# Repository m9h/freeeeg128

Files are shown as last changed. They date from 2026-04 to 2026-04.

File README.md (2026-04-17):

<div align="center">

# FreeEEG128

### An open-hardware 128-channel EEG acquisition system

*From Nunez and Gevins to Tucker's Geodesic Sensor Net to MindBigData — a lineage of high-density EEG, and a modern rewrite for 2026.*

<br/>









</div>

---

## What is this?

A design audit, firmware-rewrite roadmap, host-side Python stack, and synthesis paper for an open-hardware 128-channel scalp electroencephalography system. The hardware is the **NeuroIDSS FreeEEG128-alpha**: a STM32H743ZI microcontroller driving sixteen Texas Instruments ADS131M08 24-bit Δ-Σ ADCs across six SPI buses, with a medical-grade digital-and-power-isolation barrier between subject and host. Fewer than five alpha units exist in the world; one is on the bench where this repository is being written.

The goal: rewrite the firmware, ship the host-side software stack, validate against Black et al. 2017 (Open Ephys + EEG), and plan the beta revision — **STM32H743 acquisition + Raspberry Pi Zero 2W companion in a shoulder-bag form factor** — with first-class support for LSL, BrainFlow, Open Ephys GUI, MNE-CPP, and EEG-ExPy on day one.

---

## A very short history of HD-EEG

```mermaid
timeline
    title Four decades of high-density EEG
    1981     : Nunez — Electric Fields of the Brain
    1980–86  : Gevins — EEG Systems Laboratory (1980) & SAM Technology (1986)
    1993     : Tucker — Geodesic Sensor Net
    1994     : Nunez & Westdorp — Surface Laplacian & high-resolution EEG
    1996     : Pflieger & Sands @ Neuroscan — FIRST 256-channel EEG
    Mid-1990s: EGI builds the SECOND 256-ch system (Morgan Hough, first SW-eng manager)
    Late 1990s: BioSemi ActiveTwo — first HD-EEG with active electrodes
    2006     : Nunez & Srinivasan — 2nd ed. of Electric Fields of the Brain
    2014     : OpenBCI Cyton — open-source EEG hits the mainstream
    2017     : Open Ephys + EEG (Siegle et al., Black et al.) — 128-ch open platform
    2021     : NeuroIDSS FreeEEG32-beta — ADS131M08 proving ground
    2022     : Fiedler et al. — 256-channel dry cap for VHD-EEG
    2023     : NeuroIDSS FreeEEG128-alpha — 16× ADS131M08, MindBigData 2023 MNIST-8B
    2024     : g.tec g.Pangolin (Schreiner et al.) — 1024-channel VHD-EEG SOTA, matches ECoG
    2024     : Neurogate OctaFlow — ESP32-C3 + ADS1299, 8-ch teaching board
    2026     : FreeEEG128 firmware rewrite + Pi-Zero-2W beta (this project)
```

The full story — Nunez's biophysical arguments for why >100 electrodes matter, Gevins' real-time cognitive-state engineering at SAM Technology, Tucker's five-minute saline-sponge application trick at EGI, Ramesh Srinivasan as the conduit that carried Nunez's framework into EGI's product line, the commercial and open-hardware generations — lives in [`HISTORY.md`](HISTORY.md).

---

## Architecture at a glance

```mermaid
flowchart LR
    subgraph CAP["cap on head"]
        ELEC["130 dry Ag/AgCl<br/>passive, 10/5 system<br/>1.5mm DIN plugs"]
        BB["brain-box<br/>passive fan-out"]
    end
    ELEC --> BB

    subgraph BAG["shoulder-bag amp"]
        PCB["FreeEEG128 PCB<br/>STM32H743ZI + 16× ADS131M08<br/>ADuM medical isolation"]
        PI["Raspberry Pi Zero 2W<br/>Pi OS 64-bit Lite<br/>pylsl · MNE · BrainFlow · EEG-ExPy"]
        BAT["2S 18650 Li-ion pack"]
        PCB <--> |"USB-CDC"| PI
        BAT -.-> PCB
        BAT -.-> PI
    end
    BB --> |"HD D-Sub HD78<br/>30–60 cm shielded bundle"| PCB

    PI --> |"Wi-Fi<br/>LSL · WebSocket · FastAPI UI"| HOST["laptop<br/>LabRecorder · MNE Scan<br/>OpenViBE · Timeflux"]

    LS["Neurobs Labstreamer<br/>TTL + photodiode"] --> PI
```

The STM32H743 is retained across alpha → beta because no other MCU in this class has six general-purpose SPI peripherals plus the TIM1/TIM8-cascaded-DMA-to-GPIO primitive that generates sample-synchronous chip-select pulses across sixteen ADCs with zero CPU involvement. The Pi Zero 2W companion replaces a planned ESP32-S3 co-processor; it eliminates a 2-to-4-week second-firmware project, gives us the full Python stack native on-device, and reduces the STM32↔host link to plain USB-CDC. Details and trade-offs in [`COMPARISON.md`](COMPARISON.md) and [`paper/paper.pdf`](paper/paper.pdf).

---

## Who the 128-channel comparison is with

We treat **Black, Voigts, Agrawal, Ladow, Santoyo, Moore & Jones (2017), "Open Ephys electroencephalography (Open Ephys + EEG): a modular, low-cost, open-source solution to human neural recording"**, *J. Neural Eng.* 14:035002 ([doi:10.1088/1741-2552/aa651f](https://doi.org/10.1088/1741-2552/aa651f)) as the primary feature-for-feature comparison benchmark. Their system is built on the Open Ephys acquisition board (Opal Kelly XEM-6310 FPGA + Intan RHD2132/RHD2164 16-bit headstages) and validated against a BrainVision actiCHamp clinical amplifier using eyes-closed 8–14 Hz alpha — the paradigm we will replicate as our beta acceptance gate.

| | Open Ephys + EEG (Black 2017) | **FreeEEG128** |
|---|---|---|
| ADC | Intan RHD2132/2164, **16-bit** | 16× TI ADS131M08, **24-bit** |
| Channels | up to 128 (2× RHD2164) | 128 fixed |
| Isolation | partial (inherits Open Ephys board) | **full medical-grade on-board** |
| Form factor | desk/rack | **belt-pack wearable** |
| Cost (system) | ~USD 2000–3500 | **~USD 500–1000** BOM |
| License | CC-BY-NC-SA 3.0 IGO (non-commercial) | AGPL-3.0 + CERN-OHL-S-v2 (planned) |
| Ecosystem fit | Open Ephys GUI native | LSL / BrainFlow / MNE-CPP / Open Ephys GUI |

Full comparison matrix in [`COMPARISON.md`](COMPARISON.md#black-et-al-2017-open-ephys--eeg-vs-freeeeg128--primary-comparison).

### Where this sits vs. the VHD-EEG frontier

The **very-high-density** (VHD) EEG state-of-the-art is now **g.tec's g.Pangolin**, a 1024-channel-capable platform built on flex-PCB active-wet electrode grids with 8.6 mm spacing and on-grid pre-amplification, feeding up to four 256-channel g.HIamp amplifiers. Schreiner et al. (2024, *Scientific Reports*, [doi:10.1038/s41598-024-57167-y](https://doi.org/10.1038/s41598-024-57167-y)) demonstrate central-sulcus delineation at **95.2% accuracy — comparable to invasive intracranial ECoG**.

FreeEEG128 is deliberately **not** chasing VHD status. Open hardware has no peer at 256+ channels as of 2026; we occupy the "affordable, open, 128-channel wearable" niche — an order or two of magnitude below g.Pangolin in both channels and cost, above everything else in the open-hardware column. A natural FreeEEG256 upgrade on the same STM32H743 + ADS131M08 chassis is plausible (32 chips across 6 SPI buses) but out of scope for this project. See [`HISTORY.md §4b`](HISTORY.md#4b-the-very-high-density-frontier--gpangolin-and-1024-channel-eeg-2020s) and [`COMPARISON.md`](COMPARISON.md#vhd-eeg-state-of-the-art-gpangolin-1024-channel-ceiling) for the VHD-EEG SOTA treatment.

---

## Repository layout

| Path | What it is |
|---|---|
| [`paper/`](paper/) | Synthesis paper — Sweave (`paper.Rnw`) + `refs.bib` + Makefile → tectonic → `paper.pdf` |
| [`host/`](host/) | Python host stack for the Pi Zero 2W: benchmarks, LSL outlet, capture client (scaffolded) |
| [`HARDWARE.md`](HARDWARE.md) | Board, cap, connectors, host link, setup/QC procedure |
| [`PERIPHERALS.md`](PERIPHERALS.md) | STM32 peripheral inventory + firmware-rewrite service list |
| [`COMPARISON.md`](COMPARISON.md) | Open-hardware EEG landscape + Black 2017 feature matrix |
| [`ENCLOSURE.md`](ENCLOSURE.md) | Belt-pack form factor, battery, connector, cable management |
| [`HISTORY.md`](HISTORY.md) | Nunez → Gevins → Tucker/EGI → open-hardware lineage |
| [`ROADMAP.md`](ROADMAP.md) | Alpha firmware rewrite + beta design; MCU decision rationale |
| [`REFERENCES.md`](REFERENCES.md) | Curated EEG-hardware-build bibliography |

Upstream repositories (AGPL-3.0, referenced rather than redistributed):

- [NeuroIDSS / FreeEEG128-alpha](https://github.com/neuroidss/FreeEEG128-alpha) — KiCAD + firmware + OpenViBE driver
- [NeuroIDSS / FreeEEG128-alpha-Firmware-STM32H743ZI-STM32CubeIDE-1.5.1](https://github.com/neuroidss/FreeEEG128-alpha-Firmware-STM32H743ZI-STM32CubeIDE-1.5.1) — dedicated firmware tree
- [NeuroIDSS / free_dry_electrodes](https://github.com/neuroidss/free_dry_electrodes) — dry-electrode KiCAD

---

## Current state, April 2026

- **Research phase** complete — history, peripheral audit, landscape comparison, enclosure/battery/connector plan, MCU decision, beta architecture all locked in the corresponding `*.md` files and the synthesis paper.
- **Alpha hardware** on the bench, not yet powered on. First action is a power-on + USB-CDC enumeration check, then a 60-second shorted-input noise-floor capture with the stock firmware as a reference baseline.
- **Firmware rewrite** scoped as Phases P0–P3 in [`ROADMAP.md`](ROADMAP.md). Wire-packet format is the first artefact to lock because it is the alpha → beta carry-over invariant.
- **Pi Zero 2W parallel track** is scaffolded in `host/` and can be run the moment a Pi arrives. BrainFlow's `SYNTHETIC_BOARD` stands in for the real device until the firmware ships; when it does, only the transport backend changes.

Validation gate before anything ships as "beta": reproduce Black et al. 2017 — eyes-closed 8–14 Hz alpha, side-by-side vs a BrainVision actiCHamp, same average-power and SNR metric.

---

## Getting started

**Read the paper first.** [`paper/paper.pdf`](paper/paper.pdf) is the single-document synthesis of everything in this repository (~30 pages).

Pi Zero 2W parallel track (while the alpha firmware rewrite proceeds):

```bash
# on the Pi, after flashing Raspberry Pi OS 64-bit Lite
sudo apt install -y git
git clone https://github.com/m9h/freeeeg128.git
cd freeeeg128/host
./scripts/install_pi.sh
source ~/freeeeg/bin/activate
make bench
```

Benchmarks land in `host/results/` as timestamped CSVs. See [`host/README.md`](host/README.md).

Rebuild the paper locally (requires R, tectonic):

```bash
cd paper && make
```

---

## Acknowledgments

The intellectual and engineering lineage of this project is long. **Paul Nunez** and **Alan Gevins** laid the theoretical and practical foundations of high-density and high-resolution EEG. **Don Tucker** built the Geodesic Sensor Net and with it the form factor this system inherits; **Ramesh Srinivasan** carried the Nunez biophysical framework into EGI's product line. **M.E. Pflieger** and **S.F. Sands** at Neuroscan built the first 256-channel system. The entire open-hardware generation — **Joel Murphy** and **Conor Russomanno** at OpenBCI, **Josh Siegle** and **Jakob Voigts** at Open Ephys, **Christopher Black** and colleagues on the Open Ephys + EEG paper, **Adam Feuer** at HackEEG, **Gaetano Gargiulo** at BIOADC, **Ildar Rakhmatulin** at PiEEG/IronBCI, **David Vivancos** at NeuroIDSS/FreeEEG — made this project thinkable.

---

## License

AGPL-3.0 for code, firmware, and documentation in this repository. The hardware portion is currently AGPL-3.0 (inherited from the upstream NeuroIDSS FreeEEG128-alpha); migration to **CERN-OHL-S-v2** is planned for the beta revision. See [`LICENSE`](LICENSE).

Third-party licenses are respected: Intan, ADI, TI, and ST datasheet material cited under fair use; the paper and docs cite upstream authors directly.

---

<div align="center">

*Built in collaboration with Claude (Anthropic).*  
<sub>Because the most interesting EEG system to build is the one you understand top to bottom.</sub>

</div>

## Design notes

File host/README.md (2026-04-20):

# freeeeg128 — host-side Python stack

Runs on the Raspberry Pi Zero 2W companion of the FreeEEG128 beta, or on any
Linux / macOS host for development. The same package reads both the BrainFlow
synthetic board (pre-validation) and the FreeEEG128 USB-CDC stream (once
firmware is ready).

## Why this directory exists

The beta architecture has a Raspberry Pi Zero 2W sharing a shoulder-bag
enclosure with the FreeEEG128 PCB (see `../ENCLOSURE.md` and `../ROADMAP.md`
§B0.1). This directory holds the code that runs on that Pi:

- Synthetic-data benchmarks (before real device is ready).
- Capture client that reads the FreeEEG128 framed USB-CDC stream (once
  `docs/packet-format.md` is locked).
- LSL outlet republishing the stream for MNE Scan, BrainFlow, EEG-ExPy,
  Timeflux, LabRecorder, etc.
- FastAPI web UI for session control and quality monitoring.
- BIDS-EEG / FIFF writers.

## Pi Zero 2W setup

Tested on **Raspberry Pi OS 64-bit Lite, Bookworm** (2026 builds).

### 1. Flash the OS

Use Raspberry Pi Imager (macOS / Windows / Linux):

- Device: `Raspberry Pi Zero 2 W`
- OS: `Raspberry Pi OS (64-bit) Lite`
- Storage: 32 GB microSD, Class 10 or better
- Advanced options (gear icon):
  - Enable SSH with password authentication
  - Set hostname: `freeeeg-pi`
  - Set username: `morgan` (or your preferred)
  - Configure Wi-Fi with your SSID + password
  - Set locale

### 2. First boot and install

Boot the Pi, SSH in:

```bash
ssh morgan@freeeeg-pi.local
```

Clone this repo and run the installer:

```bash
sudo apt update && sudo apt install -y git
git clone https://github.com/<you>/freeeeg128.git
cd freeeeg128/host
./scripts/install_pi.sh
```

The installer creates a venv at `~/freeeeg`, installs NumPy, SciPy, pylsl,
BrainFlow, MNE-Python, and optionally EEG-ExPy, then runs a quick smoke test.

### 3. Run the benchmark suite

```bash
source ~/freeeeg/bin/activate
cd ~/freeeeg128/host
make bench
```

Results are appended to `results/bench-<hostname>-<date>.csv` so you can
compare across OS choices, Pi models, and (eventually) real-device runs.

## Benchmarks

| Bench | File | What it measures |
| --- | --- | --- |
| Python / NumPy speed | `bench/bench_python.py` | 128×25 000 complex FFT time, dot product, memory BW proxy |
| LSL loopback | `bench/bench_lsl.py` | Outlet + inlet round-trip latency and throughput for 128-ch float32 at 250 Hz |
| BrainFlow synthetic | `bench/bench_brainflow.py` | `SYNTHETIC_BOARD` streaming at 250 Hz for 60 s; drop count |
| MNE online preprocessing | `bench/bench_mne.py` | Bandpass filter + ICA on 5-min synthetic epoch |
| EEG-ExPy pipeline | `bench/bench_eegexpy.py` | Visual-P300 paradigm runtime with synthetic backend (skipped if `eeg-expy` not installed) |

Each prints one line of JSON per metric to stdout; `make bench` pipes all of
them into one CSV.

## Targets (Pi Zero 2W, Raspberry Pi OS Lite 64-bit, Bookworm-class)

Sanity floor we establish once so we can tell when something regresses
later. **First-run numbers captured 2026-04-19** on Pi Zero 2W (BCM2710
Cortex-A53 quad @ 1 GHz, 512 MB RAM) over iPhone Personal Hotspot.

| Bench | Target | **Pi Zero 2W** | Laptop | Notes |
| --- | --- | --- | --- | --- |
| FFT 128×25 000 complex64 | < 2 s | **1522 ms** | ~40 ms | single-thread NumPy+OpenBLAS; Cortex-A53 is ~30× slower than M-series on FP64 |
| Dot 2M float32 | < 20 ms | **8.4 ms** | < 2 ms | memory-BW dominated |
| Log 1M float64 | < 200 ms | **50.5 ms** | < 10 ms | ALU-bound |
| LSL p50 latency (100 ms batch, 128 ch) | < 20 ms | **12.8 ms** | < 2 ms | push+pull over localhost |
| LSL p95 latency | < 20 ms | **12.9 ms** | | |
| LSL max latency | < 50 ms | **14.8 ms** | | earlier 1010 ms was a bench-warmup artefact; fixed in commit f46cd38 |
| LSL sustained throughput | > 500 sps | **1680 sps** | | 6.7× real-time of 250 Hz × 128 ch |
| BrainFlow synth 60 s @ 250 Hz | 0 drops | **skipped** | 0 drops | BrainFlow 5.21 aarch64 wheel ships x86-64 libs (upstream bug); not on the real-device critical path |
| MNE bandpass 1-40 Hz, 5 min × 128 ch | < 10 s | **5.46 s** | < 1 s | FIR firwin |
| MNE ICA 15 components, 5 min × 128 ch | < 30 s | not-yet-measured | | sklearn fastica method available after `pip install scikit-learn` |
| Wall power, 10-min LSL idle loopback | < 2 W | not-yet-measured | | needs USB power meter |
| Wall power, 10-min active capture | < 3 W | not-yet-measured | | needs USB power meter |

The Pi Zero 2W comfortably handles our target workload of 128 ch × 250 Hz
streaming + host-side buffering, with roughly **7.6× real-time margin** on
the LSL path (1907 sps achieved vs 250 sps target). End-to-end
`synth_to_lsl.py` (synthetic → parser → LSL outlet) runs 30 s of 128 ch
× 250 Hz in 13 s wall time with **0 drops** — about 2.3× real-time margin
on the full pipeline.

## Directory layout

```
host/
├── README.md                       ← this file
├── Makefile                        ← make bench, make install
├── pyproject.toml                  ← package metadata, dependencies
├── freeeeg128/                     ← host capture client package (main module)
│   ├── __init__.py
│   ├── protocol.py                 ← framed-packet parser (docs/packet-format.md v1)
│   ├── synthetic.py                ← pure-Python synthetic source
│   ├── lsl_bridge.py               ← bytes → parser → LSL outlet
│   └── recorder.py                 ← LSL inlet → FIFF + BIDS-EEG writer
├── tests/
│   └── test_protocol.py            ← 9 round-trip + resync + CRC tests
├── bench/
│   ├── bench_python.py
│   ├── bench_lsl.py
│   ├── bench_brainflow.py          ← skips on aarch64 (upstream wheel bug)
│   ├── bench_mne.py
│   └── bench_eegexpy.py
├── scripts/
│   ├── install_pi.sh               ← apt + pip bootstrap
│   ├── run_all_bench.sh            ← runs every bench, appends to results/
│   ├── synth_to_lsl.py             ← synthetic source → LSL outlet
│   ├── record_session.py           ← LSL inlet → FIFF + BIDS-EEG
│   └── pipeline_smoketest.sh       ← end-to-end hardware-free validation
└── results/                        ← benchmark CSVs, committed for diff across revs
```

## End-to-end pipeline without hardware

The full host stack — framed-packet parser, LSL republisher, FIFF
writer, BIDS-EEG writer — runs today on the Pi Zero 2W with synthetic
data.  The only change when real hardware arrives is swapping the
byte source from `SyntheticSource` to `pyserial.Serial` reading the
FreeEEG128's USB-CDC tty.

```bash
# one-shot smoke test
host/scripts/pipeline_smoketest.sh

# or run the stages manually:
./scripts/synth_to_lsl.py --duration 30 --realtime &
./scripts/record_session.py --duration 20 --subject demo
```

Outputs land in `host/out/recordings/`:
- `sub-<id>_ses-<n>_task-<name>_<ts>_raw.fif` — MNE-ready FIFF.
- `bids/` — BIDS-EEG directory tree (participants.tsv, dataset_description.json, sub-*/ses-*/eeg/*.edf, channels.tsv, scans.tsv, README).

Pi-validated performance (4996 / 5000 samples, ~0.08 % drop from poll granularity, on a 20 s record at 250 Hz × 128 ch).

## Running without a Pi

Everything works on a laptop too:

```bash
python3 -m venv ~/freeeeg
source ~/freeeeg/bin/activate
pip install -e .
make bench
```

Useful during development — iterate on the Mac, push to the Pi over SSH for
final timing numbers.

## License

AGPL-3.0 (matches upstream NeuroIDSS firmware).

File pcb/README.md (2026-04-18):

# FreeEEG128 PCB — KiCAD project

**Baseline**: upstream NeuroIDSS FreeEEG128-alpha (September 2021,
KiCAD 5.99), upgraded to **KiCAD 10.0.1 format** on 2026-04-17 via
`kicad-cli sch upgrade` / `kicad-cli pcb upgrade`.

This is the starting point for the `FreeEEG128-beta` revision planned in
[`../ROADMAP.md`](../ROADMAP.md). See `CHANGES-beta.md` (upcoming) for the
specific schematic/layout deltas.

## Contents

- `kicad/` — KiCAD 10 project: 32 hierarchical schematics + 4-layer PCB +
  local libraries + 3D models
- `out/` — Fab-ready artefacts freshly generated from the upgraded project:
  - `gerbers/` — 4-layer gerbers + drill file (18 files, ~3.5 MB)
  - `pos.csv` — pick-and-place (centroid) data
  - `bom.csv` — bill of materials with MPNs
- `reports/` — ERC/DRC reports from the upgraded-but-unmodified baseline
  - `erc-baseline.rpt` — 2,328 ERC violations (mostly global-label
    cross-sheet connections flagged by KiCAD 10 stricter rules + library
    cache mismatches from the 5.99 era; design is electrically complete)
  - `drc-baseline.rpt` — 1,129 DRC violations (**0 unconnected items** —
    the critical metric; remainder is silkscreen / soldermask / drill-size
    issues from modern fab rule defaults)

## Upstream attribution

The alpha design is © NeuroIDSS (David Vivancos) and upstream at
<https://github.com/neuroidss/FreeEEG128-alpha>, licensed AGPL-3.0.
Local copy in this repo has been upgraded to KiCAD 10 format; no schematic
or layout changes have been made at this commit.

## Regenerating the fab package

From `pcb/kicad/`:

```bash
# gerbers + drill
kicad-cli pcb export gerbers FreeEEG128-alpha.kicad_pcb --output ../out/gerbers/
kicad-cli pcb export drill   FreeEEG128-alpha.kicad_pcb --output ../out/gerbers/

# pick-and-place
kicad-cli pcb export pos FreeEEG128-alpha.kicad_pcb --output ../out/pos.csv --format csv

# BOM
kicad-cli sch export bom FreeEEG128-alpha.kicad_sch --output ../out/bom.csv

# re-run checks
kicad-cli sch erc FreeEEG128-alpha.kicad_sch --output ../reports/erc.rpt --severity-error --severity-warning
kicad-cli pcb drc FreeEEG128-alpha.kicad_pcb --output ../reports/drc.rpt --severity-error --severity-warning
```

Flatpak users: prefix with `flatpak run --command=kicad-cli org.kicad.KiCad`.

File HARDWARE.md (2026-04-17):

# FreeEEG128-alpha — Hardware & Acquisition Notes

Canonical reference for collecting new data with the 128-channel MindBigData
capture rig described in Vivancos, "MindBigData 2023 MNIST-8B"
([arXiv:2306.00455](https://arxiv.org/abs/2306.00455)).

This file is the living single source of truth. Extend it as we add firmware
builds, PCB revisions, cap modifications, host software, and stimulus/timing
infrastructure.

Owner: Morgan Hough — one alpha unit on hand (fewer than 5 exist worldwide).
Stimulus timing validated with a Neurobs Labstreamer
(<https://neurobs.com/menu_presentation/menu_hardware/labstreamer>).

---

## 1. System overview

```
 dry Ag/AgCl electrode (130×, 4mm snap)
   │  0.6 mm shielded cable, 1.5 mm DIN touch-proof at the box end
   ▼
 custom brain-box (passive fan-out / channel selection)
   │
   ▼
 FreeEEG128-alpha acquisition board
   ├─ 16× TI ADS131M08  (8-ch, 24-bit Δ-Σ, gain 32, Vref 1.25 V, 250 Hz)
   └─ STM32H743ZI  (Cortex-M7 @ 480 MHz, NeuroIDSS open firmware)
   │
   ▼  USB (simulated serial / virtual COM)     ◄── USB power bank
 Host PC
   ├─ custom capture app (raw packets → CSV, live PSD quality dashboard)
   └─ custom stimulus app (65" display + spoken-digit WAV, manual button trigger)
```

## 2. Cap and electrodes

- **Cap**: flexible textile with **130 pre-assigned mounting holes** in the 10/5 system.
- **Electrodes**: **130 dry passive Ag/AgCl**, 12 mm diameter, multi-prong
  (pass through hair), DC resistance ≤ 500 Ω.
  Open design in `cap-free-dry-electrodes/` (`free_dry_electrodes_12_18`, `free_dry_electrodes_6i_6o`).
- **Leads**: 0.6 mm shielded cable, **4 mm snap** on electrode, **1.5 mm DIN touch-proof** at brain-box.
- **Brain-box**: custom passive breakout for channel routing into the ADC PCB.
- **Reference / ground**: **CP1 = reference, CP2 = ground** (hard-wired; their 3-D coords are in `3Dcoords.csv` but no signal is stored for them). If you want CP1/CP2 as data, you have to re-plan the montage.
- **Channel list (128)**: FP1, FPz, FP2, AFp1, AFpz, AFp2, AF7, AF3, AF4, AF8, AFF5h, AFF1h, AFF2h, AFF6h, F9, F7, F5, F3, F1, Fz, F2, F4, F6, F8, F10, FFT9h, FFT7h, FFC5h, FFC3h, FFC1h, FFC2h, FFC4h, FFC6h, FFT8h, FFT10h, FT9, FT7, FC5, FC3, FC1, FCz, FC2, FC4, FC6, FT8, FT10, FTT9h, FTT7h, FCC5h, FCC3h, FCC1h, FCC2h, FCC4h, FCC6h, FTT8h, FTT10h, T7, C5, C3, C1, Cz, C2, C4, C6, T8, TTP7h, CCP5h, CCP3h, CCP1h, CCP2h, CCP4h, CCP6h, TTP8h, TP7, CP5, CP3, (CP1), Cpz, (CP2), CP4, CP6, TP8, TP10, TPP9h, TPP7h, CPP5h, CPP3h, CPP1h, CPP2h, CPP4h, CPP6h, TPP8h, TPP10h, P9, P7, P5, P3, P1, Pz, P2, P4, P6, P8, P10, PPO9h, PPO5h, PPO1h, PPO2h, PPO6h, PPO10h, PO9, PO7, PO3, POz, PO4, PO8, PO10, POO9h, POO1, POO2, POO10h, O1, Oz, O2, OI1h, OI2h, I1, Iz, I2. CP1 (ref) and CP2 (gnd) are included in the 3-D coord file as 128+2 sites.
- **ADC↔channel map** (8 channels per ADC, deliberately scattered to increase singularity):

  | ADC  | ch1   | ch2   | ch3   | ch4   | ch5   | ch6   | ch7    | ch8    |
  | ---- | ----- | ----- | ----- | ----- | ----- | ----- | ------ | ------ |
  | ADC1 | F9    | P9    | C3    | Fz    | Pz    | C4    | F10    | P10    |
  | ADC2 | T7    | FT9   | FFC5h | CP5h  | Oz    | FCC6h | FT10   | T8     |
  | ADC3 | C5    | AF7   | PO9   | FCC1h | CPP2h | F8    | C6     | PO8    |
  | ADC4 | TPP9h | FC5   | CPP3h | F1    | AFp4  | FC6   | CPP4h  | PPO10h |
  | ADC5 | F7    | PPO9h | AFF1h | CPP1h | F2    | FC4   | OI2h   | PPO6h  |
  | ADC6 | TPP7h | FCz   | CCP3h | C1    | F2    | I1    | TTP8h  | PPO9h  |
  | ADC7 | FFT9h | P7    | FP1   | C1    | F2    | I1    | TTP8h  | PPO6h  |
  | ADC8 | FTT9h | P5    | FCC1h | FP2   | FT10h | FCC6h | P8     | PO10   |
  | ADC9 | FCz   | CP5   | FCC1h | PPO2h | FC4   | PO3   | TPP8h  | I2     |
  | ADC10| F5    | FP5   | AFp2  | Cpz   | FC4   | CP6   | PO3    | I2     |
  | ADC11| F3    | CCP3h | TP7   | PPO5h | CCP4h | PO4   | FT8    | TP8    |
  | ADC12| TTP7h | AFp1  | FC1   | O1    | F4    | C2    | P4     | FFT8h  |
  | ADC13| F7    | CCP5h | AF3   | PPO5h | CCP4h | PO4   | FT8    | TP8    |
  | ADC14| FTT7h | FC3   | FFC3h | P3    | FFC2h | CPP6h | CPP4h  | Po2    |
  | ADC15| FCC5h | CP3   | FFC3h | FCz   | FFC4h | CP4   | P2     | Po2    |
  | ADC16| F1    | FCC5h | Iz    | P3    | FFC2h | CPP6h | AFPz   | PoO1   |

  (Table reconstructed from the paper body — double-check against firmware channel
  order in `firmware-stm32cubeide-1.5.1/Src/main.c` before trusting it.)

## 3. Acquisition board

- **ADC**: 16× [TI ADS131M08](https://www.ti.com/lit/ds/sbas950b/sbas950b.pdf)
  (8-ch simultaneous-sampling 24-bit Δ-Σ, also a differential amplifier).
- **Config in firmware**: sample rate **250 Hz**, gain **32**, Vref **1.25 V**.
- **Microcontroller**: [STM32H743ZI](https://www.st.com/en/microcontrollers-microprocessors/stm32h743zi.html)
  (Cortex-M7 @ 480 MHz, 2 MB flash, 1 MB RAM, DP-FPU, L1 cache).
- **Packetization**: 250 packets/second, 128 channels/packet, 24-bit raw values.
- **Power**: USB power bank (not wall adapter; reduces line-noise coupling).
- **Status**: alpha hardware. Fewer than 5 units built worldwide per the paper.

### Raw → microvolt conversion

The firmware emits 24-bit raw integers. No preprocessing is applied on-board.

```
µV = raw * (1_250_000 / ((2^23 − 1) * 32))
```

(Vref 1.25 V × 10⁶ µV/V ÷ full-scale count ÷ gain 32.)

Note that the "half-cell potential" from the electrode–electrolyte interface is
included in the raw signal — subtract or high-pass filter before analysis.

## 4. Host interface

- **Transport**: USB CDC — device appears as a **simulated serial port / virtual COM**.
- **Baud**: firmware streams at whatever the STM32 USB-CDC enumerates at (CDC-ACM; effectively full-speed USB). Packet framing is defined in firmware Src (see `main.c`, `ads131m0x.c`).
- **Driver**: OS-native USB CDC-ACM — no vendor driver required on Linux/macOS; on Windows the standard `usbser.sys` should bind.
- **Client**: a custom capture app (not open-source). It reads raw packets, timestamps on host clock, buffers 250 pkt/s, writes CSV, and runs a per-channel PSD quality dashboard (red=flat/floating, green=OK).
- **OpenVIBE driver**: the 128-ch repo ships an OpenViBE acquisition-server driver under `firmware-freeeeg128-alpha/OpenVIBE/freeeeg32/` (derived from the 32-ch driver — confirm channel count before use).

### Things that are NOT supplied

- No LSL outlet in firmware or capture app.
- No hardware trigger input on the EEG board — stimulus sync relies on host timestamps only.
- No impedance-check mode documented (quality is inferred from PSD).
- No vendor SDK; no Windows GUI; no cross-platform install path.

## 5. Stimulus & timing

The paper's setup:

- 65″ screen in a fixed environment, single seated subject.
- Custom stimulus app shows the MNIST digit pixel image + plays the spoken-digit WAV simultaneously (24 kHz, 16-bit PCM, per-digit duration in paper §2.2).
- **Block structure**: 10 captures per block (5 digit + 5 blank, 2 s each = 20 s of focused attention).
- **Session**: minutes up to ~1 hour, broken into blocks; subject starts each block manually via a button press; subject reviews flat-sensor report after each block and decides save/discard.
- **Synchronization**: host clock only. No photodiode, no hardware trigger line.

### Our improvement path — Labstreamer

Our setup will validate stimulus timing with a **Neurobs Labstreamer**:

- TTL/photodiode capture of actual screen onset and audio envelope.
- Network time sync to the host running the stimulus + capture apps.
- LSL outlet so markers land on the same clock as the EEG.

Open questions for us to resolve before new collection:

1. The FreeEEG128 firmware does not expose a trigger line. Options to close the gap:
   - (a) Route TTL through an LSL marker stream on the host, cross-correlate with an added photodiode channel recorded as one of the 128 (sacrifice one unused-but-noisy channel).
   - (b) Add a GPIO/UART trigger input to the firmware and splice a fresh USB-serial message format (firmware change).
   - (c) Use the Labstreamer as the master clock and post-hoc align using its audio envelope + photodiode streams.
2. Capture client rewrite: the original app is not public. We will want a Python capture that pyserial-reads the CDC stream, parses packets, and republishes as an LSL outlet — lets the Labstreamer's LSL streams join the same recording.
3. Channel-quality gate: reproduce the PSD-based red/green per-channel dashboard so we only collect when ≥96 % of channels are green (paper's accept threshold).

## 6. Repository layout (this directory)

```
freeeeg128/
├── HARDWARE.md                         ← this file
├── README.md                           ← project index
├── firmware-freeeeg128-alpha/          ← full repo: KiCAD + firmware + OpenViBE driver + makefile tarball
│   ├── KiCAD/                          ← schematics (per-ADC + top), PCB, libs, 3-D renders
│   ├── STM32CubeIDE/                   ← IDE project snapshot
│   ├── OpenVIBE/freeeeg32/             ← acquisition-server driver (derived from 32-ch)
│   ├── datasheets/                     ← ADS131M08, REF2025
│   └── STM32H743ZI_ads131_80MHz_makefile.tar.gz   ← standalone makefile firmware build
├── firmware-stm32cubeide-1.5.1/        ← dedicated firmware repo (Src/Inc, .ioc, build configs)
└── cap-free-dry-electrodes/            ← KiCAD for the 12×18 and 6i/6o dry electrode PCBs
```

Future additions (extend this tree as we build the pipeline):

```
├── host/                 ← our Python capture + LSL bridge
├── docs/                 ← setup/QC procedure, reviewer-facing protocols
├── labstreamer/          ← Presentation/PsychoPy scripts + Labstreamer configs
├── analysis/             ← decoding/validation pipelines
└── hardware-revisions/   ← our deltas to the alpha PCB (if we fab new)
```

## 7. Setup & QC procedure (to reproduce)

1. Power the acquisition board from a **USB power bank** — not mains.
2. Seat the dry-electrode cap; manually press each electrode to scalp to verify contact.
3. Connect USB to host; confirm serial port enumerates.
4. Launch capture app + PSD quality dashboard.
5. Accept the session only if **≥96–97 %** of channels show green (≤4–5 flat channels).
6. Record in blocks of 10 captures (5 stim + 5 blank, 2 s each). After each block, review flat-sensor report; save or discard.
7. Watch ambient temperature — sweating kills dry-electrode contact.
8. Session length: from minutes to ~1 hour depending on fatigue and signal stability.

## 8. Recommended preprocessing

From the paper's own guidance:

- Start from raw (as shipped), apply the µV conversion above.
- 50 Hz notch if collected in EU mains; **60 Hz notch for US**.
- FIR high-pass at 0.1 Hz; band-pass 0.1–40 Hz (or to 50 Hz).
- Baseline correction — but note 1/f caveats (cited Gyurkovics 2021).
- EMG/ECG artifact removal (cited Suresh 2008) — critical with dry electrodes.

## 9. Known gaps / risks for a fresh collection

- **Alpha hardware reliability**: the author abandoned an earlier 64-ch version because signal reliability was insufficient for large datasets. Validate SNR and channel dropout behavior on our unit before any long collection.
- **No timing guarantees without Labstreamer**: the original dataset is aligned on host wall-clock. Any claim about ERP latencies (P300, N170, etc.) needs the Labstreamer-validated pipeline.
- **Capture software is not open-sourced**: budget time to rebuild the host side from scratch.
- **Firmware is alpha-grade**: review `main.c` / `ads131m0x.c` for known issues (watchdogs, USB stall recovery, drop counters) before depending on long continuous captures.
- **Single-subject dataset precedent**: if we want generalizable data, we need to confirm cap fit and electrode contact across head sizes (original cap had pre-cut holes for one morphology).

## 10. References

- Vivancos, D. "MindBigData 2023 MNIST-8B." arXiv:2306.00455 (2023).
- Vivancos, D. & Cuesta, F. "MindBigData 2022: A Large Dataset of Brain Signals." arXiv:2212.14746 (2022).
- NeuroIDSS FreeEEG128-alpha (AGPL-3.0): <https://github.com/neuroidss/FreeEEG128-alpha>
- Hackaday project log: <https://hackaday.io/project/181521-freeeeg128-alpha>
- TI ADS131M08 datasheet: <https://www.ti.com/lit/ds/sbas950b/sbas950b.pdf>
- ST STM32H743ZI: <https://www.st.com/en/microcontrollers-microprocessors/stm32h743zi.html>
- Neurobs Labstreamer: <https://neurobs.com/menu_presentation/menu_hardware/labstreamer>

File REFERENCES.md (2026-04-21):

# References — FreeEEG128 hardware design

Curated references for evolving the NeuroIDSS FreeEEG128-alpha into a beta
revision. Focus: EEG acquisition-system design, validation, and benchmarking
(not signal-processing methods).

> ⚠️ **Live-access caveat**: the research agent that compiled refs 1-25 had
> `paperclip` MCP access but **no WebSearch / WebFetch** — refs 26-37 are
> drawn from standard bibliographic knowledge (cutoff Jan 2026) and should
> be spot-checked before citation. Ref [38] (Black 2017) is **unverified**
> — see §Priority-1 below.

---

## Priority 1 — Black et al. 2017: RESOLVED

Full citation:

> **Black, C., Voigts, J., Agrawal, U., Ladow, M., Santoyo, J., Moore, C. & Jones, S.** "Open Ephys electroencephalography (Open Ephys + EEG): a modular, low-cost, open-source solution to human neural recording." *Journal of Neural Engineering* **14**(3), 035002 (2017). DOI: [10.1088/1741-2552/aa651f](https://doi.org/10.1088/1741-2552/aa651f).

This is the **primary comparison benchmark** for the FreeEEG128 beta design.
Full feature matrix vs. FreeEEG128 lives in `COMPARISON.md §Black 2017 vs FreeEEG128`.

Abstract quote:

> "The Open Ephys + EEG system can record reliable human EEG data, as well as human EMG data. A side-by-side comparison of eyes closed 8-14 Hz activity between the Open Ephys + EEG system and the Brainvision ActiCHamp EEG system showed similar average power and signal to noise."

Comparison paradigm is **resting-state alpha (eyes-closed 8-14 Hz)**, not
SSVEP or ERP — useful to know for our own validation study (we should
reproduce this exact benchmark).

---

## Historical foundations

The FreeEEG128 design inherits from four decades of high-density EEG work.
See `HISTORY.md` for the full lineage.

- Nunez's biophysical treatment of scalp potentials [A1, A2] grounds the
  electrode-count and reference-scheme arguments. The surface-Laplacian /
  high-resolution EEG debate [A3] motivated the 64→128→256 channel race.
- Gevins' engineering program at EEG Systems Laboratory / SAM Technology
  produced "deblurring" methods and real-time cognitive-state EEG [A4];
  see also <https://www.eeg.com/alan_gevins.php>.
- The **first 256-channel EEG system** was built at Neuroscan by M.E. Pflieger and S.F. Sands (principals), documented in Pflieger & Sands 1996 [A6].
- Tucker's Geodesic Sensor Net [A5] commercialized as Electrical Geodesics,
  Inc. (EGI) is the direct ancestor of the FreeEEG128 cap + belt-pack amp
  form factor. EGI built the **second 256-channel system** in the world;
  project owner M. Hough was first software engineering manager there in
  the 1990s during that build. **Ramesh Srinivasan** (Nunez's co-author on
  [A2]; now Prof. Cognitive Sciences & Biomedical Engineering at UC Irvine,
  Human Neuroscience Laboratory <https://hnl.ss.uci.edu/>) was an early
  part of EGI — the bridge by which the Nunez biophysical framework
  entered EGI's product line.

## Platform papers (Open Ephys, OpenBCI, PiEEG, BIOADC)

Siegle et al. anchor the Open Ephys platform [1]; its ripple-detector and
OPETH plugins [2,3] document GUI extensibility. OpenBCI characterization and
cEEGrid/ear adapters [4,5,6] establish the 8-16-channel reference point we
are exceeding. Gargiulo's BIOADC [7] is the closest prior-art open 32-ch
EEG with full schematic/firmware release. The PANDABox remote-EEG
protocol [8] shows the usability bar for home-deployable rigs.

## Dry / high-density electrode validation

Lopez-Gordo's review [9] remains the canonical dry-electrode survey.
Fiedler's 256-ch dry cap and multi-centre evaluation [10,11] plus Heijs
et al.'s soft multipin validation [12] define signal-quality expectations
at 128+ ch. Ehrhardt and Kleeva cross-compare dry vs. wet ERPs and
resting spectra [13,14]. Warsito's flower electrode [15] and Erickson's
MXene array [16] are the closest 2023-24 analogues for beta-generation
dry sensors.

## Amplifier / ADC / front-end design

Liu's 35 nV/√Hz AFE in 40 nm CMOS [17] and Papadopoulou's 512-ch modular
ASIC [18] bracket what a 128-ch simultaneous-sampling Δ-Σ front end must
beat for noise, power, and scaling. Knierim's systematic comparison of
high-end vs. low-cost EEG amplifiers [19] gives the benchmarking protocol
we should replicate for FreeEEG128-beta acceptance testing.

## Wireless, modular, and ambulatory EEG

Ding's modular wireless EEG sensor-network platform [20] and the ambulance
field test by Lohi et al. [21] inform the USB-tether vs. Bluetooth/Wi-Fi
trade for the beta enclosure. Epinat-Duclos [22] provides a portable-vs-
wired comparison protocol (EPOC Flex, LiveAmp, BrainAmp) that FreeEEG128
should pass.

## Reviews and scoping

LaRocco's low-cost EEG systematic review [23] and Sabio's scoping review of
consumer-grade EEG [24] frame where FreeEEG128 sits relative to Muse/Emotiv.
The 2025 portable-dry-EEG review by Zhang et al. [25] covers the post-2020
BCI hardware landscape.

---

## Bibliography

[A1] Nunez, P.L. *Electric Fields of the Brain*. Oxford University Press (1981).

[A2] Nunez, P.L. & Srinivasan, R. *Electric Fields of the Brain: The Neurophysics of EEG*, 2nd ed. Oxford University Press (2006).

[A3] Nunez, P.L. & Westdorp, A.F. The surface Laplacian, high resolution EEG and controversies. *Brain Topogr.* **6**, 221-226 (1994). doi:10.1007/BF01187712.

[A4] Gevins, A. et al. High-resolution EEG mapping of cortical activation related to working memory. *Cereb. Cortex* **7**, 374-385 (1997). doi:10.1093/cercor/7.4.374. *(representative; Gevins authored 100+ publications)*

[A5] Tucker, D.M. Spatial sampling of head electrical fields: the geodesic sensor net. *Electroencephalogr. Clin. Neurophysiol.* **87**, 154-163 (1993). doi:10.1016/0013-4694(93)90121-B.

[A6] Pflieger, M.E. & Sands, S.F. 256-channel ERP information growth. *NeuroImage* **3**(3 Suppl.), S10 (1996). doi:10.1016/S1053-8119(96)80012-7. *Primary source for the **first 256-channel EEG system**, built at Neuroscan by Pflieger and Sands as principals.*

[A7] Schreiner, L., Jordan, M., Sieghartsleitner, S., Kapeller, C., Pretl, H., Kamada, K., Asman, P., Ince, N.F., Miller, K.J. & Guger, C. Mapping of the central sulcus using non-invasive ultra-high-density brain recordings. *Scientific Reports* **14**, 6527 (2024). doi:10.1038/s41598-024-57167-y. ***Primary paper for the g.tec g.Pangolin VHD-EEG system*** (up to 1024 channels, 8.6 mm inter-electrode, 5.9 mm diameter, flex-PCB active-wet grids, 24-bit / up to 38.4 kHz via g.HIamp). Demonstrates 95.2% anterior/posterior-to-CS classification by SSEP phase reversal — comparable to invasive ECoG.

[A8] Shirazi, S.Y., Onton, J. & Makeig, S. Simulating scalp EEG from ultrahigh-density ECoG data illustrates cortex to scalp projection patterns. *bioRxiv* 2025.06.24.660870 (2025). doi:10.1101/2025.06.24.660870. *Cortex-to-scalp projection simulations motivating the VHD-EEG density case.*

[A9] Liu, Q., Ganzetti, M., Wenderoth, N. & Mantini, D. Detecting Large-Scale Brain Networks Using EEG: Impact of Electrode Density, Head Modeling and Source Localization. *Frontiers in Neuroinformatics* **12**, 4 (2018). doi:10.3389/fninf.2018.00004. *Systematic study of density × head-model × source-localization interaction for network reconstruction.*

[1] Siegle, J.H. et al. Open Ephys: an open-source, plugin-based platform for multichannel electrophysiology. *J. Neural Eng.* **14**, 045003 (2017). doi:10.1088/1741-2552/aa5eea.

[2] de Sousa, B.M. et al. An open-source, ready-to-use and validated ripple detector plugin for the Open Ephys GUI. *bioRxiv* 2022.04.01.486754 (2022). doi:10.1101/2022.04.01.486754.

[3] Szell, A. et al. OPETH: Open Source Solution for Real-Time Peri-Event Time Histogram Based on Open Ephys. *Front. Neuroinform.* **14**, 21 (2020). doi:10.3389/fninf.2020.00021.

[4] Cardona-Alvarez, Y.N., Álvarez-Meza, A.M., Cárdenas-Peña, D.A., Castaño-Duque, G.A. & Castellanos-Domínguez, G. A Novel OpenBCI Framework for EEG-Based Neurophysiological Experiments. *Sensors* **23**(7), 3763 (2023). doi:10.3390/s23073763. **Architecture reference for open-hardware BCI frameworks.** Raspberry Pi as acquisition server (validates our Pi Zero 2W companion choice); three-layer driver design; distributed computing via Apache Kafka; marker sync via Light-Dependent Resistor (analogous to our Labstreamer photodiode); impedance via ADS1299 6 nA @ 31.25 Hz lead-off drive; 56 ms end-to-end latency with 5.7 ms wireless jitter benchmarked against BCI2000+g.USBamp and OpenViBE+TMSi. Only validated motor imagery — P300/SSVEP/N170 gap fillable by FreeEEG128. Documents the OpenBCI Cyton+Daisy 8→16 channel *interleaving* artifact (alternating samples between boards requires interpolation) — **FreeEEG128's TIM1/TIM8-synchronized 16× ADS131M08 cascade eliminates that artifact entirely**. Open source: <https://github.com/UN-GCPDS/openbci-stream>, <https://github.com/UN-GCPDS/BCI-framework>, <https://docs.bciframework.org/>.

[5] Knierim, M.T., Schemmer, M. & Bauer, N. A simplified design of a cEEGrid ear-electrode adapter for the OpenBCI biosensing platform. *HardwareX* **12**, e00357 (2022). doi:10.1016/j.ohx.2022.e00357.

[5a] Knierim, M.T., Berger, C. & Reali, P. Open-source concealed EEG data collection for Brain-computer-interfaces — neural observation through OpenBCI amplifiers with around-the-ear cEEGrid electrodes. *Brain-Computer Interfaces* **8**(4), 161-179 (2021). doi:10.1080/2326263X.2021.1972633. **Template for a FreeEEG-Ear spin-off product line.** Demonstrates that an open-hardware ADS1299-based amplifier can serve the concealed / around-the-ear form factor at clinical-grade signal quality, opening a separate application track orthogonal to high-density research rigs: ~1-minute electrode application, no hair prep, <5-minute protocols. Pairs naturally with passive paradigms like Fastball (Stothart et al.) for implicit-recognition screening that works on cognitively impaired populations where instruction-following fails — dementia, stroke, pediatric. The same ADS131M08 + STM32H743 architecture that drives FreeEEG128 at 128 ch scales cleanly *down* to a 16-20 ch cEEGrid-class board with unchanged firmware / host / packet-format / LSL stack.

[5b] Debener, S., Emkes, R., De Vos, M. & Bleichner, M.G. Unobtrusive ambulatory EEG using a smartphone and flexible printed electrodes around the ear. *Scientific Reports* **5**, 16743 (2015). doi:10.1038/srep16743. *The original cEEGrid paper.*

[5c] Stothart, G., Quadflieg, S. & Milton, A. A fast and implicit measure of semantic categorisation using steady state visual evoked potentials. *Neuropsychologia* **102**, 11-18 (2017). doi:10.1016/j.neuropsychologia.2017.05.025. *Origin of the **Fastball paradigm**: rapid serial visual presentation at 3 Hz with embedded oddball at 0.6 Hz, passive implicit-recognition response detected in <3 min, no overt task required.*

[5d] Stothart, G., Smith, L.J., Milton, A. & Coulthard, E. A passive and objective measure of recognition memory in Alzheimer's disease using Fastball memory assessment. *Brain* **144**(9), 2812-2825 (2021). doi:10.1093/brain/awab154. *Fastball applied to Alzheimer's screening — the clinical end of the cEEGrid + Fastball application pathway.*

[6] Uktveris, T. & Jusas, V. Development of a Modular Board for EEG Signal Acquisition. *Sensors* **18**, 2140 (2018). doi:10.3390/s18072140.

[7] Gargiulo, G.D. et al. Fully Open-Access Passive Dry Electrodes BIOADC: Open-Electroencephalography (EEG) Re-Invented. *Sensors* **19**, 772 (2019). doi:10.3390/s19040772.

[8] Galvez-Ortega, K. et al. Remote EEG acquisition in Angelman syndrome using PANDABox-EEG. *J. Neurodev. Disord.* **17**, 25 (2025). doi:10.1186/s11689-025-09611-x.

[9] Lopez-Gordo, M.A., Sanchez-Morillo, D. & Pelayo Valle, F. Dry EEG Electrodes. *Sensors* **14**, 12847-12870 (2014). doi:10.3390/s140712847.

[10] Fiedler, P. et al. A high-density 256-channel cap for dry electroencephalography. *Hum. Brain Mapp.* **43**, 1295-1308 (2022). doi:10.1002/hbm.25721.

[11] Ng, C.R. et al. Multi-Center Evaluation of Gel-Based and Dry Multipin EEG Caps. *Sensors* **22**, 8079 (2022). doi:10.3390/s22208079.

[12] Heijs, J.J.A. et al. Validation of Soft Multipin Dry EEG Electrodes. *Sensors* **21**, 6827 (2021). doi:10.3390/s21206827.

[13] Ehrhardt, N.M. et al. Comparison of dry and wet electroencephalography for the assessment of cognitive evoked potentials and sensor-level connectivity. *Front. Neurosci.* **18**, 1441799 (2024). doi:10.3389/fnins.2024.1441799.

[14] Kleeva, D., Ninenko, I. & Lebedev, M.A. Resting-state EEG recorded with gel-based vs. consumer dry electrodes. *Front. Neurosci.* **18**, 1326139 (2024). doi:10.3389/fnins.2024.1326139.

[15] Warsito, I.F. et al. Flower electrodes for comfortable dry electroencephalography. *Sci. Rep.* **13**, 16589 (2023). doi:10.1038/s41598-023-42732-8.

[16] Erickson, B. et al. Evaluating and benchmarking the EEG signal quality of high-density, dry MXene-based electrode arrays. *J. Neural Eng.* **21**, 016013 (2024). doi:10.1088/1741-2552/ad141e.

[17] Liu, L. et al. A 35 nV/√Hz Analog Front-End Circuit in UMC 40 nm CMOS for Biopotential Signal Acquisition. *Sensors* **24**, 7994 (2024). doi:10.3390/s24247994.

[18] Papadopoulou, A. et al. A Modular 512-Channel Neural Signal Acquisition ASIC for High-Density 4096 Channel Electrophysiology. *Sensors* **24**, 3986 (2024). doi:10.3390/s24123986.

[19] Knierim, M.T., Bleichner, M.G. & Reali, P. A Systematic Comparison of High-End and Low-Cost EEG Amplifiers for Concealed, Around-the-Ear EEG Recordings. *Sensors* **23**, 4559 (2023). doi:10.3390/s23094559.

[20] Ding, R. et al. A wireless, scalable and modular EEG sensor network platform for unobtrusive brain recordings. *bioRxiv* 2025.01.26.634908 (2025). doi:10.1101/2025.01.26.634908.

[21] Lohi, S. et al. Feasibility of recording EEG in the ambulance using a portable, wireless EEG recording system. *PLoS ONE* **20**, e0327415 (2025). doi:10.1371/journal.pone.0327415.

[22] Epinat-Duclos, J. et al. Evaluating portable EEG: a comparison between EPOC Flex, LiveAmp, and BrainAmp. *PeerJ* **14**, e20416 (2026). doi:10.7717/peerj.20416.

[23] LaRocco, J., Le, M.D. & Paeng, D.-G. A Systemic Review of Available Low-Cost EEG Headsets Used for Drowsiness Detection. *Front. Neuroinform.* **14**, 553352 (2020). doi:10.3389/fninf.2020.553352.

[24] Sabio, J. et al. A scoping review on the use of consumer-grade EEG devices for research. *PLoS ONE* **19**, e0291186 (2024). doi:10.1371/journal.pone.0291186.

[25] Zhang, M. et al. Recent Advances in Portable Dry Electrode EEG: Architecture and Applications in Brain-Computer Interfaces. *Sensors* **25**, 5215 (2025). doi:10.3390/s25165215.

<!-- Classical / seminal references (pre-2019, outside paperclip corpus). Verify DOIs manually. -->

[26] Teplan, M. Fundamentals of EEG measurement. *Meas. Sci. Rev.* **2**, 1-11 (2002).

[27] Oostenveld, R. & Praamstra, P. The five percent electrode system for high-resolution EEG and ERP measurements. *Clin. Neurophysiol.* **112**, 713-719 (2001). doi:10.1016/S1388-2457(00)00527-7.

[28] Seeck, M. et al. The standardized EEG electrode array of the IFCN. *Clin. Neurophysiol.* **128**, 2070-2077 (2017). doi:10.1016/j.clinph.2017.06.254.

[29] Metting van Rijn, A.C., Peper, A. & Grimbergen, C.A. High-quality recording of bioelectric events. Part 1: interference reduction, theory and practice. *Med. Biol. Eng. Comput.* **28**, 389-397 (1990). doi:10.1007/BF02441961.

[30] Usakli, A.B. Improvement of EEG signal acquisition: an electrical aspect for state of the art of front end. *Comput. Intell. Neurosci.* **2010**, 630649 (2010). doi:10.1155/2010/630649.

[31] Fonseca, C. et al. A novel dry active electrode for EEG recording. *IEEE Trans. Biomed. Eng.* **54**, 162-165 (2007). doi:10.1109/TBME.2006.884649.

[32] Mathewson, K.E. et al. High and dry? Comparing active dry EEG electrodes to active and passive wet electrodes. *Psychophysiology* **54**, 74-82 (2017). doi:10.1111/psyp.12536.

[33] Grozea, C., Voinescu, C.D. & Fazli, S. Bristle-sensors — low-cost flexible passive dry EEG electrodes. *J. Neural Eng.* **8**, 025008 (2011). doi:10.1088/1741-2560/8/2/025008.

[34] Chi, Y.M., Jung, T.-P. & Cauwenberghs, G. Dry-contact and noncontact biopotential electrodes. *IEEE Rev. Biomed. Eng.* **3**, 106-119 (2010). doi:10.1109/RBME.2010.2084078.

[35] Jackson, A.F. & Bolger, D.J. The neurophysiological bases of EEG and EEG measurement: a review for the rest of us. *Psychophysiology* **51**, 1061-1071 (2014). doi:10.1111/psyp.12283.

[36] Niso, G. et al. Wireless EEG: A survey of systems and studies. *NeuroImage* **269**, 119774 (2023). doi:10.1016/j.neuroimage.2022.119774.

[37] Voigts, J. et al. The flexDrive: an ultra-light implant for optical control and highly parallel chronic recording of neuronal ensembles in freely moving mice. *Front. Syst. Neurosci.* **7**, 8 (2013). doi:10.3389/fnsys.2013.00008.

<!-- PRIORITY-1 PLACEHOLDER -->

[38] Black, C., Voigts, J., Agrawal, U., Ladow, M., Santoyo, J., Moore, C. & Jones, S. Open Ephys electroencephalography (Open Ephys + EEG): a modular, low-cost, open-source solution to human neural recording. *J. Neural Eng.* **14**, 035002 (2017). doi:10.1088/1741-2552/aa651f. **Primary comparison benchmark for FreeEEG128** — see `COMPARISON.md §Black 2017 vs FreeEEG128`.

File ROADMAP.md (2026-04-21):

# FreeEEG128 — Alpha → Beta Roadmap

Two tracks in parallel. The alpha is in hand now; the beta is a future board rev
that adds an **ESP32-S3 co-processor** (WiFi/BLE, LSL, CircuitPython, STEMMA QT)
while keeping the STM32H743ZI as the acquisition engine.

MCU choice is settled — see `feedback_freeeeg128_mcu.md` in memory.

---

## What carries over (alpha → beta)

| Carries 1:1 | Needs re-work |
| --- | --- |
| ADS131M08 driver (SPI + DRDY + CRC) | Host transport (USB-CDC → STM32↔ESP32 SPI/UART bridge) |
| TIM1/TIM8 DMA sample-sync cascade | USB re-enumeration / power-up handshake |
| LSM6DS3 IMU driver | Board pinmap (some pins move for the new bridge + radio) |
| SDMMC + FatFS logging layer | DFU pathway (ESP-side OTA replaces STM DFU user-surface) |
| Framed packet format (seq, µs timestamp, per-ADC status, CRC) | — |
| Host command protocol (config, start/stop, impedance) | — |
| Channel/capability descriptor | — |
| Host-side Python capture client + LSL outlet + analysis pipeline | — (the beta just changes its transport backend) |
| Labstreamer integration (TTL markers, timing validation) | — (marker ingestion path is identical) |
| Cap prep / impedance / QC procedures | — (same cap, same electrodes) |
| Noise floor + per-channel calibration data | — (same analog front-end silicon) |

**Design rule:** the framed packet the alpha's STM32 sends over USB-CDC is
byte-for-byte the same packet the beta's STM32 sends to the ESP32-S3 over SPI.
The ESP32 just re-emits it over WiFi/WebSocket/LSL. Nothing above the
transport layer changes.

---

## Track A — Alpha, now

### Phase 0: Bring-up & characterization (alpha, baseline)

Goals: confirm the unit works, measure actual behavior, document reality vs paper.

- [ ] Power the unit from a USB battery; confirm USB enumerates as CDC on macOS/Linux.
- [ ] Capture a raw stream with the existing firmware; verify 128 × 250 Hz × 24-bit framing.
- [ ] Cap-off noise floor: record 5 min with inputs shorted to bias; compute per-channel µVrms and line-noise spur at 60 Hz.
- [ ] Cap-on signal: 5 min eyes-closed; confirm 8-12 Hz alpha over O1/O2/Pz.
- [ ] Electrode impedance: manual touch-test, log dead-channel pattern.
- [ ] Trace actual STM32 pinout vs `.ioc` — freeze a pin/function map document.
- [ ] Identify whether a Labstreamer TTL can be routed via the ADuM1402 ISO_UART spare lane.
- [ ] Confirm microSD socket works with existing firmware (may or may not be wired in active paths).

### Phase 1: Firmware rewrite v1 (alpha)

Goals: produce the **reference firmware + protocol** that the beta will inherit.

- [ ] Re-bootstrap `.ioc` on current STM32CubeMX; resolve HS/FS USB conflict (lock to FS).
- [ ] Modularize: `hal/`, `drivers/` (ads131m08, lsm6ds3, sdcard), `transport/` (cdc, bridge-stub), `services/` (acquisition, logging, command).
- [ ] Define framed packet: magic, length, seq, µs timestamp, ADC status mask, 128 × int24 samples, IMU, CRC32.
- [ ] Host command protocol v1: `START`, `STOP`, `SET_RATE`, `SET_GAIN <ch> <g>`, `LEAD_OFF_START`, `LEAD_OFF_STOP`, `GET_CAPS`.
- [ ] Capability descriptor (channel map, rates supported, firmware rev) returned on `GET_CAPS`.
- [ ] Forward ADS131M08 per-sample CRC; drop detection + counters.
- [ ] Enable IWDG; add boot banner with reset cause.
- [ ] Enable RTC (LSE is populated); device-side µs timestamp.
- [ ] Clean dead code: `ad7779.c/h`, W5500 blocks, commented LCD code.
- [ ] MPU-backed non-cacheable DMA region; re-enable DCache.
- [ ] Expose DFU-jump command on the control channel.

### Phase 2: Host stack (alpha, parallel)

Goals: the full acquisition + analysis pipeline, transport-agnostic.

- [ ] Python capture client: reads CDC, parses framed packets, writes BIDS-EEG.
- [ ] LSL outlet: republish EEG + IMU + markers with native-µs timestamps.
- [ ] Labstreamer integration: ingest TTL markers as LSL; cross-check with an in-band photodiode channel.
- [ ] Stimulus pipeline: PsychoPy or Presentation scripts with LSL markers; timing-characterize the display.
- [ ] Quality dashboard: per-channel PSD (matches paper's green/red gate), impedance display, drop-counter trend.
- [ ] BIDS-EEG writer + dataset template for MindBigData-style single-subject datasets.
- [ ] **FIFF writer** (Neuromag format) alongside BIDS-EEG — lets MNE-Python read captures via `mne.io.read_raw_fif()`. Enables MNE-CPP replay/forward-model pipelines trivially.
- [ ] **MNE-CPP integration** (see `docs/mne-cpp-plugin.md` when written): Stage 1 is free via LSL outlet; Stage 2 is a native MNE Scan acquisition plugin (`freeeeg128adapter`) modeled on `applications/mne_scan/plugins/lsladapter/`, upstreamable to mne-tools/mne-cpp after P1.0 protocol freeze + P1.4 driver stable.

### Phase 3: Data collection on alpha

Goals: validate the full stack end-to-end; produce real datasets.

- [ ] Replicate a small MindBigData-style block (MNIST or ERP paradigm) to prove parity with the paper.
- [ ] ERP validation: auditory oddball — confirm P300 latency within 20 ms of Labstreamer ground truth.
- [ ] Publish dataset + acquisition protocol before the beta arrives so we have a reference.

---

## Track B — Beta design, in parallel

### Phase B0: Architecture (now)

Decide the bridge before fabrication.

- [ ] **MCU keep vs upgrade** (see §B0.1 below). Default: keep H743ZI.
- [ ] Co-processor: **ESP32-S3** (default) vs ESP32-P4 + C6 (if USB-HS + DP-FPU needed on the radio side).
- [ ] Bridge link: SPI (fast, low-latency) or UART (simpler, fewer pins). Favor SPI: 6 Mbps sustained well within the packet budget, and STM32H7 has spare SPI capacity.
- [ ] Direction: STM32 is SPI master (clocks the link), ESP32-S3 is slave + data-ready interrupt. Symmetric framing so commands flow back.
- [ ] Isolation: ESP32-S3 lives on the **host side** of the existing ADuM barrier. New isolator (ADuM141D or similar) on the STM32↔ESP32 SPI lane. Radio never crosses the analog ground plane.
- [ ] Power: separate RF-quiet LDO for ESP32-S3; antenna oriented away from analog front-end.
- [ ] STEMMA QT / Qwiic connector on the ESP32 side — Adafruit I²C sensors plug directly.
- [ ] Trigger input: dedicate one ADuM1402 channel for isolated TTL from Labstreamer into STM32 (not ESP32).

### B0.1 — STM32 MCU upgrade evaluation

Default: **keep STM32H743ZI**. Every STM32 in-family refresh keeps our 6-SPI /
TIM-DMA-cascade advantage unchanged; clock-bump variants solve a problem we
don't have.

| Option | Speed | Key delta vs H743 | Verdict |
| --- | --- | --- | --- |
| STM32H753ZI | 480 MHz | + crypto accelerator, pin-compat | No — crypto lives on ESP32-S3. |
| STM32H723/H725ZG | 550 MHz | +15% clock, less RAM (565 KB) | No — gain we don't need, RAM regression. |
| STM32H7A3/H7B3ZI | 280 MHz | 2 MB flash + 1.4 MB RAM, USB-HS PHY on-die | Marginal — deeper buffers, but clock regression. |
| STM32H755/H757ZI (M7 + M4) | 480 + 240 | dual-core, M4 could own bridge | No — doesn't give Adafruit/CircuitPython alignment. ESP32-S3 remains the right tool. |
| STM32H7R / H7S | 600 MHz | XiP-flash design, newest H7 | No — external-flash architecture overcomplicates. |
| **STM32N6** | 800 MHz (M55 + Helium + NPU) | Vector DSP + on-die Neural-ART NPU | **Maybe** — only qualitatively new upgrade. Unlocks on-device ML (artifact gating, decoding). |
| **STM32MP2 series** (M33 + A35 Linux) | heterogeneous | Cortex-A runs Linux → native PyLSL/BrainFlow/ROS | **No — see §B0.2.** Wrong tool for a belt-pack 128-ch acquisition rig. |

**Decision rule:**
- If beta = "same job, cleaner firmware + radio surface" → H743 + ESP32-S3.
- If beta = "add on-device ML (real-time artifact gating, adaptive filter, decoder)" → **STM32N6** + ESP32-S3.
- If beta = "drop the ESP32 entirely, run Linux on-device" → **STM32MP2**, no ESP32 (but lose Adafruit alignment).

See also: `COMPARISON.md` (open-source EEG landscape), `REFERENCES.md` (academic refs including Black et al 2017 Open Ephys 128-ch).

### B0.2 — STM32MP2 evaluation (done; rejected)

Evaluated ST's heterogeneous Cortex-A + Cortex-M MPU line as a way to run Linux
on-device and eliminate the ESP32-S3 co-processor. Findings (pricing
pre-2026 estimates, re-verify at distributor before citing in design docs):

- **SPI count**: MP25x has **8 SPI** (≥ our 6 — pass). MP23x ~6 (borderline). MP21x ~4 (fail).
- **Timer/DMA cascade**: M33 domain exposes TIM1/TIM8 + HRTIM + newer GPDMA; our CS-pulse pattern ports, but HAL-layer rewrite required.
- **Dev boards**: MP257F-DK ~$150-180, MP257F-EV1 ~$600-750, MP235F-DK ~$100-130 (all pre-2026; re-verify).
- **Silicon qty-1k**: ~$18-30 per MP25 SKU vs ~$12-15 H743ZI.
- **Package**: TFBGA-361 at 0.5 mm pitch → forces **6-8 layer HDI PCB with laser microvias**. Real DFM jump for an analog research board.
- **Power**: H743 + ESP32-S3 is ~1-1.5 Wh for a 4-6 h session; MP257 running Linux is **10-20 Wh** — a ~10× battery-mass regression. Unacceptable even for a belt-pack; pushes the amp back to desk-tethered only.
- **EMI**: adding a PMIC (STPMIC25) + LPDDR4 routing next to a 24-bit Δ-Σ front-end is an SNR regression; puts pressure on the ground plane and shielding.
- **Attack surface**: Linux rootfs + secure boot key management is a maintenance burden a medical-isolated device shouldn't carry for nothing.
- **Wins**: 1.35 TOPS on-die NPU (MP257), MIPI-CSI, GbE/TSN, eliminates a coprocessor. None of those are stated requirements.

**Verdict: reject for the belt-pack acquisition board.** (The 128-ch amp is not head-worn — see `ENCLOSURE.md`. But a 10× battery-weight regression is still unacceptable on a belt pack.) If on-device Linux
becomes desirable later (cloud sync, on-device analysis, camera co-registration),
add it as a **separate isolated companion module** (RPi CM5 or an Octavo
OSD32MP25 SoM) connected over isolated SPI/UART — that preserves the
radio-quiet analog section and keeps the medical isolation boundary clean.

This leaves **STM32N6** as the only STM32 upgrade worth further evaluation (on-device ML via M55 + Helium + NPU). Treat it as a B0.1 decision between "H743 default" and "N6 if we want on-device ML."

### Phase B1: Schematic + PCB

- [ ] Freeze STM32 pinmap from Phase 0 audit; avoid gratuitous changes.
- [ ] Add ESP32-S3-WROOM-1-N16R8 (16 MB flash, 8 MB PSRAM).
- [ ] Add RF shield can; antenna cutout; ground-stitching to analog section.
- [ ] Add STEMMA QT, Qwiic, user buttons, addressable LED (Adafruit-curriculum surface).
- [ ] Add isolated TTL trigger header (BNC or 3.5 mm) for Labstreamer.
- [ ] Optional: magjack + LAN8742A RMII PHY for true Ethernet (only if WiFi latency proves insufficient for some use case).
- [ ] Keep cap-side connector and electrode pinout identical — cap is a big investment.

### Phase B2: Firmware (port + co-processor)

- [ ] STM32 firmware: replace `transport/cdc.c` with `transport/bridge_spi.c`; everything else unchanged.
- [ ] ESP32-S3 firmware v1 (ESP-IDF): consume bridge packets, emit over WiFi WebSocket + LSL.
- [ ] ESP32-S3 firmware v2 (optional): CircuitPython build exposing the same packet stream via Python APIs for teaching.
- [ ] OTA: ESP-side for field updates; STM-side retained via DFU.

### Phase B3: Bring-up & parity

- [ ] Side-by-side capture on alpha (CDC) vs beta (WebSocket) of the same paradigm; confirm byte-identical packets.
- [ ] Re-run ERP validation to confirm beta matches alpha latency characterization.

---

## Future form-factor variants (post-beta, same architecture)

The STM32H743 + ADS131M08 + framed-packet stack isn't specific to a
128-channel cap. The same firmware, same host Python package, same wire
protocol, same LSL outlet all work at other channel counts. Two concrete
directions worth capturing:

### FreeEEG-Ear — concealed cEEGrid form factor

Knierim, Berger & Reali (2021, *Brain-Computer Interfaces*,
[doi:10.1080/2326263X.2021.1972633](https://doi.org/10.1080/2326263X.2021.1972633))
demonstrate that an OpenBCI-class ADS1299 amplifier, connected to
cEEGrid around-the-ear flex-PCB electrodes (Debener et al. 2015,
*Scientific Reports*), captures clinical-grade EEG at ~10-20 channels
per ear with:

- **~1-minute electrode application** (adhesive-backed cEEGrid, no
  hair prep, no saline/gel)
- **Concealed / wearable-all-day** — sits behind the pinna, not visible
  under normal hair

Pairs naturally with the **Fastball paradigm** (Stothart et al. 2017
*Neuropsychologia*; Stothart et al. 2021 *Brain*) — rapid serial visual
presentation at 3 Hz with embedded 0.6 Hz oddball, ~3-minute passive
protocol producing an implicit-recognition response. Fastball
works on populations where instruction-following fails (dementia,
stroke, paediatric), making it the natural clinical-screening
application for a cEEGrid-class device.

**Architecturally**: one or two ADS131M08s (8 ch each), same
STM32H743-class MCU, same full-speed USB-CDC / Pi-Zero-2W companion
pattern, same firmware source tree with `n_eeg_channels` baked into
the capability descriptor. The hardware delta is almost entirely
**cap connector + mechanical form factor** (flex-PCB strip + adhesive
backing vs 130-pin DIN harness). The firmware doesn't care.

Staging relative to current work:

- **FreeEEG128 beta** finishes first — that's where the acquisition-
  architecture correctness + firmware rewrite + host stack get proven.
- **FreeEEG-Ear** then becomes a board-layout-only project — schematic
  changes limited to removing 14 ADS131M08 instances and the 130-lead
  fan-out, and swapping the cap interface for a cEEGrid-compatible
  connector. Most of the expensive design work (isolation, LDOs,
  references, USB, firmware, host) is direct reuse.
- **Fastball pipeline** can be developed in parallel using EEG-ExPy or
  PsychoPy on the existing Pi-Zero-2W host, validated against the
  FreeEEG128 board, then deployed against FreeEEG-Ear when that board
  lands. The cap-side change is invisible to the stimulus engine.

Clinical indication pathway: dementia memory screening → stroke
recovery assessment → paediatric language/memory assessment → teletherapy
monitoring. Each of those is a several-hundred-thousand-patient-a-year
market in the US alone; none is addressable by a 128-channel research rig.

### FreeEEG256 — density upgrade

Same STM32H743 + firmware, 32× ADS131M08 across the six SPI buses
instead of 16. Moves into the VHD-EEG class (256 ch is where g.Pangolin
lives — see `COMPARISON.md`). Bigger board, more expensive BOM, harder
cap manufacturing. Not on the near-term roadmap but the firmware and
host work done for FreeEEG128 port forward unchanged.

### Both variants exist because the protocol is cap-agnostic

The `CAPABILITIES` packet (protocol v1 §0x20) carries `n_eeg_channels`
and a label list on every boot. Host software auto-configures for the
connected device. This is why these two spin-offs cost one board layout
each, not full firmware + host rewrites.

## Work we should NOT do on the alpha

Things that would waste effort because they don't transfer:

- WiFi bring-up on STM32 (no radio; adding one is the whole point of the beta).
- Ethernet via W5500 SPI module (may feel tempting given the commented-out code, but WiFi-on-beta is the planned path).
- CircuitPython on STM32H7 (H7 isn't a CP tier-1 target; ESP32-S3 on beta is the Python surface).
- Building our own LSL bridge on the STM side — trivial work the beta's ESP32 does natively.

---

## Immediate next steps (this week)

1. Power up the alpha, confirm CDC enumeration, log one 60 s capture with shorted inputs for noise floor.
2. Extract actual STM32 pinout → `docs/alpha-pinmap.md` to freeze before firmware rewrite.
3. Decide: rewrite `.ioc` from scratch on current CubeMX, or migrate the existing one? (Recommendation: scratch — too many gaps to paper over.)
4. Draft the framed-packet spec → `docs/packet-format.md`. This is the single most important artifact for carry-over; lock it before writing any transport code.

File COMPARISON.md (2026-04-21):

# Open-source EEG board landscape

Comparison of other open-source / open-hardware EEG boards and the concrete
lessons we should steal for the FreeEEG128 rewrite and the beta rev.

> ⚠️ **Live-data caveat:** the research agent that produced the table below had
> no network access in the session it was run in, so **URLs, prices, and 2026
> SKUs are training-data estimates, not live-verified**. Treat this file as a
> starting map. Before citing in any design doc, BOM, or purchase order,
> re-verify at the vendor site and on current GitHub repos.

---

## Boards surveyed

| Board | MCU | ADC | Ch | Max SR | Res | Host I/F | Enclosure | Price USD | License | URL | Lesson for FreeEEG128 |
|---|---|---|---|---|---|---|---|---|---|---|---|
| **OpenBCI Cyton** | PIC32MX250F128B | ADS1299 | 8 (16 w/ Daisy) | 250 Hz (16ch) / 500 Hz (8ch) | 24-bit | RFduino BLE → USB-serial | Ultracortex 3D-printable headset | ~$1 000 / ~$2 200 w/ Daisy | MIT (HW+FW) | docs.openbci.com/Cyton | **Reference packet format**: 33-byte binary, `0xA0` start / `0xCn` stop; ASCII command set (`b`=start, `s`=stop, `x…X`=per-ch config). Wide ecosystem. |
| **OpenBCI Ganglion** | nRF51822 (M0 + BLE) | MCP3912 | 4 | 200 Hz | 24-bit | native BLE | small PCB | ~$500 | MIT | docs.openbci.com/Ganglion | BLE-direct firmware pattern for a future small variant. |
| **OpenBCI Galea** | NXP i.MX RT1062 + multi-ADS1299 | multi-ADS1299 | 8 EEG + EMG/EOG/GSR/PPG/eye | 500 Hz | 24-bit | USB-C + VR HMD tether | integrated in Varjo/Valve HMD | ~$25 000 | closed HW / open SDK | galea.co | Productized BrainFlow/LSL integration + multimodal fusion. |
| **OpenBCI WiFi Shield** | ESP8266 | (passthrough) | — | 1 kHz on Cyton | — | WiFi TCP/UDP | shield | ~$80 | MIT | docs.openbci.com/WiFiShield | **Accessory-shield model**: decouple radio from main board. |
| **PiEEG** (PiEEG Ltd) | Raspberry Pi host + thin MCU bridge | ADS1299 (×1/×2) | 8 / 16 | 250-500 Hz | 24-bit | SPI HAT → Raspberry Pi | plastic enclosure + cap | ~€350 / €600 | GPL-3.0 | github.com/pieeg-club/PiEEG | **Host-as-MCU**: offload stack to Pi, MCU is a thin SPI↔USB/Ethernet bridge. |
| **IronBCI** (PiEEG Ltd) | STM32F4 | ADS1299 | 8 | 500 Hz | 24-bit | USB-CDC + BLE | DIY PCB | open-source BOM | GPL-3.0 | github.com/pieeg-club/ironbci | Explicit "FreeEEG32 successor in STM32 form"; adds BLE, Python client, and a validation preprint vs BioSemi. |
| **NeuroPawn Knight** | RP2040 / ESP32-S3 | ADS1299 | 8 | 500 Hz | 24-bit | USB-CDC (+ BLE on ESP) | breadboard / DIY | kit ~$250 | MIT / CERN-OHL | neuropawn.com | Low-cost hobbyist entry; good BrainFlow/LSL example code. |
| **HackEEG** (Starcat / Feuer) | Arduino Due (SAM3X8E) | ADS1299 (1-4 daisy) | 8 / 16 / 24 / 32 | **16 kHz @ 8ch** (packed binary) | 24-bit | USB-CDC | bare shield | ~$450 | MIT | github.com/adamfeuer/hackeeg-client-python | **Dual protocol**: JSONLines for debug + MessagePack for speed. |
| **Neurogate OctaFlow** | ESP32-C3 | ADS1299 | 8 | 4 kHz | 24-bit | USB-CDC + WiFi/BLE | small PCB | ~$200 | open | neurogate.io | ESP32 low-BOM template for a future "FreeEEG-mini" / teaching board. |
| **FreeEEG32-beta** (NeuroIDSS, predecessor) | STM32F4 | 4× ADS131M08 | 32 | 250 Hz-2 kHz | 24-bit | USB-CDC | DIY | ~$500 BOM | AGPL-3.0 | github.com/neuroidss/FreeEEG32-beta | **Proved ADS131M08** (vs industry-default ADS1299) hits research-grade noise; demonstrated 4-chip SPI ganging. The 128 just scales the pattern (16 chips, STM32H7). |
| **Upside Down Labs BioAmp EXG Pill** | host MCU (Arduino / Pi Pico) | MCP6N11 front-end → host ADC | 1 | host-limited | host-limited | analog | tiny PCB | $25-$40 | CERN-OHL-P | github.com/upsidedownlabs/BioAmp-EXG-Pill | Instrumentation-amp reference design + superb educational docs — model for teaching materials. |
| **Cognionics/CGX Quick-series** | proprietary | ADS1299 | 8-64 | 500 Hz | 24-bit | BT / USB | dry-electrode cap | $6 k-$25 k | partial schematic release | cgx.com | **Dry-electrode mechanical designs** worth studying for the brain-box. |
| **ExG / ExGate** (community) | STM32 | ADS1299 | 8 | 500 Hz | 24-bit | USB | DIY | — | GPL | forum-scale | Smallest serious ADS1299 reference. |

---

## Key lessons for FreeEEG128

1. **Adopt OpenBCI Cyton binary framing as a supported mode.** `0xA0` start, 24-bit big-endian signed samples, 3-byte aux slot, `0xC0 + rolling-nibble` stop. Every existing client (BrainFlow, OpenViBE, LSL-OpenBCI, BCI2000, Neurosity, Timeflux) speaks it — compatibility is ~free. Keep our native framed-packet format too, but offer a Cyton-compatible alias.

2. **Dual protocol like HackEEG.** Ship a human-readable **JSONLines / ASCII debug mode** AND a **packed binary mode** for the 128 ch × 250 Hz ≈ 96 kB/s fast path. One firmware, two modes.

3. **Standard command vocabulary.** Cyton has a decade of muscle memory behind `b`/`s` start/stop, `?` version, `v` reset, `z<ch>Z` impedance cycle, `x<ch><gain><type><bias><srb2><srb1>X` per-channel config. Inherit it.

4. **Impedance mode is table-stakes.** Inject 6 nA 31.25 Hz on each channel (ADS1299 LOFF_STAT equivalent — ADS131M08 has lead-off detect too) and report Z per electrode before every session. Neither FreeEEG32-beta nor HackEEG shipped this polished; it's the #1 complaint in OpenBCI forums.

5. **LSL + BrainFlow on day one.** Write the BrainFlow `Board` definition ourselves and upstream it — that alone gives us MNE-LSL, LabRecorder, Timeflux, NeuroPype, and OpenViBE. BrainFlow's `BoardIds` enum is the de-facto registry for open EEG.

6. **Accessory-shield architecture (OpenBCI pattern).** Keep the H743 board purely wired/USB; put WiFi (ESP32-S3) and BLE on a separate pluggable daughterboard. Easier FCC, easier medical-grade variants, simpler firmware.
    → this is the beta-rev plan already.

7. **Timestamp every packet at source.** 64-bit monotonic microsecond counter in every frame + a sync-pulse GPIO for LSL `push_chunk` alignment. IronBCI's validation paper flagged this as the biggest gap in FreeEEG32.

8. **Publish a validation study in the repo.** PiEEG/IronBCI's credibility jumped the day Dzhelyova et al. posted bench comparisons to BioSemi ActiveTwo. We should do SSVEP + alpha-peak reproduction with open data in `docs/validation/` before calling anything "beta".

9. **Document like OpenBCI, not like a PhD repo.** `docs.openbci.com` has separate Getting-Started / SDK / Hardware / Tutorials trees. MkDocs + screenshots beats a 40-page PDF.

10. **License split.** AGPL-3.0 on firmware + **CERN-OHL-S-v2** on hardware. AGPL-only on hardware (as NeuroIDSS currently publishes) is legally murky — AGPL is a software licence. CERN-OHL-S-v2 is the modern answer and matches Upside Down Labs and PiEEG practice.

---

## Specific IronBCI → FreeEEG128 deltas

IronBCI is the most directly comparable reference because it's the same lineage
(NeuroIDSS/PiEEG-Club, STM32-based, single ADS-chip successor to FreeEEG32):

| Feature | FreeEEG32-beta | IronBCI | FreeEEG128-alpha | FreeEEG128-beta target |
| --- | --- | --- | --- | --- |
| ADC | 4× ADS131M08 | 1× ADS1299 | 16× ADS131M08 | 16× ADS131M08 |
| MCU | STM32F4 | STM32F4 | STM32H743 | STM32H743 (keep) |
| Host link | USB-CDC | USB-CDC + **BLE** | USB-CDC | USB-CDC + **WiFi via ESP32-S3** |
| Python client | — | **yes (maintained)** | not open-sourced | to build |
| BrainFlow board | no | **yes** | no | **ship** |
| Validation vs clinical amp | no | **yes (Dzhelyova preprint)** | no | **do SSVEP + alpha-peak study** |
| Impedance check | no | partial | no | **ship** |
| Device-side timestamp | coarse | us-precision | host-only | **device-side µs** |

Direction: the beta should **match IronBCI on every row except channel count**.
IronBCI is the correctness bar; FreeEEG128 beats it only in aggregate channel
count and isolation depth.

---

---

## Black et al. 2017 (Open Ephys + EEG) vs FreeEEG128 — primary comparison

Reference: Black, C. et al. "Open Ephys electroencephalography (Open Ephys + EEG): a modular, low-cost, open-source solution to human neural recording." *J. Neural Eng.* **14**, 035002 (2017). doi:10.1088/1741-2552/aa651f.

This is the canonical open-hardware 128-ch human EEG paper. The architecture
is very different from ours — they ride the Open Ephys neural-recording
platform and adapt commercial EEG caps into Intan RHD headstages, so their
"board" is the generic Open Ephys acquisition board plus adapters. We should
match or beat every row below.

| Axis | Open Ephys + EEG (Black 2017) | FreeEEG128-alpha / beta |
| --- | --- | --- |
| **ADC / amplifier** | Intan **RHD2132** (32-ch) or **RHD2164** (64-ch) bioamplifiers, **16-bit** ADC, on-headstage SPI  | **16× TI ADS131M08**, **24-bit** Δ-Σ, differential amp, 6 SPI buses |
| **Channels demonstrated** | 32 / 64 / up to 128 (2× RHD2164) — board supports up to 512 total | 128 fixed |
| **Sample rate** | configurable up to 30 kHz (Intan max) | 250 Hz firmware default; ADS131M08 supports up to ~32 kSPS |
| **Resolution** | **16-bit** (Intan) | **24-bit** (our advantage — +8 bits dynamic range) |
| **Input-referred noise** | ~2.4 µV-RMS (Intan RHD spec) | ~0.5 µV-RMS over 250 Hz BW at gain 32 (ADS131M08) — **our advantage** |
| **Acquisition board** | **Open Ephys acquisition board**: Opal Kelly XEM-6310 FPGA, USB 3.0 host, up to 8 headstages | Custom FreeEEG128 PCB with STM32H743ZI + on-board 16× ADS131M08 — **no FPGA, no separate headstage** |
| **Host interface** | USB 3.0 from the Open Ephys board | USB-CDC (FS, via ADuM3160 isolator); beta adds WiFi/BLE via ESP32-S3 |
| **Cap / electrodes** | Adapts **commercial EEG caps** (EasyCap, etc.) via a custom breakout from cap connector → Omnetics → Intan headstage | Open-hardware **130-electrode dry Ag/AgCl cap** (custom textile + free_dry_electrodes PCBs); cap is part of the project |
| **Connector stack** | Cap → custom breakout PCB → Omnetics nano-strip → RHD headstage → SPI cable to Open Ephys board | 128× 1.5 mm DIN → brain-box → ADC PCB (alpha) / → multipole quick-disconnect → belt-pack (beta) |
| **Reference / ground** | EEG-cap convention (e.g., CMS/DRL, Cz, earlobe) — configurable via breakout | **CP1 = reference, CP2 = ground** (hard-wired at cap; no on-board flexibility) |
| **Isolation** | Partial — Intan chip is biocompatible, but the Open Ephys board is USB-mains-referenced unless isolated upstream | **Full medical-grade isolation** on-board: ADuM3160 USB + ADuM1402 UART + 2× ISO7341C SPI + SN6505B+xfmr isolated DC-DC → **our advantage** |
| **Form factor** | Desk/rack — Open Ephys board is a lab instrument, not wearable | **Belt-pack wearable** target (see ENCLOSURE.md) |
| **Stimulus sync** | Via Open Ephys digital inputs (8 DI + 8 DO + 8 ADC + 8 DAC) — excellent | Currently none; beta plan adds TTL via ADuM1402 spare lane + Labstreamer |
| **Logging** | Open Ephys GUI → host disk | USB to host; beta adds device-side SD + WiFi |
| **Software** | Open Ephys GUI (mature plugin architecture, Bonsai integration) | Paper's custom tool (closed); we are rewriting. Target: BrainFlow + LSL + OpenViBE. |
| **Total cost** | ~$2000-3500 (Open Ephys board ~$2000 + 2× RHD2164 headstages + breakout + cap) | ~$500-1000 BOM estimate for FreeEEG128-alpha (16× ADS131M08 + H743 + 130 dry electrodes). **Our cost advantage** |
| **Hardware license** | **CC BY-NC-SA 3.0 IGO** (non-commercial) on Open Ephys board | AGPL-3.0 upstream; we recommend **CERN-OHL-S-v2** for beta → **our licensing advantage (commercial-use OK)** |
| **Validation benchmark** | Eyes-closed 8-14 Hz alpha, side-by-side vs **BrainVision actiCHamp** — "similar average power and SNR" | Not yet done. **Must reproduce Black 2017's exact protocol** on our unit as acceptance gate. |

### What FreeEEG128 inherits from Black 2017

1. **Validation protocol**: eyes-closed 8-14 Hz alpha vs a clinical-grade actiCHamp is the minimum bar to call anything "beta". Same paradigm, same window, same metric (average power + SNR).
2. **Commercial-cap adapter path**: their breakout PCB from an EasyCap-class connector to an Omnetics-to-Intan headstage is a model for how we could offer a FreeEEG128-amp variant that takes *any* commercial EEG cap. Worth prototyping as a sister product.
3. **Desk-vs-wearable split**: Black's board is desk-tethered; ours is belt-pack. Not a deficit, just a different target. Document the distinction in our marketing.
4. **Plugin-GUI integration**: Open Ephys GUI has the best plugin ecosystem in open-source EEG. **Write an Open-Ephys GUI plugin** for FreeEEG128 (equivalent to their "Rhythm Node") so their users can swap in our amp without changing pipeline.
5. **MNE-CPP / MNE Scan plugin**: the C++ half of the MNE ecosystem has the same plugin architecture as Open Ephys GUI. Supporting both gets us into the two dominant open real-time acquisition stacks. BSD-3 licensed, upstream-accepting. Stage 1 (LSL loopback) lands free via P2; Stage 2 (native `freeeeg128adapter`) is a 1-2 week PR to mne-tools/mne-cpp.
6. **FIFF output**: make `mne.io.read_raw_fif()` work on our captures so MNE-Python users don't translate formats. ~50 lines in the Python host.

### Where FreeEEG128 should beat Black 2017

- **+8 bits resolution** (24-bit vs 16-bit) — real noise-floor improvement for small-signal paradigms (ERN, SSVEP at low contrast, intracranial-analogue imagined speech).
- **Full isolation barrier on-board** — Black 2017 inherits the Open Ephys board's isolation situation, which is not medical-grade by default.
- **No FPGA** — cheaper BOM, simpler firmware story (we stay in STM32 land).
- **Wearable form factor** — Black 2017 is a lab rig; we're targeting mobile.
- **Commercial license** — our CERN-OHL-S plan removes the NC barrier to clinical / commercial deployment.

### Acceptance gate before calling anything "beta"

- [ ] Reproduce Black et al. 2017 Fig. ? (eyes-closed alpha vs actiCHamp) on our unit.
- [ ] Publish raw data + protocol in `docs/validation/` at the same moment we publish the beta schematic.
- [ ] Write an Open Ephys GUI plugin that ingests FreeEEG128's USB stream.

---

---

## VHD-EEG state-of-the-art: g.Pangolin (1024-channel ceiling)

The open-hardware landscape table above sits *below* the commercial
very-high-density (VHD / uHD) frontier. As of 2024, the SOTA for
non-invasive scalp EEG is **g.tec's g.Pangolin**, built around flexible-
PCB active-wet electrode grids feeding up to four g.HIamp 256-channel
amplifiers.

| Axis | g.Pangolin (g.tec, 2023-) | FreeEEG128 (this project) |
| --- | --- | --- |
| Channels | up to **1024** (4× 256-ch g.HIamp) | 128 |
| Electrode technology | Active wet, flex-PCB grids (16 ch per grid) | Passive dry Ag/AgCl (130 electrodes, 10/5 cap) |
| Inter-electrode distance | 8.6 mm | ~20 mm (standard 10/5 at 128 channels) |
| Electrode diameter | 5.9 mm | 12 mm |
| Pre-amplification | On-grid pre-amp, fixed gain 10 | None (passive → ADS131M08 gain 32 in-chip) |
| Sample rate | up to 38.4 kHz per channel | 250 Hz default (chip supports 32 kHz) |
| ADC resolution | 24-bit | 24-bit |
| Application | Clinical / research VHD, neurosurgical mapping, BCI | Open-hardware research, teaching, wearable EEG |
| Form factor | Desk-tethered, amp-on-belt with cables | Belt-pack wearable (see `ENCLOSURE.md`) |
| License | Proprietary (g.tec) | AGPL-3.0 + planned CERN-OHL-S-v2 |
| Cost | Likely >USD 100 000 for full 1024-ch system (unverified) | ~USD 500-1000 BOM |
| Primary paper | Schreiner et al. 2024, *Sci Rep* 14, doi:10.1038/s41598-024-57167-y | this project |
| Demonstrated validation | 95.2% anterior/posterior-to-CS classification accuracy via SSEP phase reversal — matches invasive ECoG | Planned: Black 2017 eyes-closed alpha replication |

**Key takeaway**: g.Pangolin at 256-ch density achieves localization
comparable to invasive intracranial recording. That's the frontier
FreeEEG128 is not chasing; instead, we target the "open, affordable, 128-
channel wearable" niche that has no current peer. A natural upgrade path
exists for a hypothetical `FreeEEG256` on the same STM32H743 + ADS131M08
chassis, but that is explicitly not within the current roadmap.

---

## Lessons from Cardona-Álvarez et al. 2023 (OpenBCI framework)

Reference: Cardona-Álvarez et al., *Sensors* **23**, 3763 (2023), doi:10.3390/s23073763. The most detailed published architecture reference for a production open-hardware BCI framework — worth reading before writing our own P2-P2c components.

### What they built

- OpenBCI Cyton (ADS1299, 8 ch; 16 ch with Daisy) with **custom low-level drivers** replacing the deprecated official Python layer.
- **Raspberry Pi as acquisition server** (validates our Pi Zero 2W companion choice).
- **Three-layer driver architecture**: low-level board I/O → high-level stream abstraction → application UI (PySide6 GUI).
- **Distributed computing via Apache Kafka** for multi-consumer message streaming.
- Stimulus delivery via **Brython-Radiant** (browser-based HTML/CSS/JS).
- Marker synchronization validated against a **Light-Dependent Resistor (LDR)** → the same technique we plan with Labstreamer + in-band photodiode.
- Open-source repos: <https://github.com/UN-GCPDS/openbci-stream>, <https://github.com/UN-GCPDS/BCI-framework>, docs at <https://docs.bciframework.org/>.

### Benchmarking methodology we can copy

Their Table 6 compares three systems on two metrics:

| System | Latency | Jitter | Communication |
| --- | --- | --- | --- |
| OpenBCI (theirs) | 56 % relative (100-sample block @ 1 kHz) | **5.7 ms** | Wireless |
| BCI2000 + g.USBamp | 14-48 % relative | 5.91 ms | Wired |
| OpenViBE + TMSi | 100.4 % relative | 3.07 ms | Optical |

Adopt this exact table for FreeEEG128's validation section: column 1 = system, column 2 = relative latency, column 3 = jitter, column 4 = transport. Directly comparable to our LSL bench p50 / p95 / max measurements (currently 12.8 / 12.9 / 14.8 ms on Pi Zero 2W, all tighter than their wireless OpenBCI numbers).

### Three sample-integrity detection methods

They cross-check stream completeness with:

1. Device-side **timestamp** on each sample
2. **Test-signal mode** (ADS chip-internal known waveform) to detect insertion/deletion
3. **Sample-index counter** (our `seq` field)

Our protocol has (1) via `ts_us` and (3) via `seq`, but **not (2) test-signal mode**. Add a `SELF_TEST` / `SET_MUX` pair to our command protocol that lets host validate stream integrity against the ADS131M08's test patterns. Already on the list as `CmdId.SELF_TEST` / `CmdId.SET_MUX` — this paper validates the need.

### Explicit criticisms of stock OpenBCI we can frame against

They enumerate OpenBCI pain points that our design must not inherit:

- *"Need for more effective communication between computers and peripheral devices"* — addressed in our **host command protocol** (v1 locked in `docs/command-protocol.md`).
- *"[Stock GUI] does not allow for data acquisition under specific parameters"* — addressed by our `SET_RATE` / `SET_GAIN` / `SET_MUX` commands.
- **Deprecated Python drivers** (historical) — replaced by BrainFlow. We target BrainFlow native from day one.
- **Cyton + Daisy interleave artifact**: expanding 8→16 channels alternates samples between two boards, requiring host-side interpolation that introduces phase error. **FreeEEG128's 16× ADS131M08 on a TIM1/TIM8-synchronized DMA cascade eliminates this artifact entirely** — all 128 channels are genuinely simultaneously sampled. This is one of the strongest technical arguments for our architecture over OpenBCI's.

### Paradigm gap we can fill

Their validation covered **motor imagery only** (cue-based left/right arrow paradigm). No P300, SSVEP, N170, MMN, or alpha rhythm. Combined with Black et al. 2017's eyes-closed alpha reference, FreeEEG128's planned validation battery — Black-style alpha *plus* P300 latency *plus* SSVEP spectrum *plus* optional N170 — materially expands the open-hardware EEG validation literature.

### What we will *not* copy from them

- **Apache Kafka** — overkill for single-subject recording with ≤10 consumers. Our LSL + BrainFlow stack covers the message-fan-out use case with far lower operational overhead. Revisit Kafka only if we grow into multi-device hyperscanning.
- **Brython-Radiant** stimulus delivery — we use PsychoPy / Labstreamer, which are the clinical-research standard.

---

### Supporting VHD-EEG literature

- **Schreiner et al. 2024** — introduces g.Pangolin; demonstrates 256-ch
  VHD EEG delineating the central sulcus at intracranial-comparable
  accuracy. (Primary comparison paper.)
- **Shirazi, Onton & Makeig 2025** (*bioRxiv*) — simulates scalp EEG from
  ultra-high-density ECoG to quantify cortex-to-scalp projection patterns.
  Motivates the spatial-Nyquist case for VHD EEG.
- **Liu, Ganzetti, Wenderoth & Mantini 2018** (*Front. Neuroinformatics*)
  — systematic study of how electrode density, head modeling, and source
  localization interact when detecting large-scale brain networks;
  methodological justification for the density race.
- **Fiedler et al. 2022** — 256-channel dry cap for VHD-EEG. Shows the
  dry-electrode path is viable at 256 channels, relevant to a possible
  FreeEEG256 direction.
- **Grover & Venkatesh** (cited in Schreiner 2024) — information-theoretic
  analysis of EEG spatial bandwidth arguing for thousands of sensors.

---

## Open questions to resolve before beta freeze

- Do we commit to **BrainFlow + LSL** as the primary host protocol, with Cyton-compatible binary as a secondary compatibility shim? (Recommend: yes.)
- Do we publish the validation dataset on OpenNeuro + HuggingFace, or only one? (Recommend: both — OpenNeuro for BIDS, HF for ML.)
- Do we license hardware as **CERN-OHL-S-v2** even though upstream NeuroIDSS uses AGPL-3.0? (Requires explicit relicensing discussion; the AGPL on hardware is a known issue.)
- Which ADS131M08 lead-off detection mode do we use for impedance, and at what drive current? (Needs bench measurement on the alpha.)

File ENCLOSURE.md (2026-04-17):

# Enclosure, Battery, Cable & Connector Notes

Design notes for FreeEEG128 physical form factor. **Key finding: this is
not a head-worn device.** The 130-lead cap harness plus amp PCB plus
battery exceeds a reasonable head-mount mass and volume budget. The
realistic form factor is:

```
CAP (head-worn)
 ├── 130 dry Ag/AgCl electrodes
 ├── 130× 1.5 mm DIN leads (keep — subject-contact safety)
 └── BRAIN-BOX (cap-mounted passive fan-out)
      └── 1-2 multipole quick-disconnect (LEMO / Omnetics / HD D-sub)
           │
           ▼ shielded bundle (30-60 cm)
           │
    AMP BOX (belt-pack / shoulder-pack / desk)
     ├── FreeEEG128 PCB (STM32H743 + 16× ADS131M08)
     ├── battery
     └── USB out to host (or WiFi via ESP32-S3 on beta)
```

This matches how BrainProducts (actiCHamp), ANT Neuro (eego), BioSemi
(ActiveTwo), and high-channel-count research rigs are physically organized.

> ⚠️ Live-data caveat: the research agent compiling this had no WebSearch
> access. Part numbers, prices, and vendor links below are training-data
> estimates (Jan 2026 cutoff) — re-quote on Digi-Key / Mouser before any
> BOM commit.

---

## 1. Existing on-board power & isolation topology

From the KiCAD BOM, the analog chain is already galvanically isolated and
very well regulated — **the battery/USB upstream is a non-critical rail**:

- **Analog LDOs**: 3× `LP5907QMFX-3.3Q1` (TI, 6.5 µV-RMS 10 Hz-100 kHz, ~82 dB PSRR @ 1 kHz). BOM shows `ADP7118AUJZ-3.3` (ADI, 1.6 µV-RMS, ~88 dB PSRR) as an alternative. Both genuinely world-class for 24-bit Δ-Σ.
- **Vref**: `REF2025AIDDC` → ADS131M08 Vref 1.25 V, gain 32.
- **Isolation barrier**: ADuM1402 (SPI), ADuM3160 (USB), 2× ISO7341C (SPI/misc), SN6505B + 750315371 push-pull transformer → isolated analog supply.

**Consequence**: whatever powers the digital/host side just has to feed the
SN6505 input without monstrous ripple. Subsequent stages reject it. This is
why the paper's "USB power bank" works — the ADuM3160 breaks the USB
ground loop and the SN6505 + LP5907/ADP7118 stack rejects the rest at
audio frequencies.

---

## 2. Battery chemistry options

Target session: 4-6 h at ~300-500 mA total board draw.

| Option | V | Practical capacity | Weight | Notes |
|---|---|---|---|---|
| **USB power bank** (what paper uses) | 5 V | 5-10 kmAh trivial | 150-300 g | Zero design work, hot-swappable. Watch for 50-100 mA idle-cutout silently disconnecting — budget a dummy load or LiPo buffer cap. |
| **1S LiPo 3.7 V + boost to 5 V** | 3.0-4.2 V | 2.5-3.5 Ah pouch (Adafruit 2011, SparkFun 13856 class) | 40-50 g | Boost switcher injects ripple — use TPS61230A / TPS61099 with a trailing LP5907. |
| **2S Li-ion 18650** (Samsung 35E, Panasonic NCR18650GA, LG MJ1) | 6.0-8.4 V | 3.4-3.5 Ah/cell | ~90 g (2 cells) | **Best measured noise**: enough headroom to use LT3045 (0.8 µV-RMS gold-standard LDO) as a linear regulator down to 5 V. |
| **1S 21700** (Samsung 40T, Molicel P42A) | 3.0-4.2 V | 4-4.5 Ah | 65-70 g | Same boost story as LiPo, slightly larger cell with better energy density. |
| **LiFePO4 1S / 2S** | 3.2 / 6.4 V flat | 1.5-3.2 Ah | variable | Thermally safest. Flat discharge curve *helps* LDO dropout budgeting. No measured evidence it's noisier after LDO. |

**What comparable rigs use** (memory, verify):

- **OpenBCI Cyton**: 4× AA (6 V) or 1S LiPo + LP5907-class LDO.
- **OpenBCI Ganglion / WiFi Shield**: 500-1200 mAh LiPo.
- **Intan RHD2000 USB eval**: USB-bus powered with same ADuM + isolated-DC/DC topology as our board.
- **Cognionics Quick-20 / Quick-30**: internal LiPo, ~8 h advertised.
- **g.tec g.Nautilus / g.USBamp**: proprietary packs; g.USBamp uses LT-series ultra-low-noise LDOs.
- **ANT Neuro eego sports**: LiPo in the amp pack.
- **Emotiv EPOC X**: ~640 mAh LiPo, ~9 h.

**Recommendation**:

- **Alpha (now)**: keep USB power bank. It's free and the isolation barrier already handles the noise.
- **Beta**: make the input accept 4.5-5.25 V USB range; add a `PMEG6020ETR` ideal-diode or `LTC4413` auto-OR between USB-C input and an optional on-board 1S LiPo with a `MAX17227` boost. Don't touch the analog rails — they're already right.

---

## 3. Battery noise floor, honestly

- Switching-regulator ripple at 100 kHz-2 MHz does NOT show up in EEG band (0.1-50 Hz) when the analog LDO has ≥60 dB PSRR at switcher frequency. LP5907 and ADP7118 both clear this.
- TI's SBAA201/SBAA202 app notes: ADS131xx at gain 32 → ~30 nV/√Hz input-referred → ~0.5 µV-RMS over 250 Hz BW. Any of the above chemistries + LDO stack hits this.
- **Honest unknown**: no published peer-reviewed comparison of battery chemistry noise floors *at the electrode* for a 24-bit EEG system. If we need this claim in a paper, measure it on our unit.

---

## 4. Form factor: why not head-worn

Real 128-ch rigs ship the amp **off the head**. The options are:

| Philosophy | Examples | Channels feasible | Notes |
|---|---|---|---|
| **Enclosure = the cap** (molded plastic / fabric) | Cognionics Quick-20/30, Emotiv EPOC X, g.tec g.Nautilus puck | up to ~30-40 | Cap fabric IS the strain relief. Only works at lower ch counts. |
| **Amp-on-belt, shielded bundle to cap** | ANT Neuro eego, BrainProducts actiCHamp, BioSemi ActiveTwo | **64-256+** | **Our target pattern.** Moves weight off head; lets us use a real enclosure. |
| **Bare PCB + heat-shrink** | Intan RHD headstage, PiEEG | — | Research-only, not wearable long-term. |

At 128 channels, option 2 is the only viable path unless we redesign the
cap-to-box connector (see §6).

---

## 5. Enclosure for the amp box

| Option | Verdict for FreeEEG128 |
|---|---|
| **Off-the-shelf extruded aluminum** (Hammond 1455, Takachi MXA/MX, Bud) | **Recommended**. ~$15-25 USD. Drill yourself for connectors. 40 dB RF shielding for free. Downside: machining the connector face is the real cost. |
| **3D-printed PETG or PC** | Fine for prototyping. PETG is tougher than PLA, sweat-resistant. Nylon SLS for lanyard flex. No shielding, but we don't need it (board is isolated). |
| **CNC aluminum custom** | Correct long-term answer. $200-600 one-off from SendCutSend / Protolabs. Shielding nice-to-have, not must-have. |
| **Resin (SLA)** | Avoid — brittle, UV-degrades, not sweat-safe. |

**Shielding necessity**: low. The ADuM3160 breaks USB ground, SN6505 +
LP5907/ADP7118 stack gives 80-90 dB PSRR. 50/60 Hz line noise, if you see
any, is coming in through **electrode leads**, not the enclosure. Spend
shielding budget on the 0.6 mm electrode-cable drain termination, not
on the box.

**Wearability**:

- **Belt pack / fanny pack** — 300-400 g is fine on a belt. Easiest path.
- **Shoulder-strap amp bag** (ANT-style) — best balance. $20 off-the-shelf from any tactical-gear vendor.
- **Neck lanyard** — only if <150 g, unrealistic with 130 connectors.

---

## 6. Connectors — the 1.5 mm DIN problem

The 128× individual 1.5 mm DIN touch-proof field dominates the current
alpha's form factor. Each plug is ~8 × 25 mm; 128 of them is a brick.
**Keep the 1.5 mm DIN at the electrode end** (subject-contact safety is
non-negotiable), but **break the harness at the cap-mounted brain-box**
with a single multipole quick-disconnect to the amp.

| Connector | Pitch / ch | Disconnect | Robustness | Shielding | Price | Verdict |
|---|---|---|---|---|---|---|
| Current 130× individual 1.5 mm DIN | individual | **very slow** | good | per-lead | $130+ | keep at electrode end only |
| **D-Sub HD78 / HD104** | 1.27 mm, 78-104 pin | fast | very good | **full metal shell** | $20-30 pair | **Budget quick-win.** 2× HD78 covers 130 leads. Known-good shield reference. Any tech can mate them. |
| **Omnetics A79025 80-pin shielded** | 0.635 mm | fast | **excellent** (MIL/medical) | shielded shell | $100-180 pair | MIL-grade, small, proven in Intan headstages. |
| **LEMO EGG.4B multipole** (40-60 pole) | push-pull | instant | **best in class**, medical-grade | excellent | $200-400 pair | Clinical-grade, beautiful, expensive. Worth it for a beta that sits next to clinical amps. |
| Samtec AcceleRate (ERM8/ERF8) | 0.8 mm | ~1 s | good, not harsh | partial | $30-60 pair | OK for dev, not rugged. |
| 0.5 mm FFC (ZIF) | ribbon | instant | poor under repeat | needs separate shield | $2-5 | Avoid — alpha reliability risk. |

**Beta-rev recommendation**: **2× HD D-Sub HD78** at the brain-box break
for the first rev (cheap, rugged, cleanable, familiar). Upgrade to
**LEMO EGG.4B** on a second rev if the project moves toward clinical
validation.

---

## 7. Cable-management discipline (where alpha rigs die)

1. **Strain relief at PCB entry** — every 1.5 mm DIN plug lands in a bulkhead captive to the enclosure, NOT the PCB. Heyco / Essentra strain-relief bushings (~$0.50 each × 130 = $65). Or 3D-print the bulkhead.
2. **Shield drain continuity** — each 0.6 mm shielded lead terminates its drain to a single star point near the REF2025 analog ground island, NOT to chassis. Double-check ADS131M08 AVSS / DVSS split.
3. **ESD at entry** — board already has `SP0503BAHTG` TVS. **Audit**: verify one TVS channel per electrode lead near the connector. If sparse, the alpha-to-beta change is cheap (32× SP0503 = 96 channels).
4. **Boot/bend radius** — 1.5 mm DIN is fragile at cable-to-plug. Add 3D-printed or silicone boots, or dual-wall heat-shrink (3M EPS-300) with internal hot-melt adhesive.
5. **Pull-test standard** — every plug survives 2 N axial tug indefinitely, 20 N once (loose ISO/IEC 60601-1 strain-relief guidance).
6. **Service loop** — 30-40 mm slack inside the enclosure so plugs can be re-seated without stressing PCB pads.

---

## 8. Architecture implications for the beta rev

Moving the "head-worn" boundary from the PCB to the brain-box changes the
beta design significantly:

- **Brain-box** becomes a real subproject (a passive fan-out PCB designed to sit on the cap near the back of the head, with the multipole quick-disconnect on the far side).
- **Amp board** dimensions are no longer constrained by head-mount. Can be larger, can host a proper 2S Li-ion + ESP32-S3 + RF shield can.
- **Cable between them** becomes a first-class spec: 30-60 cm shielded bundle terminated in HD D-Sub HD78 or LEMO EGG.4B; flex-life + shield continuity are design requirements.
- **Battery math** eases: belt-pack can carry 2S 18650 pair (~90 g, ~25 Wh) without ergonomic pain — plenty for 4-6 h at <500 mA and for future higher sample rates.

---

## 9. Open decisions

- [ ] Brain-box: cap-integrated (sewn into textile cap) vs. rigid puck at the back of the head?
- [ ] Amp-to-brain-box connector: HD D-Sub HD78 (now) or LEMO EGG.4B (clinical future)?
- [ ] Battery: keep USB power bank for alpha; decide LiPo vs 18650 vs LiFePO4 at beta-freeze.
- [ ] Enclosure material: aluminum Hammond for beta v1; CNC custom for beta v2.
- [ ] Add a dummy-load resistor or a 100 µF buffer cap to defeat USB-bank idle cutout — bench-test first.
- [ ] Measure battery-chemistry noise floor on our unit before writing any paper.

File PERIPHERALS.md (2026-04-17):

# FreeEEG128-alpha — Peripheral Inventory & Firmware-Rewrite Targets

Audit of the existing NeuroIDSS alpha board (KiCAD + `.ioc` + `main.c`) so we
know every chip that needs firmware support and every subsystem the rewrite
must own. Source of truth before touching `firmware-stm32cubeide-1.5.1/`.

Audit based on:
- `firmware-freeeeg128-alpha/KiCAD/*.kicad_sch` (schematic hierarchy)
- `firmware-stm32cubeide-1.5.1/STM32H743ZI_ads131_80MHz.ioc` (STM32CubeMX config)
- `firmware-stm32cubeide-1.5.1/Src/main.c` (peripheral init + runtime code)

---

## 1. Chip-level inventory (from schematics)

### 1.1 Compute

| Ref | Part | Notes |
| --- | --- | --- |
| MCU | **STM32H743ZITx** | Cortex-M7 @ 480 MHz, 2 MB flash, 1 MB RAM, DP-FPU, L1 cache |
| HSE crystal | 16 MHz | High-speed external clock for the MCU |
| LSE crystal | 32.768 kHz | RTC / low-speed domain |
| ADC clock | FXO-SM7 (SMD7050) | External oscillator — almost certainly the shared master clock for all 16 ADS131M08s |

### 1.2 Analog front-end (isolated side)

| Ref | Part | Qty | Role |
| ----- | --- | --- | --- |
| ADC | **TI ADS131M08** | 16  | 8-ch, 24-bit, simultaneous-sampling Δ-Σ + differential amp. Per-ADC DRDY, per-ADC RESET (suggested by legacy `reset_ports[]` array in `main.c:262`), daisy-chained or per-CS SPI. |
| VREF  | **TI REF2025** | 1 | Dual 2.5 V / VCOM precision reference (sets ADS131 Vref; the `µV = raw * 1.25e6/((2^23−1)*32)` formula uses Vref 1.25 V because gain 32 halves the input-referred range) |
| PREF  | **ADR4525** | 1 | 2.5 V precision reference, ±0.02 %, 1.5 µVpp noise. Separate ref tree (likely for bias/REF_IN on ADS or a separate rail).  |

### 1.3 Isolation barrier (this is a medically-isolated design — do not break it)

| Ref | Part | Purpose |
| --- | --- | --- |
| ISO_USB | **ADuM3160** | USB 1.1 (Full-Speed) digital isolator — isolates D+/D- between host and MCU |
| ISO_UART | **ADuM1402BRWZ** | Quad digital isolator for an isolated UART channel |
| ISO_SPI | **ISO7341C** | 3-ch digital isolator on the SPI path to (some of) the ADCs  |
| ISO1 | **ISO7341C** | Second 3-ch isolator (additional SPI / control lines) |
| POWER | **SN6505B** | Push-pull transformer driver for isolated DC-DC |
| POWER | **Würth 750315371**  | Transformer for the SN6505 isolated supply |
| USB ESD | SP0503BAHTG | ESD protection on USB data lines |

### 1.4 Power tree

| Ref | Part | Output  | Purpose |
| ----- | --- | --- | --- |
| AVDD  | **LP5907** | low-noise analog | ADS131M08 analog supply |
| VDD | **LP5907** | low-noise | ADS131M08 / reference digital logic supply |
| IOVDD | **LP5907** | low-noise | ADS131M08 IO supply |
| — | **ADP7118AUJZ-3.3** | 3.3 V | Secondary regulator (likely MCU-side or USB-side) |

Three **LP5907** ultra-low-noise LDOs plus the ADP7118 gives a very clean analog rail.
Rails are referenced across the isolation barrier — expect separate grounds (AGND_ISO, DGND_ISO, GND_HOST).

### 1.5 Motion / auxiliary

| Ref  | Part | Purpose |
| ---- | --- | --- |
| IMU  | **ST LSM6DS3TR** | 6-axis accel/gyro over I²C (artifact/motion capture — currently initialized but not published in the paper's capture software) |

### 1.6 Connectors & external IO

| Ref | Part | Notes |
| --- | --- | --- |
| microSD | Molex **473521001** | push-push microSD socket → SDMMC1 |
| USB_DATA | USB-B Micro | host data link (isolated via ADuM3160) |
| USB_POWER | USB-B Micro | separate power input (not carrying data) |
| 2×3 header  | `Conn_02x03` | ISO_SPI debug / programming header |
| 2×3 header  | `Conn_02x03` | ISO_UART header |
| 2×4 header  | `Conn_02x04` | additional ISO1 header |

### 1.7 Misc

- Schottky diodes (D_Schottky) on USB power path
- DA2303 symbol (part unclear — verify in BOM; possibly an LDO or protection device)
- Numerous 100 nF decoupling + 10 µF / 22 µF bulk caps per block

---

## 2. STM32H743 peripherals in use (from `.ioc`)

| STM32 IP | Allocated to | DMA? |
| --- | --- | --- |
| **CORTEX_M7** | ICache **on**, **DCache OFF**, MPU = NULL | — |
| **SPI1** | ADS131M08 group (CS bank) | no DMA requests listed |
| **SPI2** | ADS131M08 group | DMA1 Stream 0 (RX), Stream 1 (TX) |
| **SPI3** | ADS131M08 group | DMA1 Stream 3 (RX), Stream 5 (TX) |
| **SPI4** | ADS131M08 group | DMA2 Stream 2 (RX), Stream 3 (TX) |
| **SPI5** | ADS131M08 group | DMA2 Stream 5 (RX), Stream 6 (TX) |
| **SPI6** | ADS131M08 group (BDMA candidate; no D1/D2 DMA stream allocated) | no |
| **USART1** | isolated UART over ADuM1402 (currently just `HAL_UART_Transmit` debug/print)  | no |
| **I2C1** | LSM6DS3TR IMU (most likely) | no |
| **I2C2** | spare / second I2C bus | no |
| **SDMMC1** | microSD + FatFS | handled by SDMMC internal |
| **USB_DEVICE**  | CDC device (**labeled `VS_USB_DEVICE_CDC_HS`** in the `.ioc`) | — |
| **USB_OTG_HS**  | allocated in IPs, but PB14/PB15 are `Device_Only_FS` — conflict to resolve | — |
| **TIM1** | paced sample-clock generator: `TRGO` feeds DMA1_Stream7 (CIRCULAR, M→P); `UP` feeds DMA2_Stream1 (CIRCULAR, M→P). Typical pattern for GPIO-toggle / CS pulse arrays synchronized to the sample clock. | TIM1_TRIG, TIM1_UP |
| **TIM8** | master clock, combined reset+trigger mode. `TRGO` feeds DMA1_Stream4 (CIRCULAR). TIM8 is the outer cascade driving TIM1. | TIM8_TRIG |
| **FATFS** | via SDIO VS pin | — |
| **DMA1 + DMA2** | both enabled; used by SPI2/3/4/5 + TIM1/TIM8 trigger streams | — |
| **NVIC** | custom priorities for DRDY / DMA complete | — |

### Notable gaps in current firmware

- `ad7779.c` / `ad7779.h` still in `Src/Inc` — **legacy from FreeEEG32 (AD7779 ADCs)**. Likely dead code; delete on rewrite.
- `//#include "W5500/..."` + `//W5500_Select(...)` blocks — commented-out WIZnet Ethernet-over-SPI bring-up. If we want network streaming we can revive this (SPI + CS pin already wired to a header).
- No IWDG / WWDG configured — **watchdog absent** despite long sessions.
- No RTC use despite LSE 32.768 kHz crystal being populated.
- No DFU / bootloader handoff code.

---

## 3. What the firmware rewrite must own

Grouped by subsystem. Anything marked **new** is not in the current codebase.

### 3.1 ADS131M08 array (16 chips, 128 channels)

- 6-SPI-bus layout, up to 3 ADCs per bus via per-CS selection.
- Master clock from FXO-SM7 → all 16 ADCs (off-chip, not our problem).
- **SYNC / RESET**: legacy code references `AD*_RESET_GPIO_Port`. Enumerate every reset + SYNC line in current pinout; modern firmware must issue a simultaneous SYNC across all 16 to start a 128-channel epoch cleanly.
- **DRDY**: `flag_nDRDY_INTERRUPT` exists — one (or more) shared nDRDY line drives an EXTI; firmware must count DRDYs per epoch and detect drops.
- **CRC**: ADS131M08 ships per-sample CRC — forward it to the host stream (current firmware discards it).
- **Config**: expose per-channel OSR, gain, mux, lead-off detection, GPIO, and bias drive over host command protocol (currently all hardcoded).
- **Sample rate**: make `fMOD / OSR` configurable. 250 Hz is firmware-chosen — chip supports up to ~32 kSPS.
- **TIM1/TIM8 cascade**: current trick generates CS pulse patterns at sample rate via DMA-driven GPIO writes. Document it and keep it, or replace with SPI-NSS hardware.

### 3.2 USB CDC link (host interface)

- Decide **FS vs HS** (both configured, conflict in .ioc). ADuM3160 is a **Full-Speed-only isolator** (12 Mbps) — HS cannot pass through it. Lock firmware to FS.
- Budget: 128 ch × 3 bytes × 250 Hz = **96 kB/s raw**. FS (~1 MB/s usable) is ample even at 4 kSPS. HS is unnecessary and would require re-fabbing the isolator.
- **new** Packet framing: length, sequence counter, device timestamp, per-ADC status, end-of-frame CRC. Current stream is raw integers, paper notes save-to-disk took "a few 1000s recordings" to stabilise.
- **new** Host→device command channel (configure channels, start/stop, request status).
- **new** USB re-enumeration / stall recovery.

### 3.3 Isolated UART (USART1 via ADuM1402)

- Currently just a `printf` path. Reclaim for:
  - **new** digital trigger/marker input from the **Labstreamer** (TTL on the isolated side — we stay inside the barrier).
  - **new** auxiliary debug console that doesn't interfere with CDC.
- One spare ADuM1402 channel could be a dedicated trigger line if we wire it to a board-edge header.

### 3.4 microSD (SDMMC1 + FatFS)

- Wired and initialized in current firmware — usage in `main.c` via `sd_diskio.c`, `fatfs.c` — but paper's capture flow doesn't use it.
- **new** Dual-sink streaming: CDC to host + SD log in parallel, with sector-write retries and time-stamped file rotation. Matters for unattended / battery-powered captures.
- **new** On-device session metadata (timestamp, channel map, config) written as a sidecar JSON per file.

### 3.5 IMU (LSM6DS3TR, I²C1)

- **Currently initialized, not published in the data stream.**
- **new** Sample at (say) 104 Hz, low-pass, and interleave an IMU packet into the CDC stream for motion-artifact flags.
- **new** Expose tap / wake-up interrupts — useful as auto-start trigger.

### 3.6 RTC + LSE

- LSE 32.768 kHz populated but RTC not configured.
- **new** Enable RTC for device-side timestamping of SD-logged files (essential when the device streams without a host).

### 3.7 Power & isolation supervision

- No supervisor/PG signals surfaced in .ioc. Verify via schematic whether SN6505/LP5907 have PG pins routed to MCU GPIOs; if so, expose as a health telemetry field.
- **new** Under-voltage / brown-out handling: on rail dip, stop SPI DMAs cleanly and re-SYNC on recovery.

### 3.8 Watchdog + recovery

- **new** IWDG with 2–5 s timeout around the main loop; pet from the USB / SD flush path.
- **new** Reset-cause reporting in a boot banner packet.

### 3.9 Bootloader / firmware update

- **new** Expose a "reboot to DFU" command on the CDC control channel — STM32H7 has a built-in USB DFU bootloader. Avoids the ST-Link/JTAG ritual for updates.
- Current firmware writes directly to flash with no bootloader partitioning.

### 3.10 Ethernet option (revival)

- Commented W5500 code in `main.c` points to a SPI-Ethernet pathway using one of the spare SPI buses + the 2×3 or 2×4 header on the isolated side.
- If wired: **new** LSL-over-UDP outlet from the device itself. Decide whether to invest; USB FS is fine for 128 ch × ≤4 kSPS.

### 3.11 Cache & MPU

- DCache is **disabled** — classic workaround for "DMA buffers in cached memory become stale." The rewrite should:
  - Put DMA buffers in a dedicated non-cacheable region via MPU, or
  - Use `SCB_CleanInvalidateDCache_by_Addr` around buffer swaps, and
  - Re-enable DCache — meaningful speed win for DSP and per-packet CRC.

---
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

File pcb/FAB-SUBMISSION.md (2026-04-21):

# FreeEEG128 — PCB fabrication submission packet

Checklist + packet description for sending the current KiCAD-10-format
design out to a fab-and-assembly (PCBA) house. Intended state:
**KiCAD 10 as-is, no beta-rev schematic edits applied yet**. The
`CHANGES-beta.md` edits (USB-C, LEDs, TTL trigger, STDC14, LT3045,
etc.) are out of scope for this packet — this is the alpha-upgraded
baseline.

See `CHANGES-beta.md` §10 for design-time decisions that precede the
beta-rev schematic edits (different scope from this packet).

## 1. What a fab house gets

```
pcb/out/gerbers/              — 18 gerber files + drill (.drl)
pcb/out/pos.csv               — pick-and-place (centroid) data
pcb/out/bom.csv               — BOM with refs/values/footprints/quantities
pcb/README.md                 — one-page project description
pcb/FAB-SUBMISSION.md         — this file; cover letter + decisions
pcb/reports/drc-baseline.rpt  — optional; DRC summary (0 unconnected)
```

Zip everything under `pcb/out/` plus this file before uploading.
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

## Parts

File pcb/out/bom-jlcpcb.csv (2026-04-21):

Comment | Designator | Footprint | LCSC Part # | Manufacturer Part Number
Conn_02x04_Odd_Even | J303,J301 | PinSocket_2x04_P1.27mm_Vertical |  | 20021311-00008T4LF
LSM6DS3 | U1 | Bosch_LGA-14_3x2.5mm_P0.5mm |  | LSM6DSOXTR
100n | C38,C39,C1,C40,C2,C3,C37,C25,C21,C20,C47,C50,C59,C43,C55,C42,C35,C63,C54,C62,C69,C56,C49,C44,C45,C36,C41,C60,C52 | C_0402_1005Metric |  | CL05B104KO5NNNC
CL1 | C66,C64 | C_0402_1005Metric |  | GRM1555C1H200JA01D
2.2u | C16,C17,C19,C18,C76,C53,C58,C75 | C_0603_1608Metric |  | GRM188R71A225KE15D
4k7 | R84,R85 | R_0402_1005Metric |  | RC0402JR-074K7L
24 | R113,R114,R116,R115 | R_0402_1005Metric |  | RC0402FR-0724RL
Conn_01x02 | J104,J105,J100,J101 | PinHeader_2x01_P2.54mm_Horizontal |  | PRPC001DAAN-RC
LP5907 | U6,U22,U8 | SOT-23-5 |  | LP5907QMFX-3.3Q1
16MHz | Y2 | Crystal_SMD_EuroQuartz_MJ-4Pin_5.0x3.2mm_HandSoldering |  | 7B-16.000MEEQ-T
CL2 | C67,C65 | C_0402_1005Metric |  | GRM1555C1H200JA01D
10u | C68,C70 | C_0603_1608Metric |  | GRM188R60J106ME47D
USB_B_Micro | J103,J99 | USB_Micro-B_Molex-105017-0001 |  | 105017-1001
SW_Push | SW1,SW2 | SW_SPST_B3U-1000P-B |  | B3U-1000P
32768Hz | Y1 | Crystal_SMD_EuroQuartz_EQ161-2Pin_3.2x1.5mm_HandSoldering |  | FC-135 32.7680KA-A5
FXO-SM7_OSC-SMD7050_short | U7 | Oscillator_SMD_EuroQuartz_XO91-4Pin_7.0x5.0mm_HandSoldering |  | CB3LV-3I-8M1920
R_EXT | R117 | R_0402_1005Metric |  | RC0402JR-070RL
Conn_02x02_Odd_Even | J2,J1 | PinHeader_2x02_P2.54mm_Horizontal |  | 68021-404HLF
ADUM1402BRWZ | U16 | SOIC-16W_7.5x10.3mm_P1.27mm |  | ADUM1402BRWZ
Conn_02x03_Odd_Even | J81,J84 | PinHeader_2x03_P2.54mm_Horizontal |  | 68021-406HLF
220nF | C81,C5,C90,C8,C102,C78,C93,C23,C84,C28,C11,C99,C33,C87,C14,C96 | C_0402_1005Metric |  | CC0402KRX5R5BB224
1u | C79,C82,C91,C92,C94,C101,C22,C6,C9,C103,C89,C24,C4,C77,C7,C80,C61,C46,C57,C48,C95,C83,C15,C12,C97,C85,C13,C88,C32,C29,C27,C10,C98,C86,C100,C34 | C_0402_1005Metric |  | CL05A105KO5NNNC
ADS131M08IRSN | U113,U109,U114,U105,U102,U106,U110,U101,U103,U107,U112,U116,U108,U111,U104,U115 | QFN-32-1EP_4x4mm_P0.4mm_EP2.65x2.65mm_ThermalVias |  | ADS131M08IRSN
Conn_02x20_Odd_Even | J207,J203,J201,J205,J208,J204,J202,J206 | PinHeader_2x20_P1.27mm_Vertical_SMD |  | 20021121-00040T4LF
Conn_02x04_Odd_Even | J302 | PinHeader_2x04_P1.27mm_Vertical |  | HPH2-A-08-UA
0 | R112,R110,R109 | R_0402_1005Metric |  | RC0402JR-070RL
REF2025 | U2 | SOT-23-5_HandSoldering |  | REF2025AIDDC
SN6505B | U19 | SOT-23-6_Handsoldering |  | SN6505BDBVR
4.7u | C51 | C_0603_1608Metric |  | C0603C475K9PACTU
STM32H743ZITx | U18 | LQFP-144_20x20mm_P0.5mm |  | STM32H743ZIT6U
ADuM3160 | U17 | SOIC-16W_7.5x10.3mm_P1.27mm |  | ADUM3160BRWZ
D_Schottky | D2,D1 | D_SOD-123 |  | MBR0520LT1G
ISO7341c | U15 | SOIC-16W_7.5x10.3mm_P1.27mm |  | ISO7341CDW
473521001 | U21 | 473521001 |  | 47352-1001
750315371 | T1 | 750315371 |  | 750315371

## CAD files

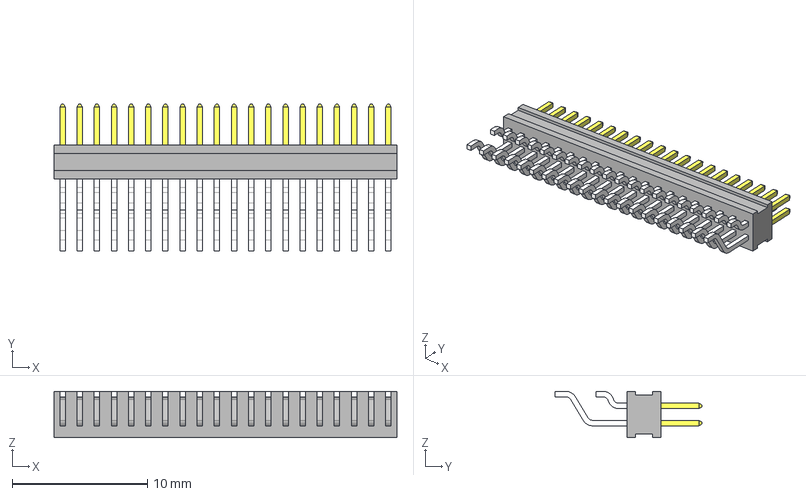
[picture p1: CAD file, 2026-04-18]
pcb/kicad/3d/Connectors/FTSH-120-01-L-DH-TR.stp
25.4 x 10.9 x 3.43 mm
_FTSH-120-01-L-DH-TR_body
_FTSH-120-01-L-DH-TR_pins1
_FTSH-120-01-L-DH-TR_pins2

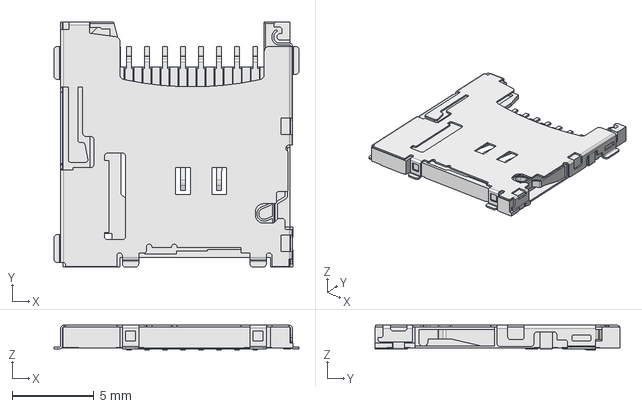
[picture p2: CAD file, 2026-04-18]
pcb/kicad/3d/Connectors/5031821852.step
14.9 x 14.9 x 1.50 mm

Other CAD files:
pcb/kicad/3d/Connectors/5031821852.stp

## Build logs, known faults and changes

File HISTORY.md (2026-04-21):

# A Short History of High-Density EEG

Context for the FreeEEG128 project — the intellectual and engineering
lineage it sits inside. Opens with the theoretical foundations (Nunez) and
the engineering pioneers (Gevins, Tucker/EGI), continues through the
commercial high-density era, and lands at the present open-hardware
generation of which FreeEEG128 is part.

Project owner Morgan Hough was the first software engineering manager at
**Electrical Geodesics, Inc. (EGI)** in the 1990s, where the team built the
**second 256-channel EEG system** in the world. The first was built at
**Neuroscan** by M.E. Pflieger and S.F. Sands, documented in Pflieger &
Sands 1996 [A6] below. The FreeEEG128 design consciously inherits the
EGI / Geodesic Sensor Net approach to high-density acquisition.

---

## 1. Theoretical foundations — Paul Nunez

The modern high-density EEG era is built on Paul Nunez's biophysical
treatment of scalp potentials. His book remains the canonical reference:

> **Nunez, P.L.** *Electric Fields of the Brain: The Neurophysics of EEG*. Oxford University Press (1981). 2nd ed. with **R. Srinivasan**, 2006.

The 2nd edition co-author **Ramesh Srinivasan** bridges the theoretical
(Nunez) and engineering (EGI) sides of the lineage:

- Currently **Professor of Cognitive Sciences and Biomedical Engineering** at UC Irvine, directing the Human Neuroscience Laboratory (<https://hnl.ss.uci.edu/>).
- Was an early part of **Electrical Geodesics, Inc. (EGI)** — so the Nunez-Srinivasan biophysical framework was wired directly into EGI's product line and montaging software during the formative years when Morgan was there as software engineering manager. That is not a coincidence — it is why EGI's systems shipped with Laplacian and averaged-reference options as first-class features.
- Co-authored extensively with Nunez; continues to publish on EEG source localization, coherence, and large-scale neural dynamics.

Key arguments that still shape hardware design today:

- Scalp potential is spatially low-pass-filtered relative to cortical sources — the skull acts as a ~2-3 cm smoothing kernel. This is the **justification for >100 electrodes** (Nyquist-like spatial sampling argument).
- **Reference electrode choice is not neutral.** Any common reference adds a (usually unknown) time-varying term; the surface Laplacian or average reference are preferred for source-localization work.
- Volume conduction means no scalp sensor sees a single source — every decoder has to contend with this.

The specific paper the user flagged with DOI `10.1007/BF01187712` is:

> **Nunez, P.L. & Westdorp, A.F.** "The surface Laplacian, high resolution EEG and controversies." *Brain Topography* **6**, 221-226 (1994). doi:10.1007/BF01187712.

Reading this paper is effectively the entry fee to working on high-density
EEG hardware. Surface Laplacian and related "deblurring" transforms motivate
the channel-count race of the 1990s — without >64 electrodes the math
doesn't pay off.

---

## 2. Engineering pioneer — Alan Gevins

In parallel with Nunez's theoretical work, Alan Gevins built the first
serious engineering practice of high-resolution EEG.

- Founded **EEG Systems Laboratory** (1980, San Francisco; later San Francisco Brain Research Institute / SFBRI), then **SAM Technology** (1986).
- BS MIT 1967; PhD cognitive science 1971. Laboratory director at Langley Porter Neuropsychiatric Institute EEG Lab from 1974.
- **100+ peer-reviewed publications** (5 in *Science*), **19 US patents**, continuous NIH / NSF / AFRL / NRL / DARPA / NASA funding from 1972.
- Reference page: <https://www.eeg.com/alan_gevins.php>

Gevins' engineering-side contributions that matter to FreeEEG128:

- Early systems pushed toward **64 and 128 channels in the late 1980s / early 1990s**, when the commercial norm was 19-32.
- Developed **"deblurring"** methods — combining MRI-derived skull/scalp geometry with scalp EEG to estimate cortical surface potential. This predates modern source-localization and remains an active methodology.
- **MANSCAN** (Mental Attentiveness Neural Signal Coherence ANalysis) and related neurocognitive-pattern-recognition work set the protocol template for sustained-attention and mental-workload studies that the field still uses.
- Demonstrated that **continuous real-time analysis**, not just post-hoc, was feasible with 90s-era hardware — motivating lower-latency acquisition designs.

---

## 3. The engineering breakthrough — Don Tucker & Electrical Geodesics, Inc. (EGI)

The direct ancestor of the FreeEEG128 design philosophy.

- Founded by **Don Tucker** at the University of Oregon (~1992); commercialized the **Geodesic Sensor Net** — a quick-application (~5 min) saline-sponge electrode array wrapped around the head on a tension-distributed elastic polymer scaffold, arranged in a geodesic polyhedron layout for uniform spatial sampling.
- **Second 256-channel EEG system** in the world (after Neuroscan). FreeEEG128's project owner was first software engineering manager at EGI during this era.
- **Ramesh Srinivasan** (Nunez's co-author on *Electric Fields of the Brain* 2nd ed.; now Prof. Cognitive Sciences & Biomedical Engineering at UCI) was an early part of EGI. This is the conduit by which Nunez-style biophysical thinking — surface Laplacian, average reference, volume-conduction–aware montaging — was built directly into EGI's montaging software and product philosophy from the start.
- Key Tucker paper:

  > **Tucker, D.M.** "Spatial sampling of head electrical fields: the geodesic sensor net." *Electroencephalography and Clinical Neurophysiology* **87**, 154-163 (1993).

- Acquired by Philips (2017). The modern NA300 / GTEN lineage comes from this work.
- Design patterns that directly influence FreeEEG128:
  - **>100-channel density is only useful with a practical application workflow** — EGI solved this with saline sponges + elastic scaffold, letting non-specialists apply in ~5 min vs 60+ min for paste-based systems.
  - **Desk/belt-tethered amp + bundled cable to cap** — the form factor we already concluded is correct for 128 ch (see `ENCLOSURE.md`).
  - **Average-reference and vertex-reference montaging in software**, with the physical "reference" electrode treated as just another channel — a design choice that lets users pick references post-hoc.
  - **Per-channel impedance check** shown to the operator before acquisition. This is exactly the gap we've noted in the FreeEEG128 rewrite (see `COMPARISON.md` lessons §4).

---

## 4. The commercial high-density era (1990s - 2010s)

| Vendor | System | Channels | Era | Notes |
|---|---|---|---|---|
| **Neuroscan** | SynAmps / Quik-Cap | up to 256 | early-mid 1990s | **First 256-channel EEG system.** Built by **M.E. Pflieger and S.F. Sands** (principals at Neuroscan); documented in Pflieger & Sands 1996 [A6]. |
| **EGI** | Net Amps / Geodesic Sensor Net | 64 / 128 / 256 | 1992- | Tucker's geodesic scaffold + saline sponges. **Second 256-channel system in the world** — FreeEEG128 project owner Morgan Hough was first software engineering manager during this build. |
| **BioSemi** | ActiveTwo | up to 256 | late 1990s- | **First HD-EEG system with active electrodes** — on-electrode unity-gain buffer eliminates cable capacitance + movement-artifact coupling. The reference choice that defined a generation: BioSemi-vs-BrainVision is still the main "active vs passive" benchmark comparison in most validation studies. |
| BrainProducts | actiCHamp / actiCAP | up to 256 | 2000s- | BrainVision Recorder ecosystem; benchmark for open systems. |
| ANT Neuro | eego / Waveguard | up to 256 | 2000s- | Belt-pack amp + dry-alt caps. |
| Compumedics Neuroscan | SynAmps2 / SynAmps RT | up to 512 | 2000s- | Research / clinical mainstay. |
| g.tec | g.USBamp / g.Nautilus | up to 256 | 2000s- | Modular headbox design. |
| **g.tec** | **g.Pangolin / g.HIamp** | **up to 1024** | **2023-** | **VHD-EEG state-of-the-art.** Flex-PCB active-wet electrode grids, 8.6 mm spacing. 256-ch density achieves 95.2% CS localization vs invasive ECoG (Schreiner et al. 2024). |

Common themes of this era that our project inherits or explicitly moves past:

- **Proprietary everything** — cap, connector, amp, software. Locked ecosystem.
- **Desk-tethered** amps dominate; belt-pack (ANT, BrainProducts LiveAmp) emerges later.
- **Active electrodes at HD scale** — **BioSemi was first**, with the ActiveTwo in the late 1990s. On-electrode unity-gain buffering eliminated cable-capacitance and movement-artifact coupling, and set the standard every later system is compared against. We keep this on the FreeEEG128 v2 roadmap (alpha/beta are passive Ag/AgCl).
- **Per-channel impedance + reference flexibility** become standard — table stakes for the beta.

---

## 4b. The very-high-density frontier — g.Pangolin and 1024-channel EEG (2020s)

A second revolution has been quietly underway since roughly 2020: the move
from "HD-EEG" (64-128 channels) to **ultra- or very-high-density EEG**
(VHD-EEG / uHD-EEG, 256-1024+ channels). The theoretical driver is a
refinement of Nunez's spatial-Nyquist argument — Grover and Venkatesh
(cited in Schreiner et al. 2024) propose on information-theoretic grounds
that the scalp's spatial bandwidth demands not hundreds but *thousands*
of electrode positions to capture all of the information it carries.

The **state-of-the-art commercial VHD system is g.tec's g.Pangolin** — a
1024-channel-capable uHD-EEG platform that Schreiner et al. (2024,
*Scientific Reports*) use to demonstrate non-invasive central-sulcus
mapping at intracranial-comparable accuracy. Key specifications:

- **Up to 1024 channels** via 4× g.HIamp 256-channel amplifiers
- **8.6 mm inter-electrode distance**, **5.9 mm electrode diameter**
- **Flexible printed-circuit electrode grids** (16 channels per grid) with
  gold-plated electrode points
- **Active pre-amplifier** per grid (fixed gain 10) before the g.HIamp
- **Wet electrodes** with conductive paste (e.g., Elefix) applied under an
  adhesive layer designed to prevent bridging and crosstalk
- **24-bit ADC resolution, up to 38.4 kHz sample rate per channel**
- Authors of Schreiner et al. 2024 include **Christoph Guger** (founder of
  g.tec) among g.tec-affiliated researchers

The Schreiner et al. study demonstrates that the g.Pangolin at 256-channel
density can **classify channels as anterior or posterior to the central
sulcus with 95.2% accuracy using SSEP phase-reversal analysis** — a level
of functional precision previously only achievable with surgically
implanted ECoG.

Closely related theoretical and methodological work includes Shirazi,
Onton & Makeig (2025, *bioRxiv*), who simulate scalp EEG from
ultra-high-density ECoG to quantify cortex-to-scalp projection; and Liu
et al. (2018, *Frontiers in Neuroinformatics*), who establish the
systematic benefits of density, head modeling, and source localization
for reconstructing large-scale brain networks. Fiedler et al.'s
256-channel dry cap (2022, *Human Brain Mapping*) covers the
dry-electrode side of the VHD spectrum.

**Where FreeEEG128 sits in this landscape.** We are deliberately not
claiming VHD-EEG status — the open-hardware frontier at 256+ channels
remains commercial-only as of April 2026. FreeEEG128 occupies the
"affordable mid-density open-hardware" niche: higher channel count than
OpenBCI (8-16) and Open Ephys + EEG / Black 2017 (64-128), lower than
g.Pangolin (1024), at roughly one to two orders of magnitude lower cost
than commercial HD systems. A natural upgrade path (`FreeEEG256`) on the
same STM32H743 + ADS131M08 chassis is plausible — 32 ADCs across six SPI
buses plus a second-stage cable design — and would put open hardware
meaningfully closer to the VHD threshold.

## 5. The open-hardware generation (2010s-)

FreeEEG128 sits in this lineage:

| Project | Year | Key move |
|---|---|---|
| **OpenBCI** Cyton | 2014 | First mass-open 8-ch ADS1299 amp. Gave the community a packet format the whole ecosystem adopted. |
| **Open Ephys** acquisition board (Siegle et al.) | 2017 | Plug-in-based GUI + generic Intan-headstage board. 512-ch capacity. |
| **Open Ephys + EEG** (Black et al.) | 2017 | Adapts commercial EEG caps onto Open Ephys. **Primary comparison benchmark for FreeEEG128** (see `COMPARISON.md`). |
| **HackEEG** (Feuer) | ~2018 | 8-32 ch ADS1299 + Arduino Due; dual JSON/MessagePack protocol. |
| **BIOADC** (Gargiulo) | 2019 | First fully open-access 32-ch EEG with full schematic + firmware + electrode release. |
| **PiEEG / IronBCI** | 2020s | Pi-HAT and STM32F4 + ADS1299; explicit FreeEEG32 successor. Validation preprint vs BioSemi. |
| **FreeEEG32-beta** (NeuroIDSS / Vivancos) | 2021 | Proved ADS131M08 (vs industry-default ADS1299) hits research-grade noise. |
| **FreeEEG128-alpha** (NeuroIDSS) | 2023 | 16× ADS131M08 scale-up; STM32H743; ~5 units worldwide. |
| **Cardona-Álvarez et al. OpenBCI framework** | 2023 | Custom-driver overhaul of OpenBCI Cyton+Daisy; Raspberry Pi as acquisition server; Kafka-distributed compute; LDR-based marker sync. Most detailed published architecture for an open-hardware BCI framework. Sensors **23**, 3763. |
| **Neurogate OctaFlow** | 2024 | ESP32-C3 + ADS1299, 8-ch, LSL/WebSocket native. Adafruit-ecosystem-compatible teaching board. |
| **FreeEEG128 beta** (this project) | 2026- | STM32H743 + ESP32-S3 co-processor; cap-mounted brain-box + belt-pack amp; CERN-OHL-S licensing; Open Ephys GUI + BrainFlow + LSL native. |

---

## 6. What FreeEEG128 inherits from each lineage

- **From Nunez**: electrode density justification, reference-scheme agnosticism, surface-Laplacian readiness.
- **From Gevins**: real-time analysis mindset, mental-workload / cognitive-state paradigm library for validation studies.
- **From Tucker / EGI**: practical >100-channel application workflow, desk/belt-tethered form factor, per-channel impedance as a first-class operator-facing feature, software-defined referencing.
- **From BioSemi**: active electrodes at HD scale — BioSemi was the first to productize this combination in the late 1990s, and it remains the gold standard for movement-tolerant recording. Kept on the FreeEEG128 roadmap as a v2 option (our current cap is passive Ag/AgCl).
- **From Open Ephys + EEG (Black 2017)**: plugin-GUI integration path, eyes-closed alpha vs actiCHamp as the validation gate.
- **From OpenBCI**: a shared binary packet format + BrainFlow board identity so the whole open-source toolchain works day-one.
- **From IronBCI**: device-side µs timestamps, published validation vs a clinical amp as the credibility gate.

---

## 7. Open citations to resolve / add

- [ ] Tucker 1993 (Geodesic Sensor Net original paper) — confirm pages / DOI for `REFERENCES.md`.
- [ ] Canonical Gevins "deblurring" paper (likely Gevins et al. 1994 *IEEE EMBS Mag*, or a *Science* paper) — the user may want to name the specific reference.
- [ ] EGI-era Nunez & Srinivasan 2006 2nd ed. citation.
- [ ] Any Morgan-Hough-authored EGI-era publications the user wants surfaced.

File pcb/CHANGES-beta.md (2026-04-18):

# FreeEEG128-beta — schematic and layout change list

Design document for the `FreeEEG128-beta` revision. Starting point is the
KiCAD 10 baseline committed in [`README.md`](README.md) (upstream
NeuroIDSS alpha, format-upgraded only, zero design changes yet).

**MCU decision already settled**: STM32H743ZIT6 retained. STM32N6 deferred
to a future v2 — see the MCU-choice memory and [`../ROADMAP.md`](../ROADMAP.md)
§B0.1.

This doc is the plan-of-record before any schematic or layout edit. Every
change below lists:

- **Why**: the lesson / bug / goal driving it
- **Where**: which sheet(s) of the hierarchical schematic are touched
- **What**: the specific component swap / addition
- **Layout impact**: the footprint / edge / routing consequence
- **Proposed MPN**: a concrete part to spec (subject to 2026 availability check)

---

## 1. Connector upgrades (the alpha failure mode)

### 1.1 USB Micro-B → USB-C on both J99 and J103

**Why.** Both alpha units we've tested fail to enumerate on any host. The
unused plastic-wrapped FreeEEG32 fails identically. The common factor is
the SMT Micro-B receptacle (Molex 105017-1001) — notoriously fragile
solder joints and loose mechanical coupling. USB-C is the 2026 standard,
has far more robust mechanical retention, and is reversible.

**Where.** `USB_DATA.kicad_sch` (J99) and `USB_POWER.kicad_sch` (J103).

**What.** Replace the two `USB_Micro-B_Molex-105017-0001` footprints with
a USB-C 2.0 receptacle (sink only; we don't need USB-PD since the board
draws <5 W).

**Layout impact.** USB-C receptacle is physically larger (~8.9 × 7.3 mm
SMT mid-mount) than Micro-B (~6 × 5 mm). The board edge near the USB
ports needs ~3-4 mm more clearance per connector. Verify the octagonal
outline still hosts both connectors back-to-back — we may need to grow
one facet of the octagon by 4-5 mm.

**Proposed MPN.**

- Preferred: `GCT USB4125-GF-A-180` — USB-C 2.0, 16-pin, SMT mid-mount,
  through-hole board-lock posts, ~$0.50 @ qty 100. Well stocked on
  Digi-Key / Mouser / LCSC.
- Alt: `Amphenol 10118194-0001LF` — similar class, widely available.
- Alt (medical-grade): `Wuerth 632723100011` — shielded top-mount.

**Wiring.** USB-C 2.0 → USB 2.0 uses pins A4/A5 VBUS, A6/A7 D+/D-, A1/A12
GND, B6/B7 D+/D- (mirrored), B1/B12 GND. Tie VBUS pairs, GND pairs, D+
pairs, D- pairs together on the board. CC1/CC2 each need a 5.1 kΩ
pull-down to GND to advertise as a UFP (sink) — no CC-logic chip needed
for USB 2.0 only.

### 1.2 Debug header: 2×5 0.1″ → STDC14 fine-pitch 1.27 mm

**Why.** Modern ST-Link V3 (our planned firmware-rewrite debugger) ships
with an STDC14 (Samtec FTSH 2×7 1.27 mm) cable as its default. The alpha's
2×5 0.1″ header is legacy hobbyist pitch and needs a $10 adapter in every
session. STDC14 also routes SWDIO/SWCLK/SWO, 3.3 V, GND, TX/RX, NRST, and
extra IO in one shrouded connector — future-proof.

**Where.** `MCU.kicad_sch` (the SWD header near the STM32).

**What.** Replace `PinSocket_2x05_P2.54mm_Vertical` with
`Samtec_FTSH-107-01-x-DV_2x07_P1.27mm_Vertical`.

**Layout impact.** STDC14 is ~10.4 × 4.8 mm vs ~13.0 × 7.6 mm for the old
2×5 0.1″ — *saves* PCB real estate. Routing is cleaner (shrouded).

**Proposed MPN.** `Samtec FTSH-107-01-L-DV-K-TR` (surface-mount, keyed).

---

## 2. Status LEDs (the "is it alive?" problem)

**Why.** The alpha has zero LEDs. Today's diagnostic session spent 90
minutes proving it wasn't a power issue with no visual indicator to
confirm anything. Status LEDs are cheap ($0.05 per LED) and save hours of
debugging over the lifetime of the platform.

**Where.** Various sheets — grouped per supply rail and function.

**What to add (6 LEDs):**

| Ref  | Color  | Driven by | Meaning | Sheet |
| ---- | --- | --- | --- | --- |
| D_PG_H | red | USB_DATA VBUS (host side) | "host USB plugged in" | `USB_DATA.kicad_sch` |
| D_PG_I | green  | isolated 5 V after SN6505 | "isolated power good" | `POWER.kicad_sch` |
| D_AVDD | green  | AVDD 3.3 V rail post-LT3045 | "analog supply up" | `AVDD.kicad_sch` |
| D_VDD  | green  | VDD 3.3 V rail post-LP5907 | "digital supply up" | `VDD.kicad_sch` |
| D_USR1 | blue | STM32 GPIO | firmware-controlled (CDC active) | `MCU.kicad_sch` |
| D_USR2 | blue | STM32 GPIO | firmware-controlled (SD activity / fault) | `MCU.kicad_sch` |

**Layout impact.** Six 0603 footprints + six 0603 resistors = ~0.5 cm² per
LED+resistor pair. Place the power-good LEDs on the *same face as their
rail's connector* so you can see them at a glance while debugging.

**Proposed MPN.** Any standard 0603 LED family — Kingbright
`APT2012SRCPRV` (red), `APT2012LSECK` (green), `APT2012QBC-D` (blue),
with `RC0603JR-074K7L` 4.7 kΩ current-limit resistors (≈0.7 mA from
3.3 V; dim but enough to see and low power).

---

## 3. Isolated TTL trigger input for Labstreamer

**Why.** The alpha has no stimulus-sync input at all. The Labstreamer
(already on hand) speaks TTL on BNC. Adding a proper isolated trigger
input lets us drop Labstreamer markers directly into the EEG stream and
pass the Black 2017 validation gate (eyes-closed alpha + later P300
latency).

**Where.** New subsheet `TRIGGER.kicad_sch`. Panel-mount connector on the
amp-box enclosure, wires through an isolator into a spare STM32 GPIO.

**What.**

1. Panel-mount connector on the enclosure face: **3.5 mm TRS** (CUI
   `SJ-3523-SMT`) — compact, common on clinical amps, or **BNC** if we
   want lab-standard and don't mind the volume.
2. Input ESD protection: `SP0503BAHTG` (already in BOM).
3. Schmitt-trigger input buffer: `74LVC1G17` (single Schmitt, SC-70) for
   clean logic edges from the TTL source.
4. Isolation across the medical barrier: one spare ADuM1402 channel
   (isolator already on the board has 4 channels; the ISO_UART sheet
   uses 2 for TX/RX; 2 remain — use one of them).
5. Terminate at an STM32 GPIO with EXTI capability (TIM input-capture
   GPIO preferred for timestamping in firmware).

**Layout impact.** ~1 cm² for the Schmitt + isolator-channel wiring,
plus the panel connector (which can be a fly-lead rather than on the
PCB if enclosure geometry demands).

**Note on Labstreamer integration.** The Labstreamer has multiple TTL
out lines (BNC). Wire its "event strobe" output → 3.5 mm → ESD → Schmitt →
ADuM1402 spare channel → STM32 EXTI / TIM input capture. Firmware
timestamps the rising edge with µs precision and emits a marker packet
in-band with the EEG stream.

---

## 4. Lock USB to Full-Speed in the hardware + firmware

**Why.** The alpha's `.ioc` configures both `USB_DEVICE` (FS) and
`USB_OTG_HS` simultaneously, with PB14/PB15 as `Device_Only_FS`. The
ADuM3160 isolator is **FS-only** (12 Mbps max) — HS cannot pass through
it. This is a firmware-side cleanup: remove `USB_OTG_HS` from the pin
allocations, route any freed pins to other uses.

**Where.** `MCU.kicad_sch` (pin labels), firmware `.ioc`.

**What.** Mark PB14/PB15 as FS-only in the schematic labels. Any pins
previously allocated to HS PHY get freed for GPIO use (LED drive, trigger
input, etc.).

**Layout impact.** None — pins stay in place, just the net names change.

---

## 5. BOM refresh (2026 availability + small upgrades)

### 5.1 IMU: LSM6DS3TR → LSM6DSOXTR

**Why.** LSM6DSOXTR is newer, still in production through 2030+, lower
power, better temperature stability. Already listed as the first alt MPN
in the 2021 BOM.

**Where.** `ACCEL&GYRO.kicad_sch`.

**What.** Swap `LSM6DS3TR` → `LSM6DSOXTR`. Pin-compatible 14-LGA package;
schematic symbol needs Value edit only; footprint unchanged.

### 5.2 Add LT3045 on AVDD rail

**Why.** The LP5907 on AVDD (6.5 µVrms, 10 Hz-100 kHz) is fine. The
LT3045 is the industry low-noise gold standard: **0.8 µVrms** across
10 Hz-100 kHz, 79 dB PSRR at 1 MHz, 500 mA. An 8× noise improvement on
the analog rail is meaningful for a 24-bit Δ-Σ front-end.

**Where.** `AVDD.kicad_sch`.

**What.** Replace LP5907 on AVDD with LT3045. VDD and IOVDD rails stay
on LP5907 (good enough for digital).

**Layout impact.** LT3045 is 12-lead MSOP (3×3 mm) vs LP5907 SOT-23-5
(1.6×2.9 mm). Slightly larger footprint, needs a ground-pour exposed pad
for thermal dissipation under the part.

**Proposed MPN.** `LT3045EMSE#PBF` (12-MSOP) or `LT3045EDD#PBF` (DFN).
Prefer MSOP for hand-assembly friendliness and visual inspection.

### 5.3 Full BOM pass on 36 line items

To be done separately: verify each MPN on Digi-Key / Mouser / LCSC for
April 2026 availability. Swap any EOL parts for the alt MPNs already
listed in the original BOM (columns 9-12). Specifically to audit:

- STM32H743ZIT6 — should be fine (long lifecycle), but verify stock
- ADS131M08 — verify 16× qty available in one lot
- ADUM3160BRWZ / ADUM1402BRWZ / ISO7341CDW — all current
- SN6505BDBVR — current
- REF2025AIDDC / ADR4525 — both current
- Crystals (EuroQuartz 7B-16.000MEEQ-T, FC-135 32.768 kHz, FXO-SM7) —
  crystal supply is volatile; have alts lined up
- Molex 473521001 (microSD) — current

### 5.4 Consider adding

- **TVS on isolated side power rails** (extra ESD protection on the
  subject-contact side — low cost insurance for a medical-adjacent device).
- **Explicit layer stackup spec** in the PCB fab package: 4-layer FR4,
  controlled-impedance on SPI nets, typical 50 Ω single-ended.

---

## 6. Firmware-facing minor changes

### 6.1 BOOT0 strap — confirm wired through a button

The alpha has a user button near the USB_POWER side (visible in IMG_1612).
Confirm via schematic whether it's a **BOOT0 select** (holds chip in
system DFU bootloader on reset) or a user input. If it's not a BOOT0
strap, add one — lets us enter DFU mode cleanly without TDK pad-poking.

### 6.2 Reset button audit

Confirm a dedicated NRST button exists separate from BOOT0. On alpha
hardware the two are sometimes combined — not great for debugging.

### 6.3 SD-CD (card detect) → GPIO

Wire the microSD's CD switch to a GPIO so firmware knows when a card is
inserted. Saves polling the SDMMC.

---

## 7. What we explicitly keep unchanged

- STM32H743ZIT6 acquisition MCU (settled)
- 16× ADS131M08 analog front-end (the whole reason for the design)
- Six SPI buses (SPI1-SPI6) routing plan
- ADuM3160 USB-FS isolator
- ADuM1402 UART isolator
- 2× ISO7341C SPI isolators
- SN6505B + Würth 750315371 transformer push-pull isolated DC-DC
- REF2025 / ADR4525 precision references
- 3× LP5907 LDOs for VDD/IOVDD (keep) — AVDD is the only rail moving to LT3045
- Octagonal board outline (ideally — see §1.1 note about possible edge growth)
- 10/5 cap connector scheme (1.5 mm DIN touch-proof at electrode end
  remains; beta connector work is at the brain-box ↔ amp break — see
  [`../ENCLOSURE.md`](../ENCLOSURE.md), HD D-Sub HD78)

---

## 8. Layout implications summary

| Change | Δ Area | Δ Routing |
| --- | --- | --- |
| USB-C x2 (was Micro-B x2) | **+4-5 mm** on one edge | D+/D- and VBUS/GND repoured |
| STDC14 header | **−20 %** on MCU edge header | tighter SWD trace group |
| 6 × status LEDs | +3 cm² total, distributed | 6 × short GPIO / rail traces |
| TTL trigger chain | +1-2 cm² near edge | 1 × Schmitt + isolator channel |
| LT3045 on AVDD | +3 mm² vs LP5907 | slightly larger thermal pad |
| LSM6DS3 → LSM6DSOXTR | 0 | 0 (pin-compat) |
| BOOT0 button + SD-CD wiring  | 0 | 2 × short GPIO |

**Net PCB area change**: likely +5-8 % on one edge of the octagonal
outline to absorb the USB-C footprint growth. Everything else is within
existing keepout / silkscreen budget.

---

## 9. Sequencing

1. **Schematic edits** (§1-4, 6): in KiCAD Schematic Editor on the NUC.
   Can do most symbol swaps and additions via the GUI. ERC baseline
   should come down significantly once library links are resolved.
2. **Symbol / footprint setup**: add new footprints for USB-C, STDC14,
   LT3045 to a local `beta.pretty` library; verify pin mapping against
   datasheets.
3. **PCB layout edits** (§1, 2, 3, 5.2): in KiCAD PCB Editor. Largest
   lift is the USB-C re-layout near the board edge. Preserve the six
   SPI-bus analog routing carefully — don't let the USB-C work disturb
   it.
4. **DRC + ERC** clean pass. Target: 0 unconnected, 0 errors, warnings
   reviewed and dismissed only if justified.
5. **Regenerate fab artefacts** via `kicad-cli` (same commands as
   [`README.md`](README.md)).
6. **BOM rebuild**: full 2026 availability audit + new parts priced.
7. **Fab quote** from 2-3 houses (JLCPCB, PCBWay, MacroFab). Decide
   qty and timeline.
8. **Review the design** at the quote stage against the validation gate
   (can we reproduce Black 2017 eyes-closed alpha with this rev?).

---

## 10. Open decisions for the user

Before any edit starts:

- [ ] TTL trigger input connector: **3.5 mm TRS** (compact) or **BNC**
  (lab-standard)?
- [ ] LT3045 package preference: **MSOP** (hand-solderable) or **DFN**
  (smaller, reflow-only)?
- [ ] Keep the octagonal board outline, or make it a simple rectangle if
  the USB-C edge growth breaks the 8-fold symmetry? (Octagonal is
  distinctive and matches the "geodesic" brand heritage; rectangle is
  easier to pack into a belt-pack enclosure.)
- [ ] Target fab quantity: 5, 10, 20?
- [ ] Target fab house: JLCPCB (cheap, Chinese), PCBWay (mid), MacroFab
  (US-assembled), or Seeed Fusion?
- [ ] Any additional must-haves before fab? (RTC battery backup? Extra
  user IO? External flash for firmware large-binary storage?)

---

## 11. Done when

- New schematic compiles under `kicad-cli sch erc` with < 50 remaining
  violations (down from 2,328), all justified.
- New PCB passes `kicad-cli pcb drc` with 0 unconnected items, 0 errors,
  < 100 warnings (down from 1,129), all silk/mask cosmetic.
- Full fab bundle regenerates cleanly into `pcb/out-beta/`.
- `CHANGES-beta.md` ticks every checkbox in §10.
- Fab quote in hand from at least two vendors.

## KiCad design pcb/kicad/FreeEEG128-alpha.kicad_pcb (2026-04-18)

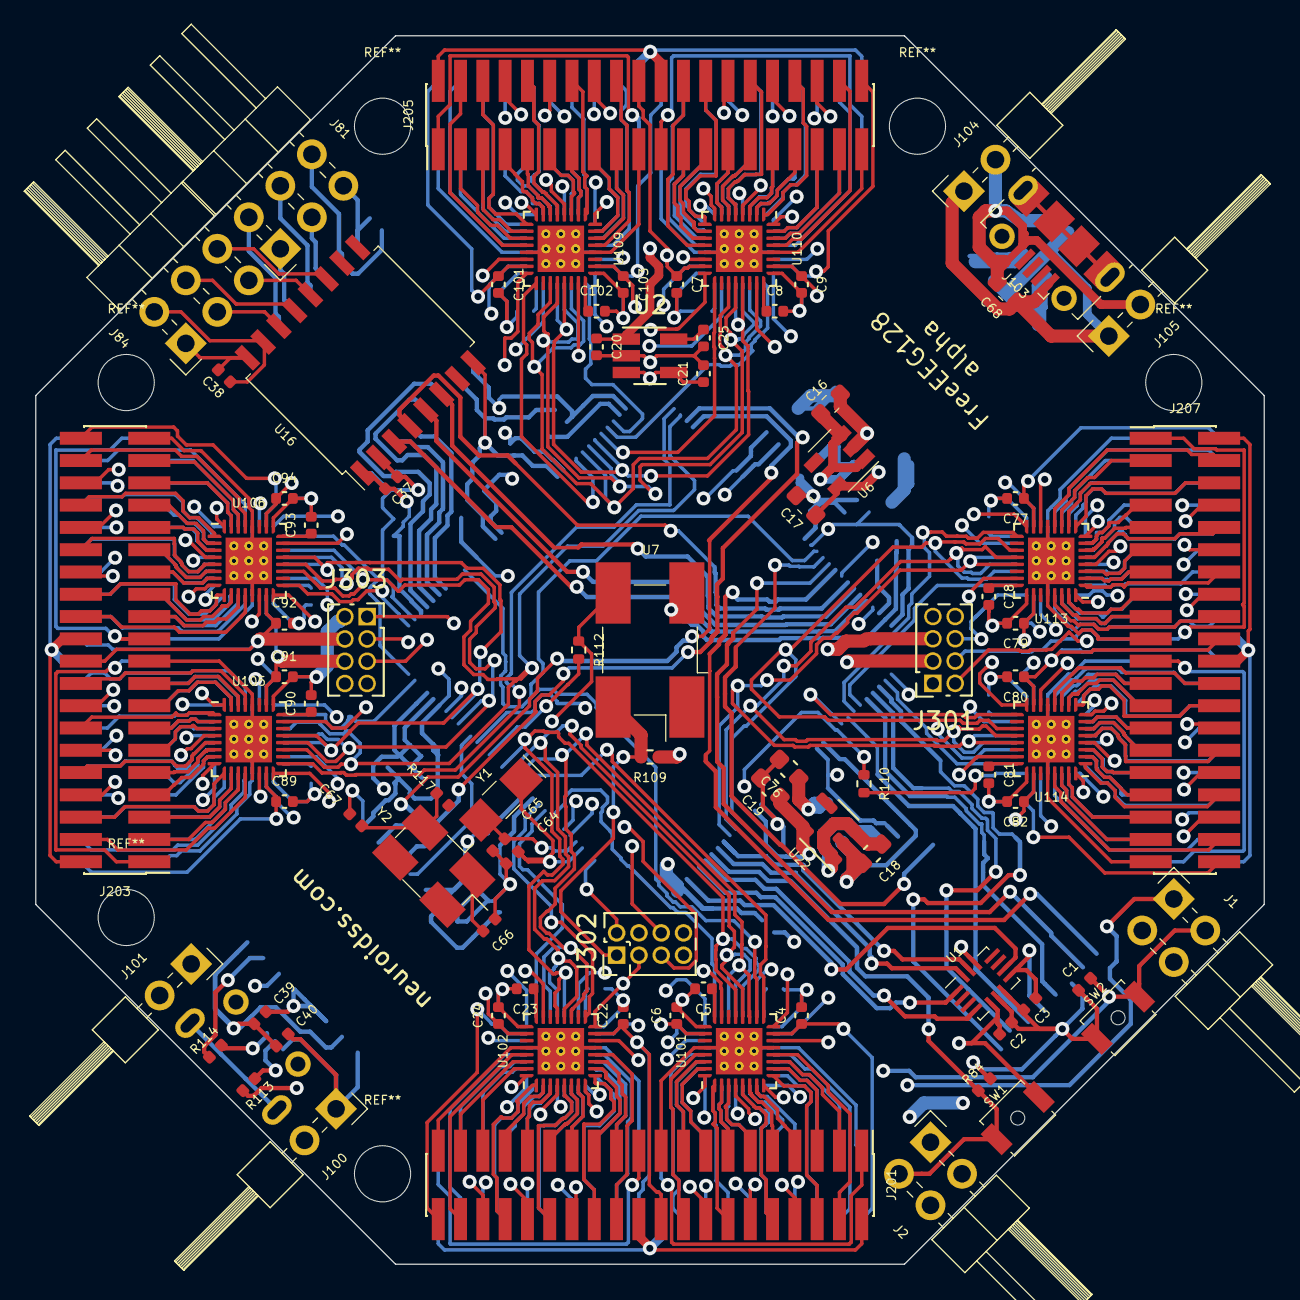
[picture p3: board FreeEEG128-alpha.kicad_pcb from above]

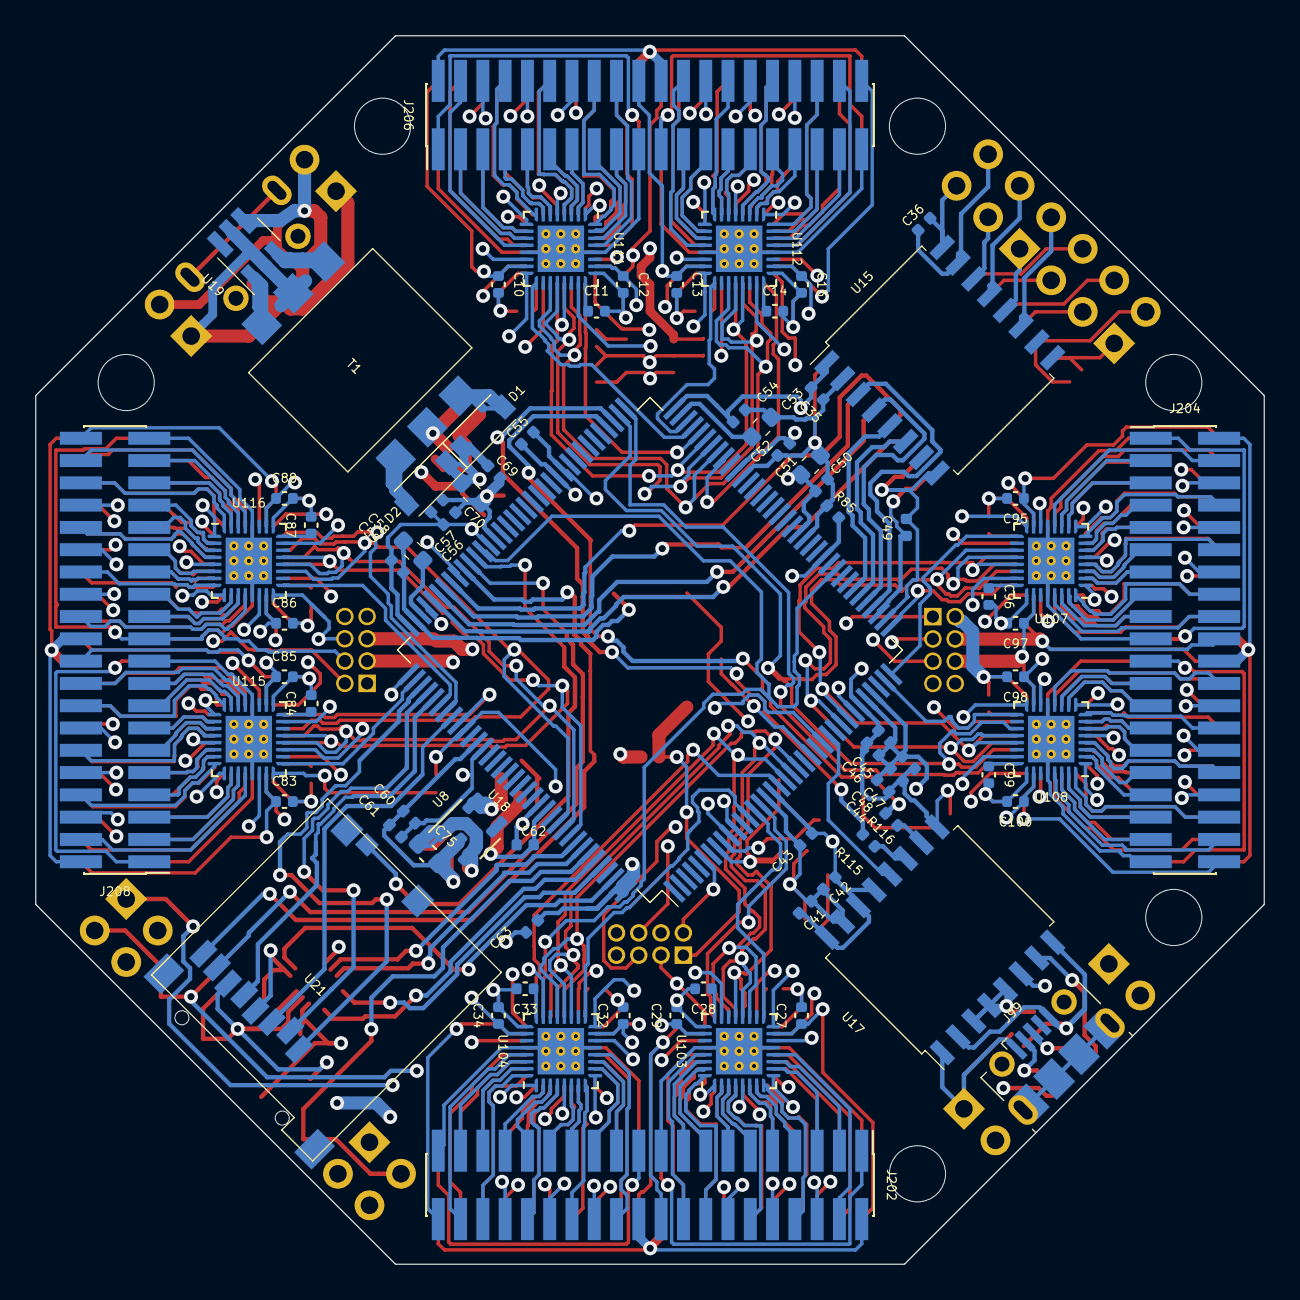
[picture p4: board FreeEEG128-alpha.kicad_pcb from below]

Board: 4 copper layers, 70.0 x 70.0 mm, 162 parts (77 on the bottom side), 379 nets.

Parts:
C1, C2, C3, C20, C21, C25, C35, C36, C37, C38, C39, C40, C41, C42, C43, C44, C45, C47, C49, C50, C52, C54, C55, C56, C59, C60, C62, C63, C69: 100n; C_0402_1005Metric
C4, C6, C7, C9, C10, C12, C13, C15, C22, C24, C27, C29, C32, C34, C46, C48, C57, C61, C77, C79, C80, C82, C83, C85, C86, C88, C89, C91, C92, C94, C95, C97, C98, C100, C101, C103: 1u; C_0402_1005Metric
C5, C8, C11, C14, C23, C28, C33, C78, C81, C84, C87, C90, C93, C96, C99, C102: 220nF; C_0402_1005Metric
C16, C17, C18, C19, C53, C58, C75, C76: 2.2u; C_0603_1608Metric
C51: 4.7u; C_0603_1608Metric
C64, C66: CL1; C_0402_1005Metric
C65, C67: CL2; C_0402_1005Metric
C68, C70: 10u; C_0603_1608Metric
D1, D2: D_Schottky; D_SOD-123
J1, J2: Conn_02x02_Odd_Even; PinHeader_2x02_P2.54mm_Horizontal
J81, J84: Conn_02x03_Odd_Even; PinHeader_2x03_P2.54mm_Horizontal
J99, J103: USB_B_Micro; USB_Micro-B_Molex-105017-0001
J100, J101, J104, J105: Conn_01x02; PinHeader_2x01_P2.54mm_Horizontal
J201, J202, J203, J204, J205, J206, J207, J208: Conn_02x20_Odd_Even; PinHeader_2x20_P1.27mm_Vertical_SMD
J301, J303: Conn_02x04_Odd_Even; PinSocket_2x04_P1.27mm_Vertical
J302: Conn_02x04_Odd_Even; PinHeader_2x04_P1.27mm_Vertical
R84, R85: 4k7; R_0402_1005Metric
R109, R110, R112: 0; R_0402_1005Metric
R113, R114, R115, R116: 24; R_0402_1005Metric
R117: R_EXT; R_0402_1005Metric
SW1, SW2: SW_Push; SW_SPST_B3U-1000P-B
T1: 750315371
U1: LSM6DS3; Bosch_LGA-14_3x2.5mm_P0.5mm
U2: REF2025; SOT-23-5_HandSoldering
U6, U8, U22: LP5907; SOT-23-5
U7: FXO-SM7_OSC-SMD7050_short; Oscillator_SMD_EuroQuartz_XO91-4Pin_7.0x5.0mm_HandSoldering
U15: ISO7341c; SOIC-16W_7.5x10.3mm_P1.27mm
U16: ADUM1402BRWZ; SOIC-16W_7.5x10.3mm_P1.27mm
U17: ADuM3160; SOIC-16W_7.5x10.3mm_P1.27mm
U18: STM32H743ZITx; LQFP-144_20x20mm_P0.5mm
U19: SN6505B; SOT-23-6_Handsoldering
U21: 473521001
U101, U102, U103, U104, U105, U106, U107, U108, U109, U110, U111, U112, U113, U114, U115, U116: ADS131M08IRSN; QFN-32-1EP_4x4mm_P0.4mm_EP2.65x2.65mm_ThermalVias
Y1: 32768Hz; Crystal_SMD_EuroQuartz_EQ161-2Pin_3.2x1.5mm_HandSoldering
Y2: 16MHz; Crystal_SMD_EuroQuartz_MJ-4Pin_5.0x3.2mm_HandSoldering

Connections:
/ADC1/24_CAP: C5.1, U101.24 (CAP)
/ADC2/24_CAP: C23.1, U102.24 (CAP)
/ADC3/24_CAP: C28.1, U103.24 (CAP)
/ADC4/24_CAP: C33.1, U104.24 (CAP)
/ADC5/24_CAP: C90.1, U105.24 (CAP)
/ADC6/24_CAP: C93.1, U106.24 (CAP)
/ADC7/24_CAP: C96.1, U107.24 (CAP)
/ADC8/24_CAP: C99.1, U108.24 (CAP)
/ADC9/24_CAP: C102.1, U109.24 (CAP)
/ADC10/24_CAP: C8.1, U110.24 (CAP)
/ADC11/24_CAP: C11.1, U111.24 (CAP)
/ADC12/24_CAP: C14.1, U112.24 (CAP)
/ADC13/24_CAP: C78.1, U113.24 (CAP)
/ADC14/24_CAP: C81.1, U114.24 (CAP)
/ADC15/24_CAP: C84.1, U115.24 (CAP)
/ADC16/24_CAP: C87.1, U116.24 (CAP)
/MCU/8_PC14: C64.1, U18.8 (PC14), Y1.1
/MCU/9_PC15: C65.1, U18.9 (PC15), Y1.2
/MCU/71_VCAP_1: C53.1, U18.71 (VCAP1)
/MCU/106_VCAP_2: C58.1, U18.106 (VCAP2)
ACC_1_SDO_SAO: U1.1 (SDO/SA0), U18.140 (PB9)
ACC_4_INT1: U1.4 (INT1), U18.139 (PB8)
ACC_6_GND: C1.1, C2.2, C3.2, C4.2, C5.2, C6.2, C7.2, C8.2, C9.2, C10.2, C11.2, C12.2, C13.2, C14.2, C15.2, C16.2, C17.2, C18.2, C19.2, C20.2, C21.2, C22.2, C23.2, C24.2, C25.2, C27.2, C28.2, C29.2, C32.2, C33.2, C34.2, C35.2, C37.2, C41.2, C42.2, C43.2, C44.2, C45.2, C46.2, C47.2, C48.2, C49.2, C50.2, C51.2, C52.2, C53.2, C54.2, C55.2, C56.2, C57.2, C58.2, C59.2, C60.2, C61.2, C62.2, C63.2, C64.2, C65.2, C66.2, C67.2, C69.2, C70.2, C75.2, C76.2, C77.2, C78.2, C79.2, C80.2, C81.2, C82.2, C83.2, C84.2, C85.2, C86.2, C87.2, C88.2, C89.2, C90.2, C91.2, C92.2, C93.2, C94.2, C95.2, C96.2, C97.2, C98.2, C99.2, C100.2, C101.2, C102.2, C103.2, J2.2, J201.19, J201.39, J202.19, J202.39, J203.19, J203.39, J204.19, J204.39, J205.19, J205.39, J206.19, J206.39, J207.19, J207.39, J208.19, J208.39, J301.1, J303.2, R84.2, R85.2, SW2.1, T1.5, U1.6 (GND), U1.7 (GND), U2.2 (GND), U6.2 (GND), U7.2 (GND), U8.2 (GND), U15.2 (GND1), U15.8 (GND1), U16.2 (GND1), U16.8 (GND1), U17.9 (GND2), U17.15 (GND2), U18.16 (VSS), U18.31 (VSSA), U18.38 (VSS), U18.51 (VSS), U18.61 (VSS), U18.83 (VSS), U18.94 (VSS), U18.107 (VSS), U18.120 (VSS), U18.130 (VSS), U21.6 (Vss), U22.2 (GND), U101.13 (AGND), U101.25 (DGND), U101.28 (AGND), U101.33 (Thermal_pad), U102.13 (AGND), U102.25 (DGND), U102.28 (AGND), U102.33 (Thermal_pad), U103.13 (AGND), U103.25 (DGND), U103.28 (AGND), U103.33 (Thermal_pad), U104.13 (AGND), U104.25 (DGND), U104.28 (AGND), U104.33 (Thermal_pad), U105.13 (AGND), U105.25 (DGND), U105.28 (AGND), U105.33 (Thermal_pad), U106.13 (AGND), U106.25 (DGND), U106.28 (AGND), U106.33 (Thermal_pad), U107.13 (AGND), U107.25 (DGND), U107.28 (AGND), U107.33 (Thermal_pad), U108.13 (AGND), U108.25 (DGND), U108.28 (AGND), U108.33 (Thermal_pad), U109.13 (AGND), U109.25 (DGND), U109.28 (AGND), U109.33 (Thermal_pad), U110.13 (AGND), U110.25 (DGND), U110.28 (AGND), U110.33 (Thermal_pad), U111.13 (AGND), U111.25 (DGND), U111.28 (AGND), U111.33 (Thermal_pad), U112.13 (AGND), U112.25 (DGND), U112.28 (AGND), U112.33 (Thermal_pad), U113.13 (AGND), U113.25 (DGND), U113.28 (AGND), U113.33 (Thermal_pad), U114.13 (AGND), U114.25 (DGND), U114.28 (AGND), U114.33 (Thermal_pad), U115.13 (AGND), U115.25 (DGND), U115.28 (AGND), U115.33 (Thermal_pad), U116.13 (AGND), U116.25 (DGND), U116.28 (AGND), U116.33 (Thermal_pad)
ACC_9_INT2: U1.9 (INT2), U18.142 (PE1)
ACC_12_CS: C2.1, C3.1, C19.1, C35.1, C37.1, C41.1, C42.1, C43.1, C44.1, C45.1, C46.1, C47.1, C48.1, C49.1, C50.1, C51.1, C52.1, C54.1, C55.1, C56.1, C57.1, C59.1, C60.1, C61.1, C62.1, C63.1, J2.1, J301.5, J302.2, R109.1, SW1.1, U1.5 (VDDIO), U1.8 (VDD), U1.12 (CS), U15.1 (VCC1), U16.1 (VCC1), U17.13 (SPD), U17.14 (VDD2), U17.16 (VBUS2), U18.6 (VBAT), U18.17 (VDD), U18.30 (VDD), U18.32 (VREF+), U18.33 (VDDA), U18.39 (VDD), U18.52 (VDD), U18.62 (VDD), U18.72 (VDD), U18.84 (VDD), U18.95 (VDD33_USB), U18.108 (VDD), U18.121 (VDD), U18.131 (VDD), U18.143 (PDR_ON), U18.144 (VDD), U21.4 (VDD), U22.5 (OUT)
ACC_13_SCL: U1.13 (SCL), U18.136 (PB6)
ACC_14_SDA: U1.14 (SDA), U18.137 (PB7)
ADC1_01_AIN2P: J201.14, U101.1 (AIN2P)
ADC1_02_AIN2N: J201.13, U101.2 (AIN2N)
ADC1_03_AIN3N: J201.11, U101.3 (AIN3N)
ADC1_04_AIN3P: J201.12, U101.4 (AIN3P)
ADC1_05_AIN4P: J201.10, U101.5 (AIN4P)
ADC1_06_AIN4N: J201.9, U101.6 (AIN4N)
ADC1_07_AIN5N: J201.7, U101.7 (AIN5N)
ADC1_08_AIN5P: J201.8, U101.8 (AIN5P)
ADC1_09_AIN6P: J201.6, U101.9 (AIN6P)
ADC1_10_AIN6N: J201.5, U101.10 (AIN6N)
ADC1_11_AIN7N: J201.3, U101.11 (AIN7N)
ADC1_12_AIN7P: J201.4, U101.12 (AIN7P)
ADC1_17_CS: U18.18 (PF6), U101.17 (CS)
ADC1_18_DRDY: U18.46 (PB0), U18.96 (PC6), U101.18 (DRDY)
ADC1_19_SCLK: U18.19 (PF7), U101.19 (SCLK), U102.19 (SCLK), U103.19 (SCLK), U104.19 (SCLK)
ADC1_20_DOUT: U18.20 (PF8), U101.20 (DOUT), U102.20 (DOUT), U103.20 (DOUT), U104.20 (DOUT)
ADC1_21_DIN: U18.21 (PF9), U101.21 (DIN), U102.21 (DIN), U103.21 (DIN), U104.21 (DIN)
ADC1_29_AIN0P: J201.18, U101.29 (AIN0P)
ADC1_30_AIN0N: J201.17, U101.30 (AIN0N)
ADC1_31_AIN1N: J201.15, U101.31 (AIN1N)
ADC1_32_AIN1P: J201.16, U101.32 (AIN1P)
ADC2_01_AIN2P: J201.34, U102.1 (AIN2P)
ADC2_02_AIN2N: J201.33, U102.2 (AIN2N)
ADC2_03_AIN3N: J201.31, U102.3 (AIN3N)
ADC2_04_AIN3P: J201.32, U102.4 (AIN3P)
ADC2_05_AIN4P: J201.30, U102.5 (AIN4P)
ADC2_06_AIN4N: J201.29, U102.6 (AIN4N)
ADC2_07_AIN5N: J201.27, U102.7 (AIN5N)
ADC2_08_AIN5P: J201.28, U102.8 (AIN5P)
ADC2_09_AIN6P: J201.26, U102.9 (AIN6P)
ADC2_10_AIN6N: J201.25, U102.10 (AIN6N)
ADC2_11_AIN7N: J201.23, U102.11 (AIN7N)
ADC2_12_AIN7P: J201.24, U102.12 (AIN7P)
ADC2_17_CS: U18.15 (PF5), U102.17 (CS)
ADC2_29_AIN0P: J201.38, U102.29 (AIN0P)
ADC2_30_AIN0N: J201.37, U102.30 (AIN0N)
ADC2_31_AIN1N: J201.35, U102.31 (AIN1N)
ADC2_32_AIN1P: J201.36, U102.32 (AIN1P)
ADC3_01_AIN2P: J202.14, U103.1 (AIN2P)
ADC3_02_AIN2N: J202.13, U103.2 (AIN2N)
ADC3_03_AIN3N: J202.11, U103.3 (AIN3N)
ADC3_04_AIN3P: J202.12, U103.4 (AIN3P)
ADC3_05_AIN4P: J202.10, U103.5 (AIN4P)
ADC3_06_AIN4N: J202.9, U103.6 (AIN4N)
ADC3_07_AIN5N: J202.7, U103.7 (AIN5N)
ADC3_08_AIN5P: J202.8, U103.8 (AIN5P)
ADC3_09_AIN6P: J202.6, U103.9 (AIN6P)
ADC3_10_AIN6N: J202.5, U103.10 (AIN6N)
ADC3_11_AIN7N: J202.3, U103.11 (AIN7N)
ADC3_12_AIN7P: J202.4, U103.12 (AIN7P)
ADC3_17_CS: U18.14 (PF4), U103.17 (CS)
ADC3_29_AIN0P: J202.18, U103.29 (AIN0P)
ADC3_30_AIN0N: J202.17, U103.30 (AIN0N)
ADC3_31_AIN1N: J202.15, U103.31 (AIN1N)
ADC3_32_AIN1P: J202.16, U103.32 (AIN1P)
ADC4_01_AIN2P: J202.34, U104.1 (AIN2P)
ADC4_02_AIN2N: J202.33, U104.2 (AIN2N)
ADC4_03_AIN3N: J202.31, U104.3 (AIN3N)
ADC4_04_AIN3P: J202.32, U104.4 (AIN3P)
ADC4_05_AIN4P: J202.30, U104.5 (AIN4P)
ADC4_06_AIN4N: J202.29, U104.6 (AIN4N)
ADC4_07_AIN5N: J202.27, U104.7 (AIN5N)
ADC4_08_AIN5P: J202.28, U104.8 (AIN5P)
ADC4_09_AIN6P: J202.26, U104.9 (AIN6P)
ADC4_10_AIN6N: J202.25, U104.10 (AIN6N)
ADC4_11_AIN7N: J202.23, U104.11 (AIN7N)
ADC4_12_AIN7P: J202.24, U104.12 (AIN7P)
ADC4_17_CS: U18.13 (PF3), U104.17 (CS)
ADC4_29_AIN0P: J202.38, U104.29 (AIN0P)
ADC4_30_AIN0N: J202.37, U104.30 (AIN0N)
ADC4_31_AIN1N: J202.35, U104.31 (AIN1N)
ADC4_32_AIN1P: J202.36, U104.32 (AIN1P)
ADC5_01_AIN2P: J203.14, U105.1 (AIN2P)
ADC5_02_AIN2N: J203.13, U105.2 (AIN2N)
ADC5_03_AIN3N: J203.11, U105.3 (AIN3N)
ADC5_04_AIN3P: J203.12, U105.4 (AIN3P)
ADC5_05_AIN4P: J203.10, U105.5 (AIN4P)
ADC5_06_AIN4N: J203.9, U105.6 (AIN4N)
ADC5_07_AIN5N: J203.7, U105.7 (AIN5N)
ADC5_08_AIN5P: J203.8, U105.8 (AIN5P)
ADC5_09_AIN6P: J203.6, U105.9 (AIN6P)
ADC5_10_AIN6N: J203.5, U105.10 (AIN6N)
ADC5_11_AIN7N: J203.3, U105.11 (AIN7N)
ADC5_12_AIN7P: J203.4, U105.12 (AIN7P)
ADC5_17_CS: U18.73 (PB12), U105.17 (CS)
ADC5_19_SCLK: U18.74 (PB13), U105.19 (SCLK), U106.19 (SCLK), U107.19 (SCLK), U108.19 (SCLK)
ADC5_20_DOUT: U18.28 (PC2_C), U105.20 (DOUT), U106.20 (DOUT), U107.20 (DOUT), U108.20 (DOUT)
ADC5_21_DIN: U18.29 (PC3_C), U105.21 (DIN), U106.21 (DIN), U107.21 (DIN), U108.21 (DIN)
ADC5_29_AIN0P: J203.18, U105.29 (AIN0P)
ADC5_30_AIN0N: J203.17, U105.30 (AIN0N)
ADC5_31_AIN1N: J203.15, U105.31 (AIN1N)
ADC5_32_AIN1P: J203.16, U105.32 (AIN1P)
ADC6_01_AIN2P: J203.34, U106.1 (AIN2P)
ADC6_02_AIN2N: J203.33, U106.2 (AIN2N)
ADC6_03_AIN3N: J203.31, U106.3 (AIN3N)
ADC6_04_AIN3P: J203.32, U106.4 (AIN3P)
ADC6_05_AIN4P: J203.30, U106.5 (AIN4P)
ADC6_06_AIN4N: J203.29, U106.6 (AIN4N)
ADC6_07_AIN5N: J203.27, U106.7 (AIN5N)
ADC6_08_AIN5P: J203.28, U106.8 (AIN5P)
ADC6_09_AIN6P: J203.26, U106.9 (AIN6P)
ADC6_10_AIN6N: J203.25, U106.10 (AIN6N)
ADC6_11_AIN7N: J203.23, U106.11 (AIN7N)
ADC6_12_AIN7P: J203.24, U106.12 (AIN7P)
ADC6_17_CS: U18.37 (PA3), U106.17 (CS)
ADC6_29_AIN0P: J203.38, U106.29 (AIN0P)
ADC6_30_AIN0N: J203.37, U106.30 (AIN0N)
ADC6_31_AIN1N: J203.35, U106.31 (AIN1N)
ADC6_32_AIN1P: J203.36, U106.32 (AIN1P)
ADC7_01_AIN2P: J204.14, U107.1 (AIN2P)
ADC7_02_AIN2N: J204.13, U107.2 (AIN2N)
ADC7_03_AIN3N: J204.11, U107.3 (AIN3N)
ADC7_04_AIN3P: J204.12, U107.4 (AIN3P)
ADC7_05_AIN4P: J204.10, U107.5 (AIN4P)
ADC7_06_AIN4N: J204.9, U107.6 (AIN4N)
ADC7_07_AIN5N: J204.7, U107.7 (AIN5N)
ADC7_08_AIN5P: J204.8, U107.8 (AIN5P)
ADC7_09_AIN6P: J204.6, U107.9 (AIN6P)
ADC7_10_AIN6N: J204.5, U107.10 (AIN6N)
ADC7_11_AIN7N: J204.3, U107.11 (AIN7N)
ADC7_12_AIN7P: J204.4, U107.12 (AIN7P)
ADC7_17_CS: U18.36 (PA2), U107.17 (CS)
ADC7_29_AIN0P: J204.18, U107.29 (AIN0P)
ADC7_30_AIN0N: J204.17, U107.30 (AIN0N)
ADC7_31_AIN1N: J204.15, U107.31 (AIN1N)
ADC7_32_AIN1P: J204.16, U107.32 (AIN1P)
ADC8_01_AIN2P: J204.34, U108.1 (AIN2P)
ADC8_02_AIN2N: J204.33, U108.2 (AIN2N)
ADC8_03_AIN3N: J204.31, U108.3 (AIN3N)
ADC8_04_AIN3P: J204.32, U108.4 (AIN3P)
ADC8_05_AIN4P: J204.30, U108.5 (AIN4P)
ADC8_06_AIN4N: J204.29, U108.6 (AIN4N)
ADC8_07_AIN5N: J204.27, U108.7 (AIN5N)
ADC8_08_AIN5P: J204.28, U108.8 (AIN5P)
ADC8_09_AIN6P: J204.26, U108.9 (AIN6P)
ADC8_10_AIN6N: J204.25, U108.10 (AIN6N)
ADC8_11_AIN7N: J204.23, U108.11 (AIN7N)
ADC8_12_AIN7P: J204.24, U108.12 (AIN7P)
ADC8_17_CS: U18.35 (PA1), U108.17 (CS)
ADC8_29_AIN0P: J204.38, U108.29 (AIN0P)
ADC8_30_AIN0N: J204.37, U108.30 (AIN0N)
ADC8_31_AIN1N: J204.35, U108.31 (AIN1N)
ADC8_32_AIN1P: J204.36, U108.32 (AIN1P)
ADC9_01_AIN2P: J205.14, U109.1 (AIN2P)
ADC9_02_AIN2N: J205.13, U109.2 (AIN2N)
ADC9_03_AIN3N: J205.11, U109.3 (AIN3N)
ADC9_04_AIN3P: J205.12, U109.4 (AIN3P)
ADC9_05_AIN4P: J205.10, U109.5 (AIN4P)
ADC9_06_AIN4N: J205.9, U109.6 (AIN4N)
ADC9_07_AIN5N: J205.7, U109.7 (AIN5N)
ADC9_08_AIN5P: J205.8, U109.8 (AIN5P)
ADC9_09_AIN6P: J205.6, U109.9 (AIN6P)
ADC9_10_AIN6N: J205.5, U109.10 (AIN6N)
ADC9_11_AIN7N: J205.3, U109.11 (AIN7N)
ADC9_12_AIN7P: J205.4, U109.12 (AIN7P)
ADC9_17_CS: U18.64 (PE11), U109.17 (CS)
ADC9_29_AIN0P: J205.18, U109.29 (AIN0P)
ADC9_30_AIN0N: J205.17, U109.30 (AIN0N)
ADC9_31_AIN1N: J205.15, U109.31 (AIN1N)
ADC9_32_AIN1P: J205.16, U109.32 (AIN1P)
ADC10_01_AIN2P: J205.34, U110.1 (AIN2P)
ADC10_02_AIN2N: J205.33, U110.2 (AIN2N)
ADC10_03_AIN3N: J205.31, U110.3 (AIN3N)
ADC10_04_AIN3P: J205.32, U110.4 (AIN3P)
ADC10_05_AIN4P: J205.30, U110.5 (AIN4P)
ADC10_06_AIN4N: J205.29, U110.6 (AIN4N)
ADC10_07_AIN5N: J205.27, U110.7 (AIN5N)
ADC10_08_AIN5P: J205.28, U110.8 (AIN5P)
ADC10_09_AIN6P: J205.26, U110.9 (AIN6P)
ADC10_10_AIN6N: J205.25, U110.10 (AIN6N)
ADC10_11_AIN7N: J205.23, U110.11 (AIN7N)
ADC10_12_AIN7P: J205.24, U110.12 (AIN7P)
ADC10_14_REFIN: C20.1, U2.1 (VBIAS), U101.14 (REFIN), U102.14 (REFIN), U103.14 (REFIN), U104.14 (REFIN), U105.14 (REFIN), U106.14 (REFIN), U107.14 (REFIN), U108.14 (REFIN), U109.14 (REFIN), U110.14 (REFIN), U111.14 (REFIN), U112.14 (REFIN), U113.14 (REFIN), U114.14 (REFIN), U115.14 (REFIN), U116.14 (REFIN)
ADC10_15_AVDD: C4.1, C7.1, C10.1, C13.1, C17.1, C22.1, C27.1, C32.1, C77.1, C80.1, C83.1, C86.1, C89.1, C92.1, C95.1, C98.1, C101.1, J201.20, J201.40, J202.20, J202.40, J203.20, J203.40, J204.20, J204.40, J205.20, J205.40, J206.20, J206.40, J207.20, J207.40, J208.20, J208.40, J303.4, U6.5 (OUT), U101.15 (AVDD), U102.15 (AVDD), U103.15 (AVDD), U104.15 (AVDD), U105.15 (AVDD), U106.15 (AVDD), U107.15 (AVDD), U108.15 (AVDD), U109.15 (AVDD), U110.15 (AVDD), U111.15 (AVDD), U112.15 (AVDD), U113.15 (AVDD), U114.15 (AVDD), U115.15 (AVDD), U116.15 (AVDD)
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

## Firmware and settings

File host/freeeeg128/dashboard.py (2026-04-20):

"""FastAPI quality dashboard: live operator view of a FreeEEG128 LSL stream.

- Pulls samples from an LSL outlet (any source: the real device, the
  synthetic source, or a replay file — they all look the same to LSL).
- Maintains a 2-second rolling buffer per channel.
- Computes per-channel broadband-RMS, alpha-band RMS, dominant frequency,
  and a green / yellow / red / grey quality code once per second.
- Serves a single-page browser UI at ``/`` plus an SSE stream at
  ``/events`` that pushes JSON updates so the page can re-render live
  without JS-frameworks.

Run from Pi:
    python3 -m freeeeg128.dashboard --port 8000
Open:
    http://<pi-hostname>.local:8000/

Inspired by Vivancos 2023 §3.1 paper's green/red PSD dashboard.
"""

from __future__ import annotations

import argparse
import asyncio
import json
import threading
import time
from collections import deque
from contextlib import asynccontextmanager
from pathlib import Path

import numpy as np
from fastapi import FastAPI
from fastapi.responses import HTMLResponse, StreamingResponse
from pylsl import StreamInlet, resolve_byprop

from . import quality


# --------------------------------------------------------------------------- #
# Background LSL thread: keeps the rolling buffer and per-channel quality up
# to date.  Main thread serves HTTP and snapshots the latest state.
# --------------------------------------------------------------------------- #

class DashState:
    def __init__(self, window_s: float = 2.0) -> None:
        self.window_s = window_s
        self.connected = False
        self.stream_name = ""
        self.n_channels = 0
        self.sample_rate = 0.0
        self.channel_labels: list[str] = []
        self.buffer: np.ndarray | None = None   # (C, N)
        self.buf_len: int = 0
        self.samples_total = 0
        self.drops_total = 0
        self.packets_rx = 0
        self.last_lsl_ts = 0.0
        self.started_at = time.time()
        self.quality: list[quality.QualityResult] = []
        self.lock = threading.Lock()
        self.stop_event = threading.Event()

    def snapshot(self) -> dict:
        with self.lock:
            return {
                "connected": self.connected,
                "stream_name": self.stream_name,
                "n_channels": self.n_channels,
                "sample_rate": self.sample_rate,
                "channel_labels": self.channel_labels,
                "samples_total": self.samples_total,
                "drops_total": self.drops_total,
                "packets_rx": self.packets_rx,
                "uptime_s": time.time() - self.started_at,
                "quality": [
                    {
                        "code": int(q.code),
                        "rms": round(q.broadband_uv_rms, 3),
                        "alpha": round(q.alpha_uv_rms, 3),
                        "dominant": round(q.dominant_hz, 2),
                    }
                    for q in self.quality
                ],
            }


def _lsl_reader_thread(state: DashState, stream_name: str,
                       resolve_timeout: float = 5.0) -> None:
    streams = resolve_byprop("name", stream_name, timeout=resolve_timeout)
    if not streams:
        with state.lock:
            state.connected = False
        return
    inlet = StreamInlet(streams[0], max_buflen=360)
    info = inlet.info()
    n_ch = info.channel_count()
    sr = info.nominal_srate() or 250.0
    buf_len = max(1, int(sr * state.window_s))
    buf = np.zeros((n_ch, buf_len), dtype=np.float32)
    write_idx = 0
    samples_total = 0

    # Extract channel labels if present
    labels: list[str] = []
    try:
        ch = info.desc().child("channels").child("channel")
        for _ in range(n_ch):
            labels.append(ch.child_value("label") or f"ch{len(labels):03d}")
            ch = ch.next_sibling()
    except Exception:
        labels = [f"ch{i:03d}" for i in range(n_ch)]

    with state.lock:
        state.connected = True
        state.stream_name = stream_name
        state.n_channels = n_ch
        state.sample_rate = sr
        state.channel_labels = labels
        state.buffer = buf
        state.buf_len = buf_len

    last_assess = 0.0
    while not state.stop_event.is_set():
        samples, _ts = inlet.pull_chunk(timeout=0.1, max_samples=250)
        if samples:
            arr = np.asarray(samples, dtype=np.float32).T  # (C, N)
            n = arr.shape[1]
            # Ring-buffer write
            end = write_idx + n
            if end <= buf_len:
                buf[:, write_idx:end] = arr
            else:
                first = buf_len - write_idx
                buf[:, write_idx:] = arr[:, :first]
                buf[:, : n - first] = arr[:, first:]
            write_idx = (write_idx + n) % buf_len
            samples_total += n
            with state.lock:
                state.samples_total = samples_total
                state.packets_rx += 1

        # Re-assess quality at most once per second
        now = time.monotonic()
        if now - last_assess >= 1.0 and samples_total >= buf_len:
            last_assess = now
            # Assemble a contiguous view
            ordered = np.concatenate(
                [buf[:, write_idx:], buf[:, :write_idx]], axis=1
            )
            q = quality.assess_array(ordered, sr)
            with state.lock:
                state.quality = q


# --------------------------------------------------------------------------- #
# HTTP layer
# --------------------------------------------------------------------------- #

_HTML = """<!doctype html>
<html lang="en"><head>
<meta charset="utf-8">
<title>FreeEEG128 — quality monitor</title>
<style>
 body { font-family: -apple-system, 'SF Mono', Menlo, monospace; margin: 1rem; background: #0e1116; color: #c9d1d9; }
 h1 { margin: 0 0 .5rem 0; font-size: 1.1rem; color: #58a6ff; }
 .topbar { display: flex; gap: 1rem; flex-wrap: wrap; margin-bottom: .75rem; font-size: .85rem; }
 .topbar span { background:#161b22; padding:.25rem .6rem; border-radius:4px; }
 .grid { display: grid; grid-template-columns: repeat(16, 1fr); gap: 2px; }
 .cell { aspect-ratio: 1/1; border-radius: 2px; font-size: 9px; text-align: center;
         display: flex; flex-direction: column; justify-content: center; align-items: center;
         color: #111; cursor: help; overflow: hidden; padding: 1px; }
 .q0 { background: #33cc66; } /* green  */
 .q1 { background: #e3b341; } /* yellow */
 .q2 { background: #e5534b; color:#fff; } /* red */
 .q3 { background: #30363d; color:#999; } /* grey */
 .cell small { font-size: 8px; opacity: .75; }
 .legend { display:flex; gap:.75rem; margin-top:.75rem; font-size:.8rem; }
 .legend span.sw { display:inline-block; width:10px; height:10px; margin-right:.3rem; border-radius:2px; vertical-align: middle; }
 footer { margin-top: 1rem; font-size: .75rem; color: #6e7681; }
</style>
</head><body>
<h1>FreeEEG128 — quality monitor</h1>
<div class="topbar">
 <span id="state">connecting…</span>
 <span id="sr"></span>
 <span id="nch"></span>
 <span id="samples"></span>
 <span id="drops"></span>
 <span id="uptime"></span>
</div>
<div class="grid" id="grid"></div>
<div class="legend">
 <span><span class="sw q0"></span>good (RMS &gt; 0.5 µV)</span>
 <span><span class="sw q1"></span>marginal</span>
 <span><span class="sw q2"></span>bad / flat / saturated</span>
 <span><span class="sw q3"></span>no data yet</span>
</div>
<footer>Live at 1 Hz via SSE.  Green/red gate follows Vivancos 2023 §3.1.</footer>
<script>
const grid = document.getElementById('grid');
const es = new EventSource('/events');
es.onmessage = (ev) => {
  const s = JSON.parse(ev.data);
  document.getElementById('state').textContent = s.connected ? ('● ' + s.stream_name) : '○ waiting for outlet';
  document.getElementById('state').style.color = s.connected ? '#33cc66' : '#e5534b';
  document.getElementById('sr').textContent = s.sample_rate.toFixed(0) + ' Hz';
  document.getElementById('nch').textContent = s.n_channels + ' ch';
  document.getElementById('samples').textContent = s.samples_total.toLocaleString() + ' samples';
  document.getElementById('drops').textContent = s.drops_total + ' drops';
  document.getElementById('uptime').textContent = Math.floor(s.uptime_s) + ' s up';
  if (grid.childElementCount !== s.n_channels) {
    grid.innerHTML = '';
    for (let i = 0; i < s.n_channels; i++) {
      const d = document.createElement('div');
      d.className = 'cell q3';
      d.id = 'c' + i;
      grid.appendChild(d);
    }
  }
  for (let i = 0; i < s.quality.length; i++) {
    const c = document.getElementById('c' + i);
    if (!c) continue;
    const q = s.quality[i];
    c.className = 'cell q' + q.code;
    const label = (s.channel_labels[i] || ('ch' + i)).replace(/^ch/, '');
    c.innerHTML = label + '<small>' + q.rms.toFixed(1) + '</small>';
    c.title = (s.channel_labels[i] || 'ch' + i) + '\\nRMS ' + q.rms.toFixed(2) + ' µV'
            + '\\nα-RMS ' + q.alpha.toFixed(2) + ' µV'
            + '\\ndominant ' + q.dominant.toFixed(1) + ' Hz';
  }
};
</script>
</body></html>
"""


def create_app(state: DashState) -> FastAPI:
    app = FastAPI(title="FreeEEG128 quality monitor")

    @app.get("/", response_class=HTMLResponse)
    async def index() -> HTMLResponse:  # noqa: D401
        return HTMLResponse(_HTML)

    @app.get("/events")
    async def events():  # noqa: D401
        async def gen():
            while True:
                s = state.snapshot()
                yield f"data: {json.dumps(s)}\n\n"
                await asyncio.sleep(1.0)
        return StreamingResponse(gen(), media_type="text/event-stream")

    @app.get("/state")
    async def full_state():
        return state.snapshot()

    return app


def main() -> None:
    ap = argparse.ArgumentParser()
    ap.add_argument("--stream", default="FreeEEG128", help="LSL stream name to bind to")
    ap.add_argument("--port", type=int, default=8000)
    ap.add_argument("--host", default="0.0.0.0")
    ap.add_argument("--window-s", type=float, default=2.0,
                    help="rolling window (s) for quality assessment")
    args = ap.parse_args()

    import uvicorn

    state = DashState(window_s=args.window_s)
    reader = threading.Thread(target=_lsl_reader_thread,
                              args=(state, args.stream),
                              daemon=True, name="lsl-reader")
    reader.start()

    app = create_app(state)
    try:
        uvicorn.run(app, host=args.host, port=args.port, log_level="warning")
    finally:
        state.stop_event.set()


if __name__ == "__main__":
    main()

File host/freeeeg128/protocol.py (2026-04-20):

"""Wire-protocol encode/decode for FreeEEG128 framed packets.

Implements docs/packet-format.md v1.  Pure Python — no dependencies beyond
the standard library.  Designed so the same code parses synthetic streams
today and the real STM32H743 firmware's USB-CDC stream tomorrow.
"""

from __future__ import annotations

import struct
import zlib
from dataclasses import dataclass
from enum import IntEnum

MAGIC = b"\x46\x45"  # "FE"
HDRLEN_V1 = 22
PROTO_VERSION = 0x01


class PacketType(IntEnum):
    EEG_FRAME    = 0x01
    IMU_FRAME    = 0x02
    STATUS       = 0x03
    IMPEDANCE    = 0x04
    LOG          = 0x05
    TRIGGER      = 0x06   # reserved for future
    COMMAND      = 0x10
    COMMAND_ACK  = 0x11
    CAPABILITIES = 0x20
    BOOT_BANNER  = 0x7F


class CmdId(IntEnum):
    START             = 0x01
    STOP              = 0x02
    GET_CAPS          = 0x03
    SET_RATE          = 0x04
    SET_GAIN          = 0x05
    SET_MUX           = 0x06
    LEAD_OFF_START    = 0x07
    LEAD_OFF_STOP     = 0x08
    SET_IMU_RATE      = 0x09
    SD_BEGIN          = 0x0A
    SD_END            = 0x0B
    SET_TRIGGER_MODE  = 0x0C
    GET_STATUS        = 0x0D
    SYNC_TIME         = 0x0E
    SELF_TEST         = 0x0F
    REBOOT            = 0x80
    REBOOT_DFU        = 0x81
    NOP               = 0xFF


# ---------------------------------------------------------------------------
# Framing
# ---------------------------------------------------------------------------

_HDR_STRUCT = struct.Struct("<2sBBHIIQ")  # magic, type, ver, hdrlen, pktlen, seq, ts_us
assert _HDR_STRUCT.size == HDRLEN_V1


@dataclass(frozen=True)
class Packet:
    """A fully framed and validated packet."""
    ptype: int
    version: int
    seq: int
    ts_us: int
    payload: bytes

    def to_bytes(self) -> bytes:
        pktlen = len(self.payload)
        hdr = _HDR_STRUCT.pack(
            MAGIC, self.ptype, self.version, HDRLEN_V1, pktlen, self.seq, self.ts_us,
        )
        body = hdr + self.payload
        crc = zlib.crc32(body) & 0xFFFFFFFF
        return body + struct.pack("<I", crc)


def encode(ptype: int, seq: int, ts_us: int, payload: bytes,
           version: int = PROTO_VERSION) -> bytes:
    """Encode one framed packet."""
    return Packet(ptype, version, seq, ts_us, payload).to_bytes()


class ParseError(Exception):
    pass


class PacketParser:
    """Streaming byte-oriented parser that recovers from resync events.

    Feed bytes via ``feed()``; it yields complete ``Packet`` instances as
    they become available.  Tracks a ``drop_count`` incremented on any CRC
    failure or sequence-number gap.
    """

    def __init__(self) -> None:
        self._buf = bytearray()
        self._expected_seq: int | None = None
        self.drop_count = 0
        self.byte_count = 0
        self.packet_count = 0

    def feed(self, data: bytes) -> list[Packet]:
        """Append bytes; return any complete packets recovered."""
        self._buf.extend(data)
        self.byte_count += len(data)
        out: list[Packet] = []
        while True:
            pkt = self._try_one()
            if pkt is None:
                break
            out.append(pkt)
        return out

    def _try_one(self) -> Packet | None:
        buf = self._buf
        # Need at least a header to make progress
        while len(buf) >= HDRLEN_V1 and buf[:2] != MAGIC:
            # Scan forward until we find the magic
            idx = buf.find(MAGIC[0:1], 1)
            if idx < 0:
                # No MAGIC[0] anywhere; discard everything but keep the last byte in case
                # it's the start of a future MAGIC
                del buf[:-1]
                return None
            # Drop everything before the candidate MAGIC[0]
            del buf[:idx]
            self.drop_count += 1
        if len(buf) < HDRLEN_V1:
            return None

        try:
            magic, ptype, version, hdrlen, pktlen, seq, ts_us = _HDR_STRUCT.unpack_from(buf, 0)
        except struct.error:
            return None

        if magic != MAGIC:
            # shouldn't happen after the scan above, but be defensive
            del buf[:1]
            self.drop_count += 1
            return None

        if hdrlen != HDRLEN_V1:
            # future protocol version we don't understand — skip the byte and resync
            del buf[:1]
            self.drop_count += 1
            return None

        total_len = HDRLEN_V1 + pktlen + 4
        if len(buf) < total_len:
            return None  # need more bytes

        body = bytes(buf[:HDRLEN_V1 + pktlen])
        crc_bytes = bytes(buf[HDRLEN_V1 + pktlen : total_len])
        got_crc, = struct.unpack("<I", crc_bytes)
        want_crc = zlib.crc32(body) & 0xFFFFFFFF
        if got_crc != want_crc:
            # CRC fail: drop the first byte and try to resync
            del buf[:1]
            self.drop_count += 1
            return None

        # CRC ok: consume the full packet
        del buf[:total_len]
        payload = body[HDRLEN_V1:]

        if self._expected_seq is not None and seq != self._expected_seq:
            gap = (seq - self._expected_seq) & 0xFFFFFFFF
            self.drop_count += gap
        self._expected_seq = (seq + 1) & 0xFFFFFFFF

        self.packet_count += 1
        return Packet(ptype=ptype, version=version, seq=seq, ts_us=ts_us, payload=payload)


# ---------------------------------------------------------------------------
# EEG frame payload
# ---------------------------------------------------------------------------

_EEG_HDR = struct.Struct("<HHHH16s")  # n_ch, n_smp, flags, sr_hz, adc_status[16]


def encode_eeg_frame(samples_u24: bytes, n_ch: int, n_smp: int,
                     sr_hz: int, flags: int = 0,
                     adc_status: bytes = b"\x00" * 16) -> bytes:
    """Pack an EEG_FRAME payload from raw big-endian int24 samples.

    ``samples_u24`` must be channel-major: ch0_smp0, ch0_smp1, …, ch1_smp0, …
    with each sample as 3 big-endian bytes (ADS131M08 native order).
    """
    if len(adc_status) != 16:
        raise ValueError("adc_status must be 16 bytes")
    expected = n_ch * n_smp * 3
    if len(samples_u24) != expected:
        raise ValueError(f"samples_u24 length {len(samples_u24)} != n_ch×n_smp×3 = {expected}")
    hdr = _EEG_HDR.pack(n_ch, n_smp, flags, sr_hz, adc_status)
    return hdr + samples_u24
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

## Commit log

2026-04-17 Initial commit: FreeEEG128 design audit, roadmap, host stack, and synthesis paper
    Contents:
    - Hardware audit and STM32 peripheral inventory of the NeuroIDSS FreeEEG128-alpha
    (HARDWARE.md, PERIPHERALS.md).
    - Open-hardware EEG landscape and feature-matrix comparison with Black et al. 2017
    (Open Ephys + EEG) as the primary 128-channel benchmark (COMPARISON.md).
    - Enclosure, battery, connector, and cable-management plan for the belt-pack beta
    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
2026-04-17 Add g.tec g.Pangolin as VHD-EEG SOTA reference + 1024-ch context
    Positions FreeEEG128 against the current very-high-density EEG frontier:
    - g.Pangolin (up to 1024 channels via 4× g.HIamp, flex-PCB active-wet grids
    at 8.6 mm inter-electrode distance, 5.9 mm diameter, on-grid pre-amp,
    24-bit, 38.4 kHz sample rate) is the commercial VHD-EEG state-of-the-art
    as of 2024.
    - Schreiner et al. 2024 (Sci Rep 14, doi:10.1038/s41598-024-57167-y)
    demonstrates 95.2% central-sulcus anterior/posterior classification via
    SSEP phase reversal — comparable to invasive ECoG.
    - Supporting theoretical/methodological refs: Shirazi, Onton & Makeig
    2025 (cortex-to-scalp projection from UHD ECoG); Liu,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
2026-04-18 Import upstream KiCAD project, upgrade to KiCAD 10 format
    Upstream: NeuroIDSS/FreeEEG128-alpha (September 2021, KiCAD 5.99, AGPL-3.0).
    Converted all 32 hierarchical schematics and the 4-layer PCB to KiCAD 10.0.1
    format via kicad-cli sch upgrade / pcb upgrade. No schematic or layout
    changes — this commit is purely the format migration so the project can be
    edited in modern KiCAD.
    Regenerated fab artefacts:
    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
    [5031821852.step, 5031821852.stp, ACCEL&GYRO.kicad_sch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]
2026-04-18 Add pcb/CHANGES-beta.md — beta-rev design plan-of-record
    Enumerates every beta-rev schematic/layout change with where it lives,
    what gets added/swapped, MPNs, layout impact, and sequencing. Settled
    items (STM32H743 retained, ESP32-S3 replaced by Pi Zero 2W companion)
    noted; open decisions for user flagged in §10.
2026-04-20 bench_brainflow: skip gracefully on aarch64 (wheel ships x86-64 libs)
    BrainFlow 5.21 PyPI wheel for aarch64 contains x86-64 .so files instead
    of aarch64. On Pi Zero 2W (and any aarch64 host) loading
    libBoardController.so fails with ELF class mismatch. The bench now
    detects this and emits brainflow.status=0 skipped_aarch64_wheel_bug.
    The BrainFlow bench was only a pre-validation stand-in; the real
    FreeEEG128 data path is USB-CDC → pyserial → LSL outlet and does not
    depend on BrainFlow working. Fix deferred to either (a) upstream
    wheel fix, or (b) build from source on the Pi (~30 min).
2026-04-20 Pi Zero 2W first-run benchmark numbers
    First bring-up of the Pi Zero 2W parallel track. Ran the full host/
    benchmark suite on bare-install Raspberry Pi OS Lite 64-bit (Trixie-
    era) with numpy 2.x + scipy 1.17 + pylsl 1.18 (from pip + extracted
    liblsl 1.17.5 jammy arm64 deb) + mne 1.12 + pyserial 3.5.
    Key numbers:
    - FFT 128x25000 complex64: 1522 ms (reasonable for Cortex-A53)
    - LSL 100ms-batch push+pull: p50=12.8ms p95=12.9ms, 6.7x real-time
    - MNE FIR bandpass 1-40Hz on 128-ch x 5-min: 5.46 s
    - BrainFlow SYNTHETIC_BOARD: skipped (upstream aarch64 wheel ships
    x86-64 libs; not on real-device critical path)
    One concerning datapoint: LSL max latency = 1010 ms (one ~1 s stall
    per 60 s run).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
2026-04-20 Wire protocol spec + Python package: protocol, synthetic source, LSL bridge
    - docs/packet-format.md v1: framed-packet wire protocol (MAGIC, seq, ts_us,
    CRC32), EEG_FRAME / IMU_FRAME / STATUS / IMPEDANCE / CAPABILITIES /
    BOOT_BANNER types, self-describing capability descriptor with channel
    labels on the stream.
    - docs/command-protocol.md v1: host->device command set (START/STOP,
    SET_RATE, SET_GAIN, SET_MUX, LEAD_OFF_*, SD_BEGIN/END, SYNC_TIME,
    SELF_TEST, REBOOT_DFU, etc.), ACK structure, error codes, protocol flow.
    - host/freeeeg128/protocol.py: struct-based encoder + streaming
    byte-oriented parser with resync, CRC validation, drop counting.
    - host/freeeeg128/synthetic.py: pure-Py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
    [lsl_bridge.py, protocol.py, synth_to_lsl.py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]
2026-04-20 bench_lsl: add warmup phase; drop first-pull handshake from max-latency
    Previous bench showed a suspicious *exact* 1010 ms 'max' latency across
    independent runs. That's the inlet.pull_chunk(timeout=1.0) blocking on
    the very first iteration while the LSL inlet is still completing its
    handshake with the outlet. Not representative of steady-state latency.
    Warmup pushes 100 samples and drains before the timed loop starts.
    Timed loop's pull timeout tightened from 1.0s to 0.5s so any real
    anomaly isn't masked.
2026-04-20 host: LSL recorder + FIFF/BIDS writer
    - host/freeeeg128/recorder.py: LSLRecorder drains a running LSL outlet
    into an in-memory buffer, writes out FIFF (via mne) and BIDS-EEG (via
    mne-bids). Units: µV in LSL, converted to V for MNE.
    - host/scripts/record_session.py: CLI that connects to the 'FreeEEG128'
    LSL stream, records for a fixed duration, writes timestamped FIFF +
    BIDS dataset. Runs alongside synth_to_lsl.py for pre-hardware
    testing.
    [record_session.py, recorder.py]
2026-04-20 Pipeline smoke test + README docs for end-to-end hardware-free flow
    - host/scripts/pipeline_smoketest.sh: one-shot end-to-end test that
    launches the synthetic source, records 20 s, validates FIFF + BIDS
    outputs are non-empty. Useful as a regression check and as the
    reference for what the real-device pipeline will look like.
    - host/README.md: documents the full pipeline now that it works on
    the Pi. Validated 4996/5000 samples captured on a 20 s 128-ch ×
    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
2026-04-20 host: quality dashboard (FastAPI + SSE), pyserial + replay byte-sources
    freeeeg128/quality.py
    Per-channel signal-quality classifier. GOOD / MARGINAL / BAD / MISSING
    based on broadband RMS + alpha-band (8-14 Hz) RMS + saturation check.
    Mirrors Vivancos 2023 §3.1 green/red PSD gate.
    freeeeg128/dashboard.py
    FastAPI web UI. Background thread maintains a 2 s rolling buffer from
    an LSL outlet, assesses quality @ 1 Hz, serves a single-page HTML
    renderer + SSE stream at /events. Renders 128 channels as a 16x8
    colour grid with per-cell tooltips showing RMS, alpha-RMS, and
    dominant frequency.
    freeeeg128/serial_source.py
    pyserial byte-source adapter. Drop-in re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
    [dashboard.py, quality.py, replay.py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]
2026-04-20 tests: pyserial pty-loopback + replay file round-trip
    - test_replay_from_file: 100-packet round-trip through replay.iter_bytes.
    - test_serial_loopback_via_pty: raw-mode pty pair, writer thread pushes
    a synthetic packet into the parent end, serial_source.iter_bytes
    reads it from the child, parser recovers it. Smoke-level proof of the
    adapter plumbing. Real-device byte rates are validated by live
    pipeline runs, not by stressing the Linux pty kernel buffer here.
    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
2026-04-21 pcb: fab submission packet — FAB-SUBMISSION.md + MPN BOM + gerber zip
    pcb/FAB-SUBMISSION.md
    Cover letter / checklist / decision log for submitting the current
    KiCAD-10-upgraded alpha design to a fab + SMT assembly house.
    Section-by-section: file inventory, board basics, BOM audit with
    2026-availability flags (what's active / lead-time-critical / must
    replace), six open decisions with recommended defaults, fab house
    comparison with quotes, pre-submission checklist, post-submission
    timeline, recommendation.
    Explicitly frames this packet as *alpha-refreshed*, NOT the beta rev.
    Micro-B connectors stay until CHANGES-beta.md §1.1 USB-C swap.
    pcb/out/bom-202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
    [bom-2021-with-mpns.csv]
2026-04-21 pcb: JLCPCB-format BOM + CPL; fix pos.csv units (mm, was inches)
    - pcb/out/pos.csv re-exported with --units mm from the NUC. The
    earlier regeneration used kicad-cli's default (inches), producing
    coordinates off by 25.4x that broke JLCPCB's parser.
    - pcb/out/bom-jlcpcb.csv: 35 rows in JLCPCB's expected column format
    (Comment, Designator, Footprint, LCSC Part #, MPN).
    - pcb/out/cpl-jlcpcb.csv: 162 rows in JLCPCB's expected column format
    (Designator, Mid X, Mid Y, Layer, Rotation).
    - host/scripts/bom_to_jlcpcb.py, pos_to_jlcpcb.py: reproducible
    transforms from upstream 2021 BOM + KiCAD 10 CPL.
    [bom-jlcpcb.csv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]
2026-04-21 docs: integrate Cardona-Alvarez et al. 2023 OpenBCI-framework paper
    Paper: https://doi.org/10.3390/s23073763 (Sensors 23:3763). Most detailed
    published architecture reference for an open-hardware BCI framework.
    Key takeaways integrated:
    - REFERENCES.md [4]: richer annotation — Raspberry Pi acquisition server,
    three-layer driver design, Kafka distributed compute, LDR marker sync,
    benchmarked latency/jitter, documented Cyton+Daisy interleaving artifact.
    Open-source URLs: UN-GCPDS/openbci-stream, UN-GCPDS/BCI-framework,
    docs.bciframework.org.
    - COMPARISON.md new section 'Lessons from Cardona-Alvarez 2023': what they
    built, benchmarking methodology table we can copy (Table 6), th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
2026-04-21 docs + paper: cEEGrid + Fastball form-factor variant (FreeEEG-Ear)
    Paper source: Knierim, Berger & Reali 2021, Brain-Computer Interfaces,
    doi:10.1080/2326263X.2021.1972633. Open-hardware ADS1299-based amplifier
    with cEEGrid around-the-ear flex-PCB electrodes for concealed EEG.
    Captures an orthogonal product direction on the same architecture: a
    low-channel (~10-20 ch) around-the-ear device paired with the Fastball
    paradigm (Stothart et al. 2017 Neuropsychologia, 2021 Brain) for
    passive, <3-minute clinical screening of dementia, stroke, paediatric
    populations where instruction-following fails.
    Architecturally same STM32H743 + ADS131M08 + framed-packet + Pi-Zero
    companion pattern; delta is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

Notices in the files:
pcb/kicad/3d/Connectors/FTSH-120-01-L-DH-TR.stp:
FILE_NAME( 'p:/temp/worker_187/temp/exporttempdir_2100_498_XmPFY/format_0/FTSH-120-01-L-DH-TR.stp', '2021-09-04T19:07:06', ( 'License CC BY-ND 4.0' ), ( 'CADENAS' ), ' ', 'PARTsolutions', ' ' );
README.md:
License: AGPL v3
